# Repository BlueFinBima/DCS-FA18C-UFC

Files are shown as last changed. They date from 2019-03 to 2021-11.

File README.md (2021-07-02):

# DCS-FA18C-UFC
### This is a hardware and software project to build an Up Front Controller for the DCS F/A-18C Hornet
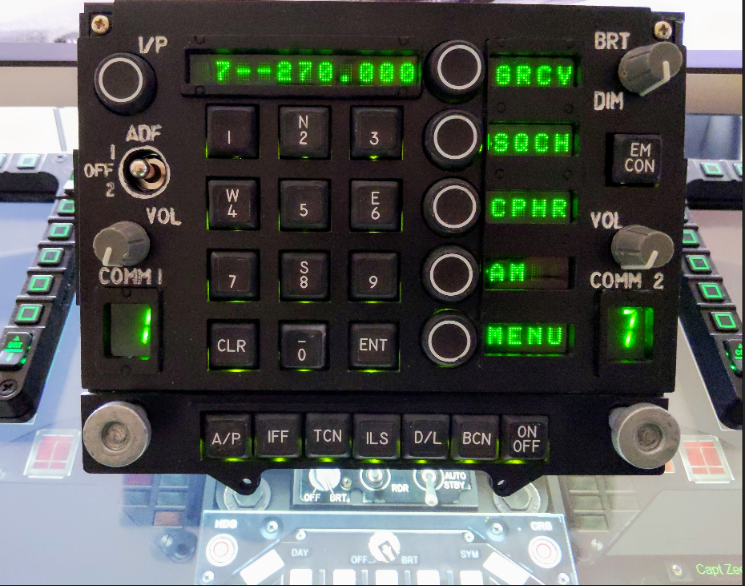
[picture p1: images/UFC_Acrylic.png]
Hornet UFC with the Early 2020 Acrylic Case

### Notes

The HT16K33 isn't too difficult to find, and can be picked up quite cheaply on AliExpress if you are prepared to wait.  The DLG2416 displays are quite expensive from 
typical vendors, however hunting around on ebay etc might result in more affordable sources.  They have a fixed character set which is unfortunate, however they remain useable and pleasing alternative to the 16 segment displays which the actual UFC requires.  If didn't manage to find suitable 16 segment displays of a physical size to work with this 
project.  The comms channel indicators are 16 segment displays (be careful not to buy 14 segment) but unfortunately I was unable to find displays which were not slanted - for me a minor issue.
* The ESP32 boards come in all sorts of shapes and sizes, and my controller board needs
a particular type of 38-pin board and I found to my cost that there were several boards with different widths.  I would expect [these boards](https://www.amazon.co.uk/AZDelivery-NodeMcu-CP2102-Development-including/dp/B074RGW2VQ/) to be the correct size.
* The green 16 segment LED displays now (2020) seem to be very hard to acquire.
* R2 and R5 on the controller board should only be installed as a last resort of the I2C is not stable without them
* The PCF8575 is a PCF8575PWR (TSSOP)
* D1 and D2 are BAT54CDW and not BAT54TW

### The Story
I would love to have a full Simpit for every aircraft – who
wouldn’t – but space / time / money all conspire against this.  I personally
feel that there is more immersion from the sensation of real switches, knobs
etc, but compromises are part of life.

I wanted a mix of virtual cockpit and some real devices so I
wrote a native F/A-18C interface for Helios, and I started a project to create
a hardware Up Front Controller.  This is what I am presenting here.   While the
3D printed UFC enclosure is very rough, hopefully you’ll get the idea of what I
am doing.  The UFC just has power going to it, and it has the potential to
drive future parts of the cockpit via i2c (I am aware of the limitations and
potential problems with the approach of using i2c, but it seems reliable in my
set up).   The UFC is controlled by an ESP32 board to get me the direct pins
and interrupts that I needed for the encoders.  Because there is only a single
power connecter to the UFC, it means that it can be removed from the set up
extremely quickly.  Likewise, the Thrustmaster Cougar MFDs are also very easy
to remove as they simply hang from the top of the screen, primarily to allow
hiding of the USB cables.  I rotated the rocker switches and 3D printed the
hangers so the MFDs sit over the top corners of the 23 inch Dell touch screen.

The UFC itself is pretty simple using DLG2416 displays (I
like the dots).  Unfortunately these do not have any programmable characters,
but the result is OK IMHO.  I would have preferred  16 and 7 segment displays,
but I could not find suitable devices.  The Comm Channel displays are 16
segment LED displays driven by the same HT16K33 that reads the keys and
switches.  Other things I would change if I ever revised the UFC design would
be to replace the 2 x volumes and the brightness knob with potentiometers and
put an i2c ADC onto the board – but I am happy enough with the encoders in the
current design that I’m not planning to do this.

I’m going to put a third Cougar MFD in for the AMPCD, but
I’m still considering how I can do this while keeping the mounting discrete.

#### 2020 Project Update
With two inidividuals (that I know of) successfully recreating this project, I chose to revisit
the facial.  I purchased a small SLA 3D printer which allowed me to print smaller key caps, and 
I was able to paint and use my 2.5W LED Laser to label these.  I also created new comm channel
selectors, as well as more harmonious knobs (ie not Mil Spec accurate) for the UFC.
My LED laser will not touch acrylic other than black, so the facia was cut from that material and 
white polystyrene sheet was then glued to the surface, and painted black.  The LED laser was then 
used to create the lettering.  While all of this is an improvement, I have to confess to not being 
very happy with this.   This is in part why the GitHub project has not been updated with these changes.
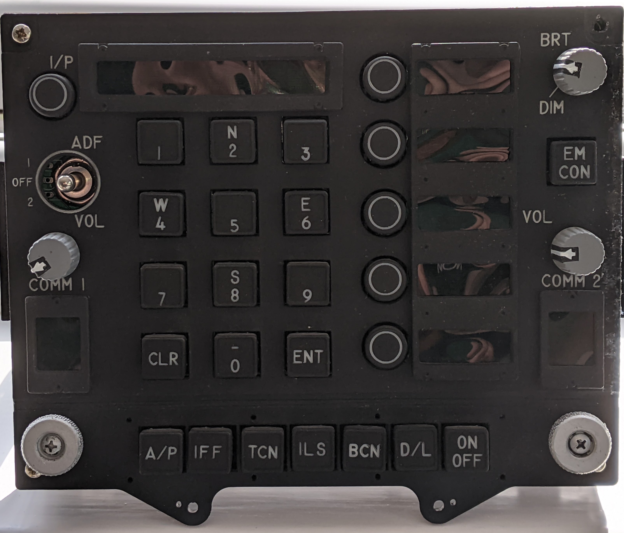
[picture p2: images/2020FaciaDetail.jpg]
Hornet UFC with Late 2020 Acrylic Facia


#### Thoughts about the future (July 2021)
Are there going to be further revisions to this project?  Well maybe.  I am considering a V3, primarily 
to see if I can improve the visuals of the displays, and to see if I can gain some level of crossover with
the AV-8B which has a similar UFC.  DLG2416's are expensive and difficult to get hold of.  16 segment LED displays
are also out of fashion, and green ones seem extremely rare.  I have created Eagle drawings for discrete 0603 / 0402
LED displays which can be charlieplexed and might be coaxed into looking like the 16-segment displays used in the 
real UFC.  I just need to finalise these plans, and pluck up the courage to use a PCBA service to build a prototype 
(I have neither the patience nor the skill to solder the volume to LEDs needed).  If I get around to getting a 
display prototyped *AND* I can work out how to make it look fit for purpose, then I will almost certainly begin
some work on a V3 of this UFC.

Controlling the very large number of LEDs will also be interesting, but I have been doing some prototyping and it does look possible.
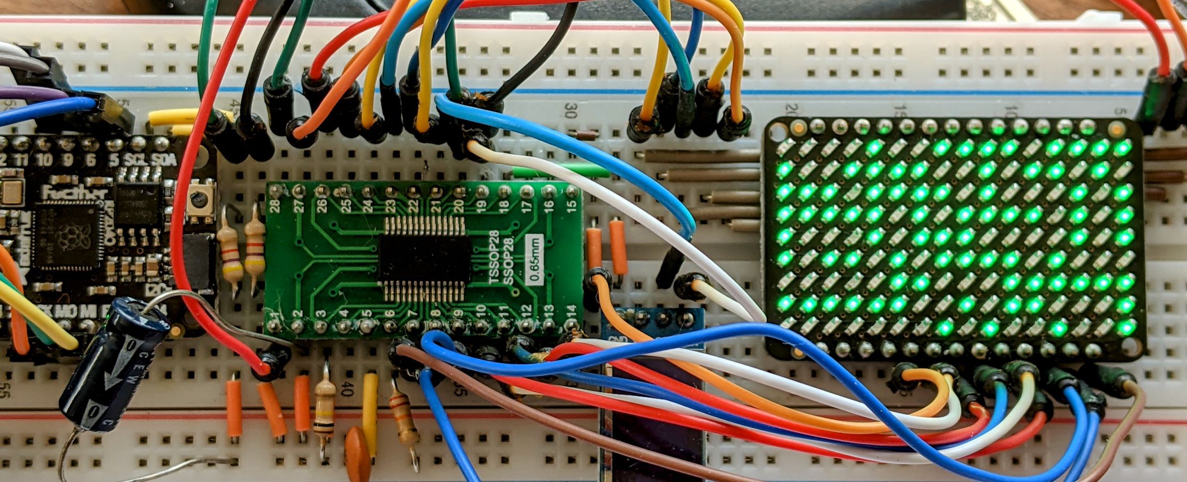
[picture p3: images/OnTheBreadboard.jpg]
Currently on the Breadboard
          

### The History of this Project

I started out many years ago with the A-10C and Loz’s
profile for Helios which was a a great place to start.  After a while, I built
a real caution panel based on the Holtek HT16K33 which was driven by an Arduino
Pro Micro which communicated via a serial connection to a c# program which
talked to DCS.  Over time, the A-10C parts grew a bit and I had CMSC, CMSP,
UFC, NMSP and a few other panels.

The EOS project was a little too complex for my needs, and
while DCS-BIOS is a fantastic option, for a number of reasons, I have chosen to
stick with my own technology.

Fast forward a few years, and the Pro Micro and c# program
were replaced by an ESP8266 with more memory so that it had the capacity to do
all of the parsing needed and the wifi communication allowed direct connection
to the DCS exports.lua.  This was later replaced by an ESP32 board.

When the Hornet came out, I decided that I again wanted to
have a hybrid Helios cockpit, but I have always taken the view that offloading
as much work from my DCS PC so that it can concentrate  resources on DCS, was a
good thing.  Since I always have access to under-utilised PCs, I wanted the
virtual cockpit to be on a remote machine like I had with the A-10C. 
Unfortunately this ruled out Capt Zeen’s Hornet profile because it uses
keyboard commands which appear on the wrong PC, and the use of the A-10C Helios
interface requires a lot of processing in the exports.lua on the DCS machine.

I’m happy to make 3D parts visible on Fusion 360 on request.  Schematics etc are
Eagle format.

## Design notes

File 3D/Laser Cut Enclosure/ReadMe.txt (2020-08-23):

These parts were fabricated from 3mm Black Acrylic and cut with a 2500 mWatt LED laser (which needed multiple passes).
The files were generally created with LightBurn, from patterns taken from the original Fusion 360 drawings.
Also the boxes were constructed from https://en.makercase.com/#/basicbox with a few tweaks.

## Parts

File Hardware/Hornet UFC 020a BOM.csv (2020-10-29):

Part;"Value";"Device";"Package";"Description";"MF";"MPN";"OC_FARNELL";"OC_NEWARK";"PACKAGE";"SPICEPREFIX";"SUPPLIER";"TP_SIGNAL_NAME";
#0;"GATERON-LED";"GATERON-LED";"GATERON-LED";"Gateron keyswitch with LED";"";"";"";"";"";"";"";"";
#1;"GATERON-LED";"GATERON-LED";"GATERON-LED";"Gateron keyswitch with LED";"";"";"";"";"";"";"";"";
#2;"GATERON-LED";"GATERON-LED";"GATERON-LED";"Gateron keyswitch with LED";"";"";"";"";"";"";"";"";
#3;"GATERON-LED";"GATERON-LED";"GATERON-LED";"Gateron keyswitch with LED";"";"";"";"";"";"";"";"";
#4;"GATERON-LED";"GATERON-LED";"GATERON-LED";"Gateron keyswitch with LED";"";"";"";"";"";"";"";"";
#5;"GATERON-LED";"GATERON-LED";"GATERON-LED";"Gateron keyswitch with LED";"";"";"";"";"";"";"";"";
#6;"GATERON-LED";"GATERON-LED";"GATERON-LED";"Gateron keyswitch with LED";"";"";"";"";"";"";"";"";
#7;"GATERON-LED";"GATERON-LED";"GATERON-LED";"Gateron keyswitch with LED";"";"";"";"";"";"";"";"";
#8;"GATERON-LED";"GATERON-LED";"GATERON-LED";"Gateron keyswitch with LED";"";"";"";"";"";"";"";"";
#9;"GATERON-LED";"GATERON-LED";"GATERON-LED";"Gateron keyswitch with LED";"";"";"";"";"";"";"";"";
74HC138;"CD74HC138M";"CD74HC138M";"SOIC127P600X175-16N";"High-Speed CMOS Logic 3- to 8-Line Decoder/Demultiplexer Inverting and Noninverting";"";"CD74HC138M";"1640756";"66F5206";"SOIC-16";"";"Texas Instruments";"";
A/P;"GATERON-LED";"GATERON-LED";"GATERON-LED";"Gateron keyswitch with LED";"";"";"";"";"";"";"";"";
ADF;"ADF";"JST-PH-B2B-SM3SOLDER";"B3B-PH-SOLDER";"JST PH Connector 2mm Pitch (3 Pin)";"";"";"";"";"";"";"";"";
BCN;"GATERON-LED";"GATERON-LED";"GATERON-LED";"Gateron keyswitch with LED";"";"";"";"";"";"";"";"";
BLANK;"";"SOLDERJUMPERCLOSED";"SOLDERJUMPER_CLOSEDWIRE";"SMD Solder JUMPER";"";"";"";"";"";"";"";"";
BRT;"ALPS_ENCODER+PUSHSWITCHLARGE_TABS";"ALPS_ENCODER+PUSHSWITCHLARGE_TABS";"ENCODER+SWITCH_LARGER_TABS";"";"";"";"";"";"";"";"";"";
C2;"100nF";"C-EUC0805";"C0805";"CAPACITOR | European symbol";"";"";"";"";"";"";"";"";
C3;"100nF";"C-EUC0805";"C0805";"CAPACITOR | European symbol";"";"";"";"";"";"";"";"";
C4;"0.1uF";"C-EUC0805";"C0805";"CAPACITOR | European symbol";"";"";"";"";"";"";"";"";
C5;"100nF";"C-EUC0805";"C0805";"CAPACITOR | European symbol";"";"";"";"";"";"";"";"";
C6;"0.1uF";"C-EUC0805";"C0805";"CAPACITOR | European symbol";"";"";"";"";"";"";"";"";
C7;"100nF";"C-EUC0805";"C0805";"CAPACITOR | European symbol";"";"";"";"";"";"";"";"";
C8;"100nF";"C-EUC0805";"C0805";"CAPACITOR | European symbol";"";"";"";"";"";"";"";"";
C9;"100nF";"C-EUC0805";"C0805";"CAPACITOR | European symbol";"";"";"";"";"";"";"";"";
C10;"100nF";"C-EUC0805";"C0805";"CAPACITOR | European symbol";"";"";"";"";"";"";"";"";
C11;"100nF";"C-EUC0805";"C0805";"CAPACITOR | European symbol";"";"";"";"";"";"";"";"";
C12;"100nF";"C-EUC0805";"C0805";"CAPACITOR | European symbol";"";"";"";"";"";"";"";"";
C13;"100nF";"C-EUC0805";"C0805";"CAPACITOR | European symbol";"";"";"";"";"";"";"";"";
CHANNEL1;"16-SEG_THROUGH_HOLEPSC05-11";"16-SEG_THROUGH_HOLEPSC05-11";"PSC05-11";"16 SEGMENT SINGLE DIGIT ALPHANUMERIC NUMERIC DISPLAY";"";"";"";"";"";"";"";"";
CHANNEL2;"16-SEG_THROUGH_HOLEPSC05-11";"16-SEG_THROUGH_HOLEPSC05-11";"PSC05-11";"16 SEGMENT SINGLE DIGIT ALPHANUMERIC NUMERIC DISPLAY";"";"";"";"";"";"";"";"";
CLR;"GATERON-LED";"GATERON-LED";"GATERON-LED";"Gateron keyswitch with LED";"";"";"";"";"";"";"";"";
CN2;"JST-PH-B4B-PH-SM4THRU-HOLE";"JST-PH-B4B-PH-SM4THRU-HOLE";"B4B-PH-SOLDER";"JST PH 4 Pin (2.00")";"";"";"";"";"";"";"";"";
D/L;"GATERON-LED";"GATERON-LED";"GATERON-LED";"Gateron keyswitch with LED";"";"";"";"";"";"";"";"";
D1;"BAT54CDW";"BAT54CDW";"SSOT6";"";"";"";"";"";"";"";"";"";
D2;"BAT54CDW";"BAT54CDW";"SSOT6";"";"";"";"";"";"";"";"";"";
D3;"";"LED3MM_V_OFFSET";"LED5X2MM_RECT_3MM_VOFFSET";"LED";"";"";"";"";"";"";"";"";
D5;"";"LED3MM_V_OFFSET";"LED5X2MM_RECT_3MM_VOFFSET";"LED";"";"";"";"";"";"";"";"";
D7;"";"LED3MM_V_OFFSET";"LED5X2MM_RECT_3MM_VOFFSET";"LED";"";"";"";"";"";"";"";"";
D9;"";"LED3MM_V_OFFSET";"LED5X2MM_RECT_3MM_VOFFSET";"LED";"";"";"";"";"";"";"";"";
D11;"";"LED3MM_V_OFFSET";"LED5X2MM_RECT_3MM_VOFFSET";"LED";"";"";"";"";"";"";"";"";
DIS1;"HDLX2416SOCKETED";"HDLX2416SOCKETED";"HDLX2416(SOCKETED)";"LED DISPLAY";"";"";"";"";"";"";"";"";
DIS2;"HDLX2416SOCKETED";"HDLX2416SOCKETED";"HDLX2416(SOCKETED)";"LED DISPLAY";"";"";"";"";"";"";"";"";
DIS3;"HDLX2416SOCKETED";"HDLX2416SOCKETED";"HDLX2416(SOCKETED)";"LED DISPLAY";"";"";"";"";"";"";"";"";
EMCON;"GATERON-LED";"GATERON-LED";"GATERON-LED";"Gateron keyswitch with LED";"";"";"";"";"";"";"";"";
ENC_1;"JST-PH-B4B-PH-SM4THRU-HOLE";"JST-PH-B4B-PH-SM4THRU-HOLE";"B4B-PH-SOLDER";"JST PH 4 Pin (2.00")";"";"";"";"";"";"";"";"";
ENT;"GATERON-LED";"GATERON-LED";"GATERON-LED";"Gateron keyswitch with LED";"";"";"";"";"";"";"";"";
I/P;"GATERON-LED";"GATERON-LED";"GATERON-LED";"Gateron keyswitch with LED";"";"";"";"";"";"";"";"";
IFF;"GATERON-LED";"GATERON-LED";"GATERON-LED";"Gateron keyswitch with LED";"";"";"";"";"";"";"";"";
ILS;"GATERON-LED";"GATERON-LED";"GATERON-LED";"Gateron keyswitch with LED";"";"";"";"";"";"";"";"";
ODU1;"GATERON-LED";"GATERON-LED";"GATERON-LED";"Gateron keyswitch with LED";"";"";"";"";"";"";"";"";
ODU2;"GATERON-LED";"GATERON-LED";"GATERON-LED";"Gateron keyswitch with LED";"";"";"";"";"";"";"";"";
ODU3;"GATERON-LED";"GATERON-LED";"GATERON-LED";"Gateron keyswitch with LED";"";"";"";"";"";"";"";"";
ODU4;"GATERON-LED";"GATERON-LED";"GATERON-LED";"Gateron keyswitch with LED";"";"";"";"";"";"";"";"";
ODU5;"GATERON-LED";"GATERON-LED";"GATERON-LED";"Gateron keyswitch with LED";"";"";"";"";"";"";"";"";
ODU_DSP_1;"HDLX2416SOCKETED";"HDLX2416SOCKETED";"HDLX2416(SOCKETED)";"LED DISPLAY";"";"";"";"";"";"";"";"";
ODU_DSP_2;"HDLX2416SOCKETED";"HDLX2416SOCKETED";"HDLX2416(SOCKETED)";"LED DISPLAY";"";"";"";"";"";"";"";"";
ODU_DSP_3;"HDLX2416SOCKETED";"HDLX2416SOCKETED";"HDLX2416(SOCKETED)";"LED DISPLAY";"";"";"";"";"";"";"";"";
ODU_DSP_4;"HDLX2416SOCKETED";"HDLX2416SOCKETED";"HDLX2416(SOCKETED)";"LED DISPLAY";"";"";"";"";"";"";"";"";
ODU_DSP_5;"HDLX2416SOCKETED";"HDLX2416SOCKETED";"HDLX2416(SOCKETED)";"LED DISPLAY";"";"";"";"";"";"";"";"";
ON/OFF;"GATERON-LED";"GATERON-LED";"GATERON-LED";"Gateron keyswitch with LED";"";"";"";"";"";"";"";"";
R1;"39K";"R-EU_R1206";"R1206";"RESISTOR | European symbol";"";"";"";"";"";"R";"";"";
R2;"10K";"R-EU_R0805";"R0805";"RESISTOR | European symbol";"";"";"";"";"";"R";"";"";
R5;"";"R-EU_R0805";"R0805";"RESISTOR | European symbol";"";"";"";"";"";"R";"";"";
R7;"";"R-EU_R0805";"R0805";"RESISTOR | European symbol";"";"";"";"";"";"R";"";"";
R9;"";"R-EU_R0805";"R0805";"RESISTOR | European symbol";"";"";"";"";"";"R";"";"";
R10;"";"R-EU_R0805";"R0805";"RESISTOR | European symbol";"";"";"";"";"";"R";"";"";
R11;"";"R-EU_R0805";"R0805";"RESISTOR | European symbol";"";"";"";"";"";"R";"";"";
R12;"";"R-EU_R0805";"R0805";"RESISTOR | European symbol";"";"";"";"";"";"R";"";"";
R14;"10K";"R-EU_R0805";"R0805";"RESISTOR | European symbol";"";"";"";"";"";"R";"";"";
R49;"39K";"R-EU_R1206";"R1206";"RESISTOR | European symbol";"";"";"";"";"";"R";"";"";
R50;"39K";"R-EU_R1206";"R1206";"RESISTOR | European symbol";"";"";"";"";"";"R";"";"";
R51;"39K";"R-EU_R1206";"R1206";"RESISTOR | European symbol";"";"";"";"";"";"R";"";"";
R52;"39K";"R-EU_R1206";"R1206";"RESISTOR | European symbol";"";"";"";"";"";"R";"";"";
R53;"39K";"R-EU_R1206";"R1206";"RESISTOR | European symbol";"";"";"";"";"";"R";"";"";
R54;"39K";"R-EU_R1206";"R1206";"RESISTOR | European symbol";"";"";"";"";"";"R";"";"";
R55;"39K";"R-EU_R1206";"R1206";"RESISTOR | European symbol";"";"";"";"";"";"R";"";"";
R56;"39K";"R-EU_R1206";"R1206";"RESISTOR | European symbol";"";"";"";"";"";"R";"";"";
R57;"39K";"R-EU_R1206";"R1206";"RESISTOR | European symbol";"";"";"";"";"";"R";"";"";
R58;"39K";"R-EU_R1206";"R1206";"RESISTOR | European symbol";"";"";"";"";"";"R";"";"";
R59;"39K";"R-EU_R1206";"R1206";"RESISTOR | European symbol";"";"";"";"";"";"R";"";"";
R60;"39K";"R-EU_R1206";"R1206";"RESISTOR | European symbol";"";"";"";"";"";"R";"";"";
SV2;"";"MA20-2";"MA20-2";"PIN HEADER";"";"";"unknown";"unknown";"";"";"";"";
SW1;"ADF_SMALL";"MICRO_TOGGLE_SPDT_TOP";"MICRO_TOGGLE_SPDT";"";"";"";"";"";"";"";"";"";
TCN;"GATERON-LED";"GATERON-LED";"GATERON-LED";"Gateron keyswitch with LED";"";"";"";"";"";"";"";"";
TP1;"PTR1TP13SQ";"PTR1TP13SQ";"TP13SQ";"TEST PIN";"";"";"";"";"";"";"";"";
TP2;"PTR1TP13SQ";"PTR1TP13SQ";"TP13SQ";"TEST PIN";"";"";"";"";"";"";"";"";
TP3;"PTR1TP13SQ";"PTR1TP13SQ";"TP13SQ";"TEST PIN";"";"";"";"";"";"";"";"";
TP4;"PTR1TP13SQ";"PTR1TP13SQ";"TP13SQ";"TEST PIN";"";"";"";"";"";"";"";"";
U$4;"ENC_RGB_L";"ENCODER_RGB_SWITCHTHROUGHHOLE";"ENCODER_RGB";"RGB Switched Rotary Encoder With Switch EC12PRGBSDVBF-D-25K-24-24C-6108-6H";"";"";"";"";"";"";"";"";
U$5;"ALPS_ENCODER+PUSHSWITCHLARGE_TABS";"ALPS_ENCODER+PUSHSWITCHLARGE_TABS";"ENCODER+SWITCH_LARGER_TABS";"";"";"";"";"";"";"";"";"";
U$7;"PCF8575PTSSOP24";"PCF8575PTSSOP24";"TSSOP24";"";"";"";"";"";"";"";"";"";
U$11;"ENC_RGB_R";"ENCODER_RGB_SWITCHTHROUGHHOLE";"ENCODER_RGB";"RGB Switched Rotary Encoder With Switch EC12PRGBSDVBF-D-25K-24-24C-6108-6H";"";"";"";"";"";"";"";"";
U$21;"ALPS_ENCODER+PUSHSWITCHLARGE_TABS";"ALPS_ENCODER+PUSHSWITCHLARGE_TABS";"ENCODER+SWITCH_LARGER_TABS";"";"";"";"";"";"";"";"";"";
U$31;"Addr 0x71";"HOLTEK_HT16K33";"SOIC28";"Holtek HT16K33RAM Mapping 16*8 LED Controller Driver with keyscanOrigianlly tested with the AdaFruit breakout board | the chip is described here.";"";"";"";"";"";"";"";"";
U$37;"OLED_128X32_I2C_DISPLAYMODULE";"OLED_128X32_I2C_DISPLAYMODULE";"OLED128X32_GRAPHICS_MODULE";"";"";"";"";"";"";"";"";"";
VOL1;"ALPS_ENCODER+PUSHSWITCHLARGE_TABS";"ALPS_ENCODER+PUSHSWITCHLARGE_TABS";"ENCODER+SWITCH_LARGER_TABS";"";"";"";"";"";"";"";"";"";
VOL2;"ALPS_ENCODER+PUSHSWITCHLARGE_TABS";"ALPS_ENCODER+PUSHSWITCHLARGE_TABS";"ENCODER+SWITCH_LARGER_TABS";"";"";"";"";"";"";"";"";"";

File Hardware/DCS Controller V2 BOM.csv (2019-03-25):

Part | Value | Device | Package | Description | MF | MPN | OC_FARNELL | OC_NEWARK | SPICEPREFIX
5VADJUST1 |  | SJ | SJ | SMD solder JUMPER
BUCK_BYPAS |  | SJ | SJ | SMD solder JUMPER
C15 | 10uF | CAP_CERAMIC0805-NOOUTLINE | 0805-NO | Ceramic Capacitors
I2C_0 | JST-PH-B4B-PH-SM4THRU-HOLE | JST-PH-B4B-PH-SM4THRU-HOLE | B4B-PH-SOLDER | JST PH 4 Pin (2.00)"
I2C_1 | JST-PH-B4B-PH-SM4THRU-HOLE | JST-PH-B4B-PH-SM4THRU-HOLE | B4B-PH-SOLDER | JST PH 4 Pin (2.00)"
I2C_2 | JST-PH-B4B-PH-SM4THRU-HOLE | JST-PH-B4B-PH-SM4THRU-HOLE | B4B-PH-SOLDER | JST PH 4 Pin (2.00)"
I2C_3 | JST-PH-B4B-PH-SM4THRU-HOLE | JST-PH-B4B-PH-SM4THRU-HOLE | B4B-PH-SOLDER | JST PH 4 Pin (2.00)"
I2C_4 | JST-PH-B4B-PH-SM4THRU-HOLE | JST-PH-B4B-PH-SM4THRU-HOLE | B4B-PH-SOLDER | JST PH 4 Pin (2.00)"
I2C_5 | JST-PH-B4B-PH-SM4THRU-HOLE | JST-PH-B4B-PH-SM4THRU-HOLE | B4B-PH-SOLDER | JST PH 4 Pin (2.00)"
I2C_6 | JST-PH-B4B-PH-SM4THRU-HOLE | JST-PH-B4B-PH-SM4THRU-HOLE | B4B-PH-SOLDER | JST PH 4 Pin (2.00)"
I2C_7 | JST-PH-B4B-PH-SM4THRU-HOLE | JST-PH-B4B-PH-SM4THRU-HOLE | B4B-PH-SOLDER | JST PH 4 Pin (2.00)"
I2C_MSTR |  | I2C_JST_CONNECTORTHROUGH_HOLE | B4B-PH-SOLDER
J1 |  | JACK-PLUG0 | SPC4077 | DC POWER JACK |  |  | unknown | unknown
MISO |  | 1,6/0,9 | 1,6/0,9 | THROUGH-HOLE PAD
MLF1 | ATTINY1634MLF20 | ATTINY1634MLF20 | MLF20
MOSI |  | 1,6/0,9 | 1,6/0,9 | THROUGH-HOLE PAD
PB3 |  | 1,6/0,9 | 1,6/0,9 | THROUGH-HOLE PAD
Q4 | BSS138 | MOSFET-NCHANNELSMD | SOT23-3
Q5 | BSS138 | MOSFET-NCHANNELSMD | SOT23-3
Q6 | BSS138 | MOSFET-NCHANNELSMD | SOT23-3
R2 | 4K7 | R-EU_R0805 | R0805 | RESISTOR, European symbol |  |  |  |  | R
R5 | 4K7 | R-EU_R0805 | R0805 | RESISTOR, European symbol |  |  |  |  | R
R7 | 10K | RESISTOR0603-RES | 0603-RES | Resistor
R9 | 10K | RESISTOR0603-RES | 0603-RES | Resistor
R10 | 10K | RESISTOR0603-RES | 0603-RES | Resistor
R11 | 10K | RESISTOR0603-RES | 0603-RES | Resistor
R14 | 10K | RESISTOR0603-RES | 0603-RES | Resistor
R16 | 10K | RESISTOR0603-RES | 0603-RES | Resistor
RST |  | 1,6/0,9 | 1,6/0,9 | THROUGH-HOLE PAD
RX |  | 1,6/0,9 | 1,6/0,9 | THROUGH-HOLE PAD
SCK |  | 1,6/0,9 | 1,6/0,9 | THROUGH-HOLE PAD
SV1 |  | FE20-2 | FE20-2 | FEMALE HEADER |  |  | unknown | unknown
TX |  | 1,6/0,9 | 1,6/0,9 | THROUGH-HOLE PAD
U$26 | EBAY_BUCK_CONVERTERMODULE | EBAY_BUCK_CONVERTERMODULE | BUCK_CONVERTER
U$34 | ESP32DEVKITC | ESP32DEVKITC | ESP32-DEVKITC
U2 | Addr 0x70 | TCA9548A | TSSOP24 | TCA9548A I2C Multiplexer |  |  |  |  | X

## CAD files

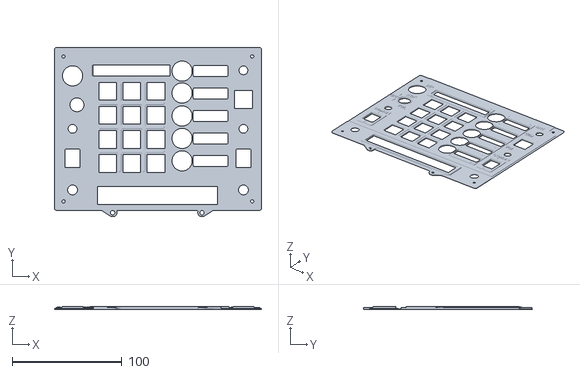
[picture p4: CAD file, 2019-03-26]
3D/3D Printed Enclosure/Hornet UFC Facia.stl
189.0 x 154.7 x 2.60

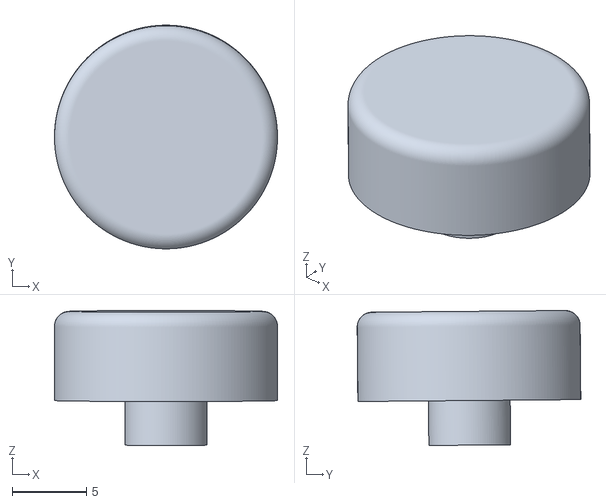
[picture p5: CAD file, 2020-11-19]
3D/Hornet UFC Round Key large.stl
15.0 x 15.0 x 9.08

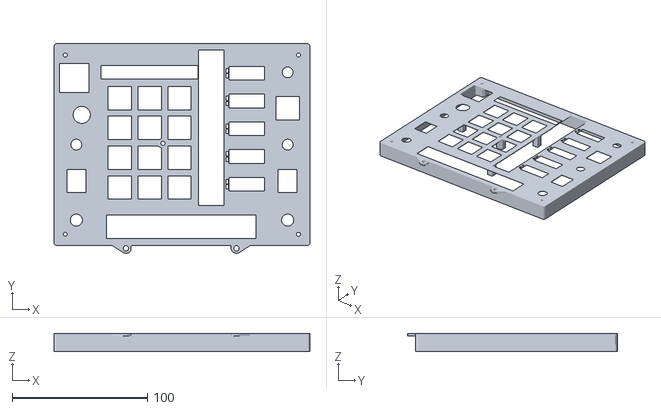
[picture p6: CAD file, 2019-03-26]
3D/3D Printed Enclosure/Hornet UFC Frame.stl
189.0 x 154.7 x 13.5

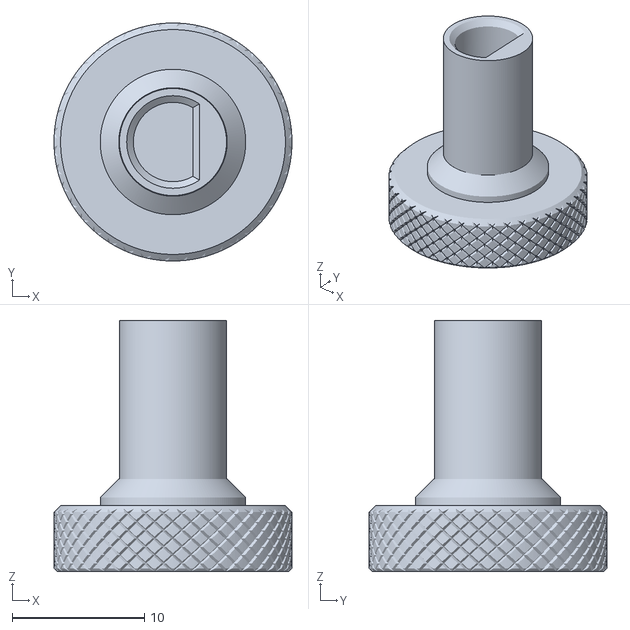
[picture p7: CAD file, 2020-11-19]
3D/Comm Channel Selector Knurled.stl
18.0 x 18.0 x 19.0

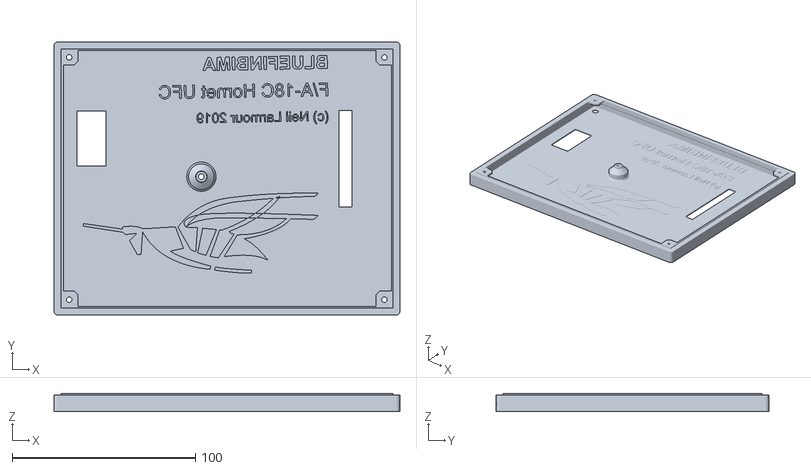
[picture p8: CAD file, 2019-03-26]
3D/3D Printed Enclosure/Hornet UFC Back.stl
189.0 x 149.0 x 10.0

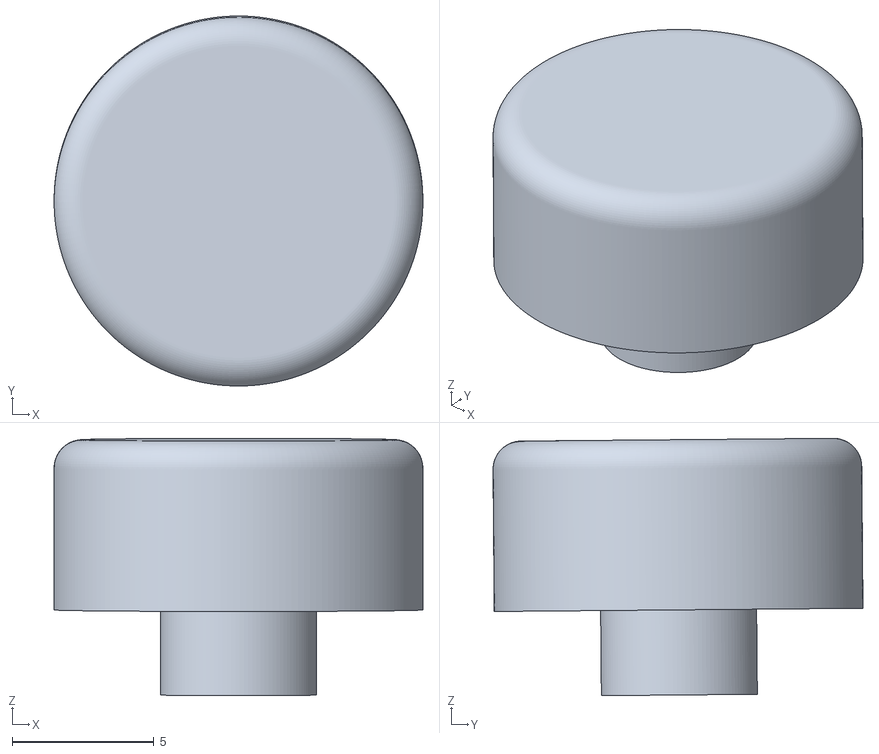
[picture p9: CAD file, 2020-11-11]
3D/Hornet UFC Round Key.stl
13.0 x 13.0 x 9.07

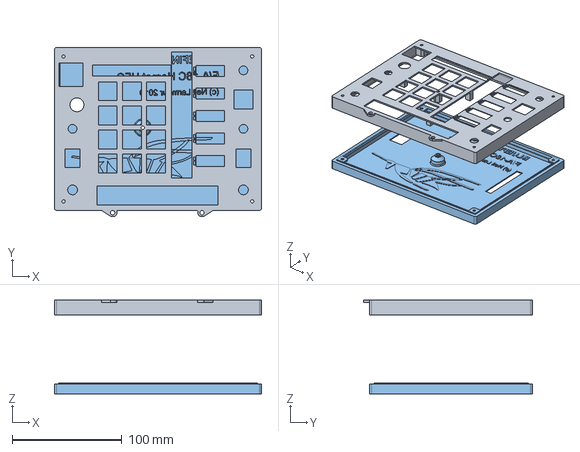
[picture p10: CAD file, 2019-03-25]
3D/3D Printed Enclosure/Hornet UFC PCB Frame v11.step
189.0 x 154.7 x 85.5 mm

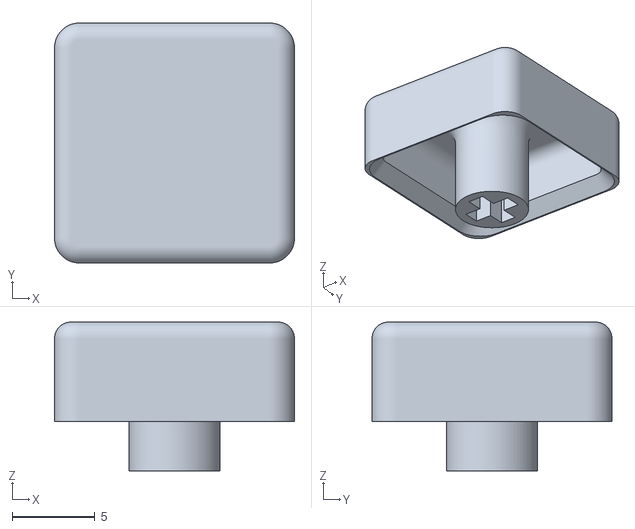
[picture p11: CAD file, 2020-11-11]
3D/Hornet UFC Square Key.stl
14.5 x 14.5 x 9.00

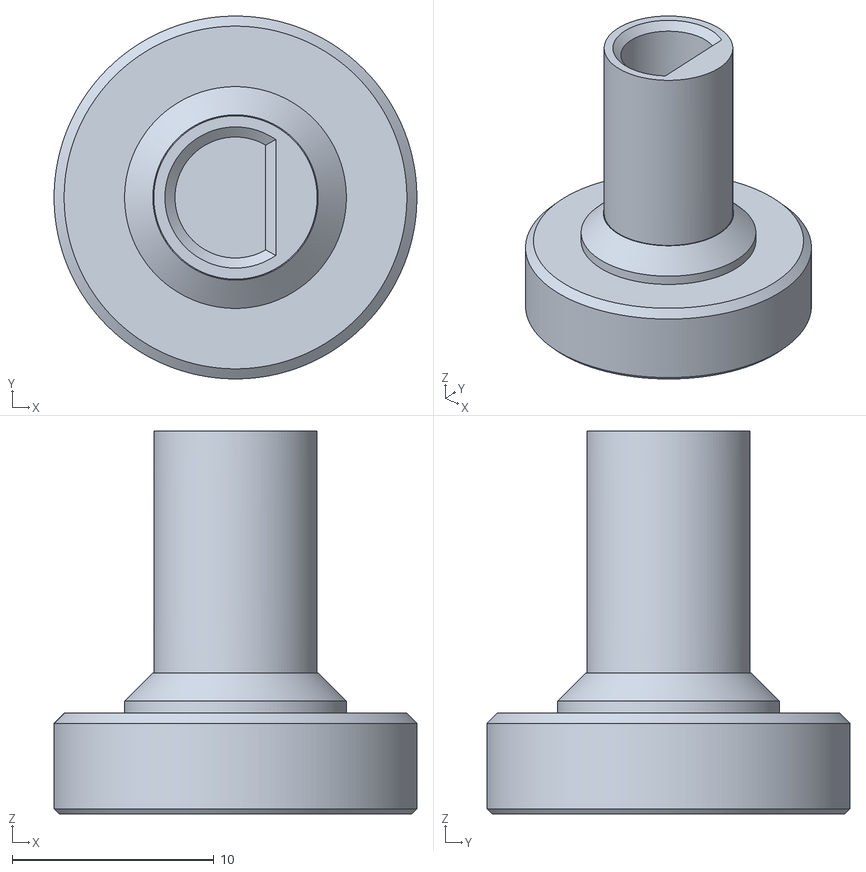
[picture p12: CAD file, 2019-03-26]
3D/Comm Channel Selector.stl
18.0 x 18.0 x 19.0

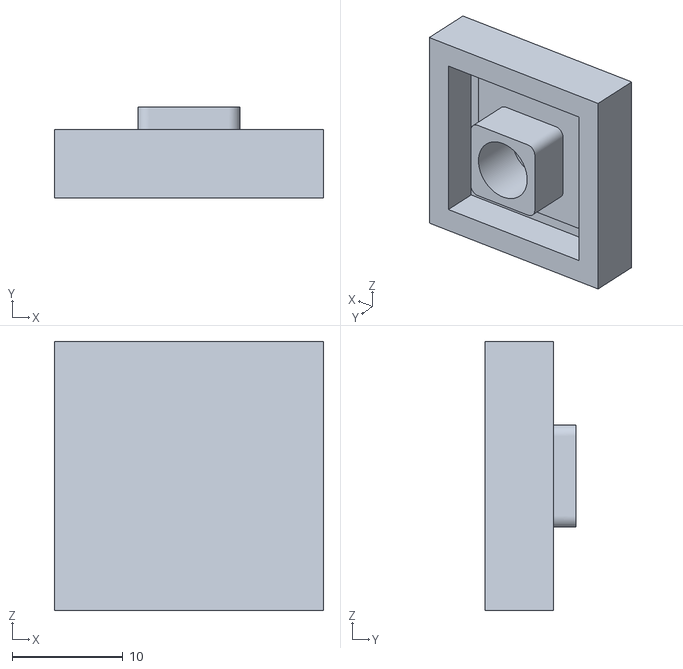
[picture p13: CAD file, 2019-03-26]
3D/Keycap Mitre v3.stl
24.3 x 8.20 x 24.3

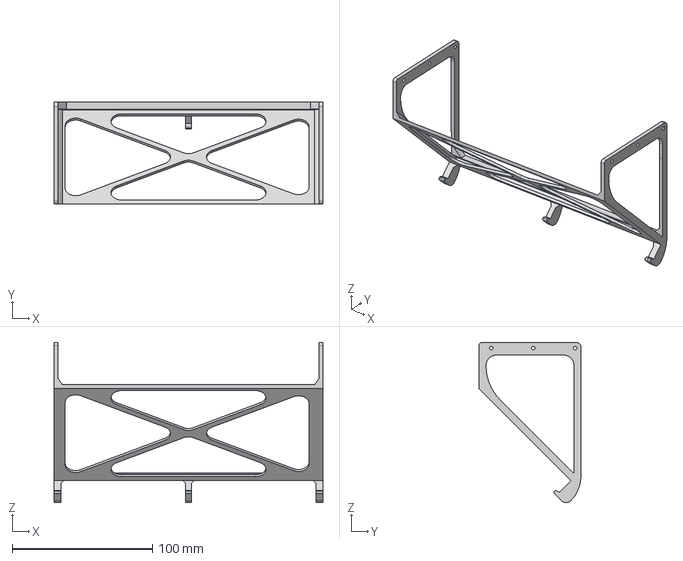
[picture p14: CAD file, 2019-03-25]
3D/UFC Screen Mounting Frame v2.step
192.0 x 72.7 x 114.2 mm

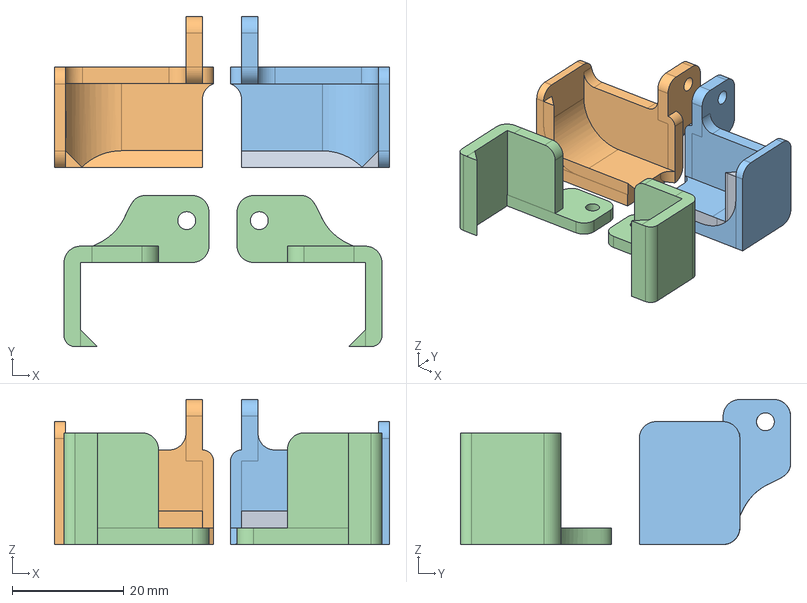
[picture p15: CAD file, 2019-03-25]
3D/MFD Brackets v2.step
60.0 x 59.2 x 26.0 mm

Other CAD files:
3D/3D Printed Enclosure/Hornet UFC 020 Test 3 v14.step
3D/3D Printed Enclosure/Hornet UFC 020 Test 3 v14.stl
3D/3D Printed Enclosure/Hornet UFC PCB Frame v11.stl
3D/MFD Brackets v2.stl
3D/UFC Screen Mounting Frame v2.stl

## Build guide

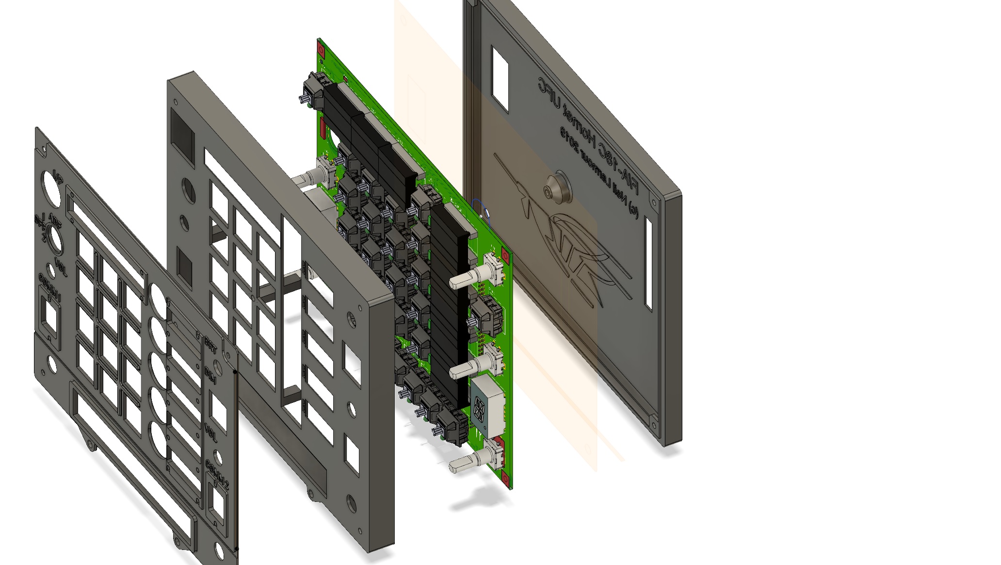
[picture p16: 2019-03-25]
3D/3D Printed Enclosure/UFC Model Picture.jpg

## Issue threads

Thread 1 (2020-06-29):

opening with Fusion

flyn28261, 2020-06-29:
Can you please make the parts available on fusion. I keep getting errors when I open the circuit boards and the 3D parts seem to be the wrong size.

BlueFinBima, 2020-08-23:
@flyn28261 apologies, I've just seen this.  What ID are you using on Fusion, and I'll make the parts available to you.

Closed 2021-11-02.

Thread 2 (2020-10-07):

Interested in trying this project

psjshep, 2020-10-07:
Hi,
  I couldn't find any way in contacting you other than here...

I want to attempt this project as it looks extremely interesting...

I have very limited 3D experience but have used a Creality 3 Pro for about 8 months. I do have a Fusion360 login.

I have limited electronics knowledge but I can solder well & can follow instructions.

I have a programming background, working in industry for about 30 yrs....

If it is easier to take this onto email, that would suit me better....

Thanks,
Phil

Kerube, 2020-10-07:
Hi
Same here, I have completed the electronics assembly of the board but have a few questions regarding the values of R9,7,5,10,11,12 I could not find the values anywhere so I placed 0 ohms resistors for the time being.
I have not powered the board yet, and I think I will have a few questions on the software loading.
Hope to hear from you.

Regards

BlueFinBima, 2020-10-09:
Hi Phil, Thanks for reaching out.  From your reply times, would I be correct that you are in the UK?

psjshep, 2020-10-09:
Hi

Yep... just north of Peterborough

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

--
Regards,
Phil

psjshep, 2020-10-09:
fyi... my email is

psjshep@googlemail.com

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

--
Regards,
Phil

BlueFinBima, 2020-10-09:
I am happy to share the 3D models, but will confess that over the summer I replaced all of the 3D printed enclosure with acrylic. You have a much better 3D printer than I do, so maybe your results will be better than mine.
With the changes to Fusion 360 Licensing which came in this month, I'm not sure if I will be able to share, but if you let me know your Fusion360 ID, I'll attempt to share the models.

psjshep, 2020-10-09:
my fusion a/c is

psjshep

Thanks,
Phil

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

--
Regards,
Phil

Closed 2021-11-02.

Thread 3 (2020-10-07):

UFC build

Kerube, 2020-10-07:
Hi
Same here, did no find a way to contact you.
I have completed the electronics assembly of the board but have a few questions regarding the values of R9,7,5,10,11,12 I could not find the values anywhere so I placed 0 ohms resistors for the time being.
I have not powered the board yet, and I think I will have a few questions on the software loading.
Hope to hear from you.

Regards

psjshep, 2020-10-07:
I'd be very interested to know how you completed the electronics assembly in great detail....

Phil

Kerube, 2020-10-08:
Hi Phil
I sent the boards to be built in China using the fabrication files provided.
I ordered the parts online from different vendors. Had a hard time finding the HOLTEK HT16K33 chip by itself, ended up buying the Adafuit board and removing the chip to use it on the UFC.
Purchased the Gateron switches and added the green LEDs, I recommend you try to find them with the LEDs, it will save you some time.
In overall assembling the board is easy. I am just waiting to find out the values of he resistors listed above, after that I will power it up and try to load the software. Hopefully it will work as planned.

psjshep, 2020-10-08:
Thanks for that - appreciated

Phil

psjshep, 2020-10-08:
To clarify in my mind, you are referring to Resistors R5,7,9,10,11 & 12 on the UFC board, not the DCS controller...

(I couldn't find their values in the CSV Bill of Materials file Hornet UFC 020a BOM.csv)

Phil

Kerube, 2020-10-08:
Correct. I found some online schematics show that those resistors range from 100 to 150 ohms. and 10k for the encoder pull up. I will try those values this weekend and see how it goes.

psjshep, 2020-10-08:
Good luck... keep us posted

Phil

psjshep, 2020-10-08:
I'm not sure if this is the answer to your resistor query... but when I opened the files in the Eagle program for the UFC board...
- There's a "Manufacture" area on the RHS...
- "Cam..." button to launch CAM
- Assembly on LHS -> Pick & Place -> export file -> dump into some temporary directory on your desktop...

Inside the <dir>\CAMOutputs\assembly is a CSV file PnP_DCS Controller V2_front.csv

5VADJUST1 | 72.39 | 15.24 | 90 |   | SJ
-- | -- | -- | -- | -- | --
BUCK_BYPAS | 80.01 | 33.02 | 270 |   | SJ
C15 | 12.07 | 29.72 | 0 | 10uF | 0805-NO
Q4 | 12.75 | 19.05 | 270 | BSS138 | SOT23-3
Q5 | 12.75 | 15.24 | 270 | BSS138 | SOT23-3
Q6 | 5.08 | 19.1 | 0 | BSS138 | SOT23-3
R10 | 10.16 | 15.24 | 270 | 10K | 0603-RES
R11 | 15.24 | 16.51 | 270 | 10K | 0603-RES
R14 | 5.08 | 16.51 | 0 | 10K | 0603-RES
R16 | 6.35 | 21.59 | 180 | 10K | 0603-RES
R2 | 10.16 | 43.18 | 180 | 4K7 | R0805
R5 | 10.16 | 40.64 | 180 | 4K7 | R0805
R7 | 10.16 | 19.05 | 270 | 10K | 0603-RES
R9 | 15.24 | 20.32 | 270 | 10K | 0603-RES
U2 | 12.07 | 34.4 | 90 | Addr 0x70 | TSSOP24

Could those be the values, bearing in mind I have no idea what I'm doing in that prog LOL ?

Phil

Kerube, 2020-10-08:
cool, the values are there, I don't get to see them when I open the excel file.
Nice

Thanks Phil
God job.

psjshep, 2020-10-08:
note the edit :(

BlueFinBima, 2020-10-09:
Sorry for ignoring you (not deliberately).  Once I find my eagle VM, I'll take a look for values.  Failing that, I'll open up a UFC and take a look ;-)

BlueFinBima, 2020-10-09:
OK, Resistors R5,7,9,10,11 & 12 are for the RGB LEDs if you're using them.  https://www.allaboutcircuits.com/tools/led-resistor-calculator/ .  I didn't use the RGB encoder in the end , so I'm pretty sure that I went 0R and let the driving pin and LED limit the LED current.  I'll add a PDF of the schematic to the repo.

psjshep, 2020-10-09:
nice 1 - thank you....

Phil

Kerube, 2020-10-09:
Ah, good.
Thank you BlueFin.
I will finish assembling he controller board soon and then I should be able to load the software and start getting to work.

Regards

BlueFinBima, 2020-10-09:
@Kerube Yes 10K on the encoder pull-ups.  Aliexpress provided my HT16K33's (slow and cheap) but my prototyping IC came from Adafruit, just like yours.  If you want to, let me know your email address, and I can invite you to a Slack channel if more communication is useful.

Kerube, 2020-10-09:
thank you so much.
Here is my email
kerube23@gmail.com

BlueFinBima, 2020-10-09:
Closing.. moved discussion to slack

Closed 2020-10-09.

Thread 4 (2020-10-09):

GND Problems with the V2 board

BlueFinBima, 2020-10-09:
1. Pin Header - Pin 2is not linked to GND and needs to be.
2. Net N$1 should be GND

BlueFinBima, 2020-10-09:
@psjshep Phill, please be aware of this issue

psjshep, 2020-10-09:
yeah - I saw the note on the schematic notes.... thx for highlighting...

Phil

psjshep, 2020-10-09:
Before I embark on the journey of sorting out manufacturing..... I don't
suppose you have any spare boards? Obviously I am happy to cover the cost
of them + postage.....

Phil

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

--
Regards,
Phil

BlueFinBima, 2020-10-09:
@kerube please be aware of this issue.

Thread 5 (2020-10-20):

Schematic claims PCF8575C with a TSSOP24 footprint which is incorrect

BlueFinBima, 2020-10-20:
Pretty sure the part should be PCF8575PWR which is really a TSSOP24 footprint.

BlueFinBima, 2020-10-29:
Addressed in https://github.com/BlueFinBima/DCS-FA18C-UFC/commit/52770f85ee627529ae390bc7ea0964aa683c71f6

Closed 2020-10-29.

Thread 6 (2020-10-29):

Diodes Specified on Schematic are incorrect

BlueFinBima, 2020-10-29:
Diodes D1 and D2 should be BAT54CDW and *not* BAT54TW

BlueFinBima, 2020-10-29:
So the quick fix for this is rotate the BAT54TW for D1 by 180 degrees, and use two BAT54TW's for D2.  The first BAT54TW has pins 3&4 soldered to pads 1&6 and the second BAT54TW has pin3 soldered to pad 4 and pin 4 soldered to pad 3.  Does that make sense?

BlueFinBima, 2020-10-29:
Addressed in https://github.com/BlueFinBima/DCS-FA18C-UFC/commit/52770f85ee627529ae390bc7ea0964aa683c71f6

Closed 2020-10-29.

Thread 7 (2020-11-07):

UFC displays pww0w instead of error in the UFC scratchpad

BlueFinBima, 2020-11-07:
DCS actually sends "pww0w" instead of "EAA0A" (the seven segment equivalent of "error").  Either way, the word "ERROR" should appear on the UFC,

BlueFinBima, 2020-11-07:
Fixing in exports for now, but if there is more text which needs special case handling, then this will need to be revisited.

BlueFinBima, 2020-11-07:
Fixed

Closed 2020-11-07.

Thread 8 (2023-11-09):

Building for VR only

dwizle81, 2023-11-09:
Great job planning on using your plans to build my own UFC.
My issue I only fly in VR so the displays and the backlight are a high priority for me
So can I build it without including those features will the buttons and switches still work?
or should I redo the PCB for an Arduino?

BlueFinBima, 2023-11-09:
Hi,  I can't think of any reason why operation would be changed if the
displays and LEDs were omitted.  Probably a bunch of other components can
be removed as well.

Good luck with the build.

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

dwizle81, 2023-11-10:
> Hi, I can't think of any reason why operation would be changed if the displays and LEDs were omitted. Probably a bunch of other components can be removed as well. Good luck with the build.
> […](#)

a couple  more questions
do you still have the part numbers for the 2 lower 8pin encoders you use seems the BOM is corrupted  or compatible with digikey or https://easyeda.com/

BlueFinBima, 2023-11-10:
As best I can tell, they are ALPS  EC11E18244A5

dwizle81, 2023-12-19:
Keep getting a compilation error using IDE 2.2.1

Compilation error: 'IotWebConfParameter' does not name a type; did you mean 'IotWebConfParameter_h'?

IotWebConf iotWebConf(apName, &dnsServer, &server, wifiInitialApPassword, CONFIG_VERSION);
IotWebConfParameter ipAddressParam("IP address", "ipAddress", ipAddressValue, STRING_LEN, "text", NULL, "10.1.1.48");
IotWebConfParameter gatewayParam("Gateway", "gateway", gatewayValue, STRING_LEN, "text", NULL, "10.1.1.1");
IotWebConfParameter netmaskParam("Subnet mask", "netmask", netmaskValue, STRING_LEN, "text", NULL, "255.255.255.0");

any ideas on how to fix??

BlueFinBima, 2023-12-20:
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

I have not touched this code in a very long time.  I do remember that IotWebConf package was a challenge because it kept changing, so it is possible, that it kept on moving after my last compilation.  All I can suggest is to look at the documentation & examples for the level of the package you're using, and modify the source accordingly.  I think trying to pick a historical level of the package which allows this to compile is probably going to take you longer.

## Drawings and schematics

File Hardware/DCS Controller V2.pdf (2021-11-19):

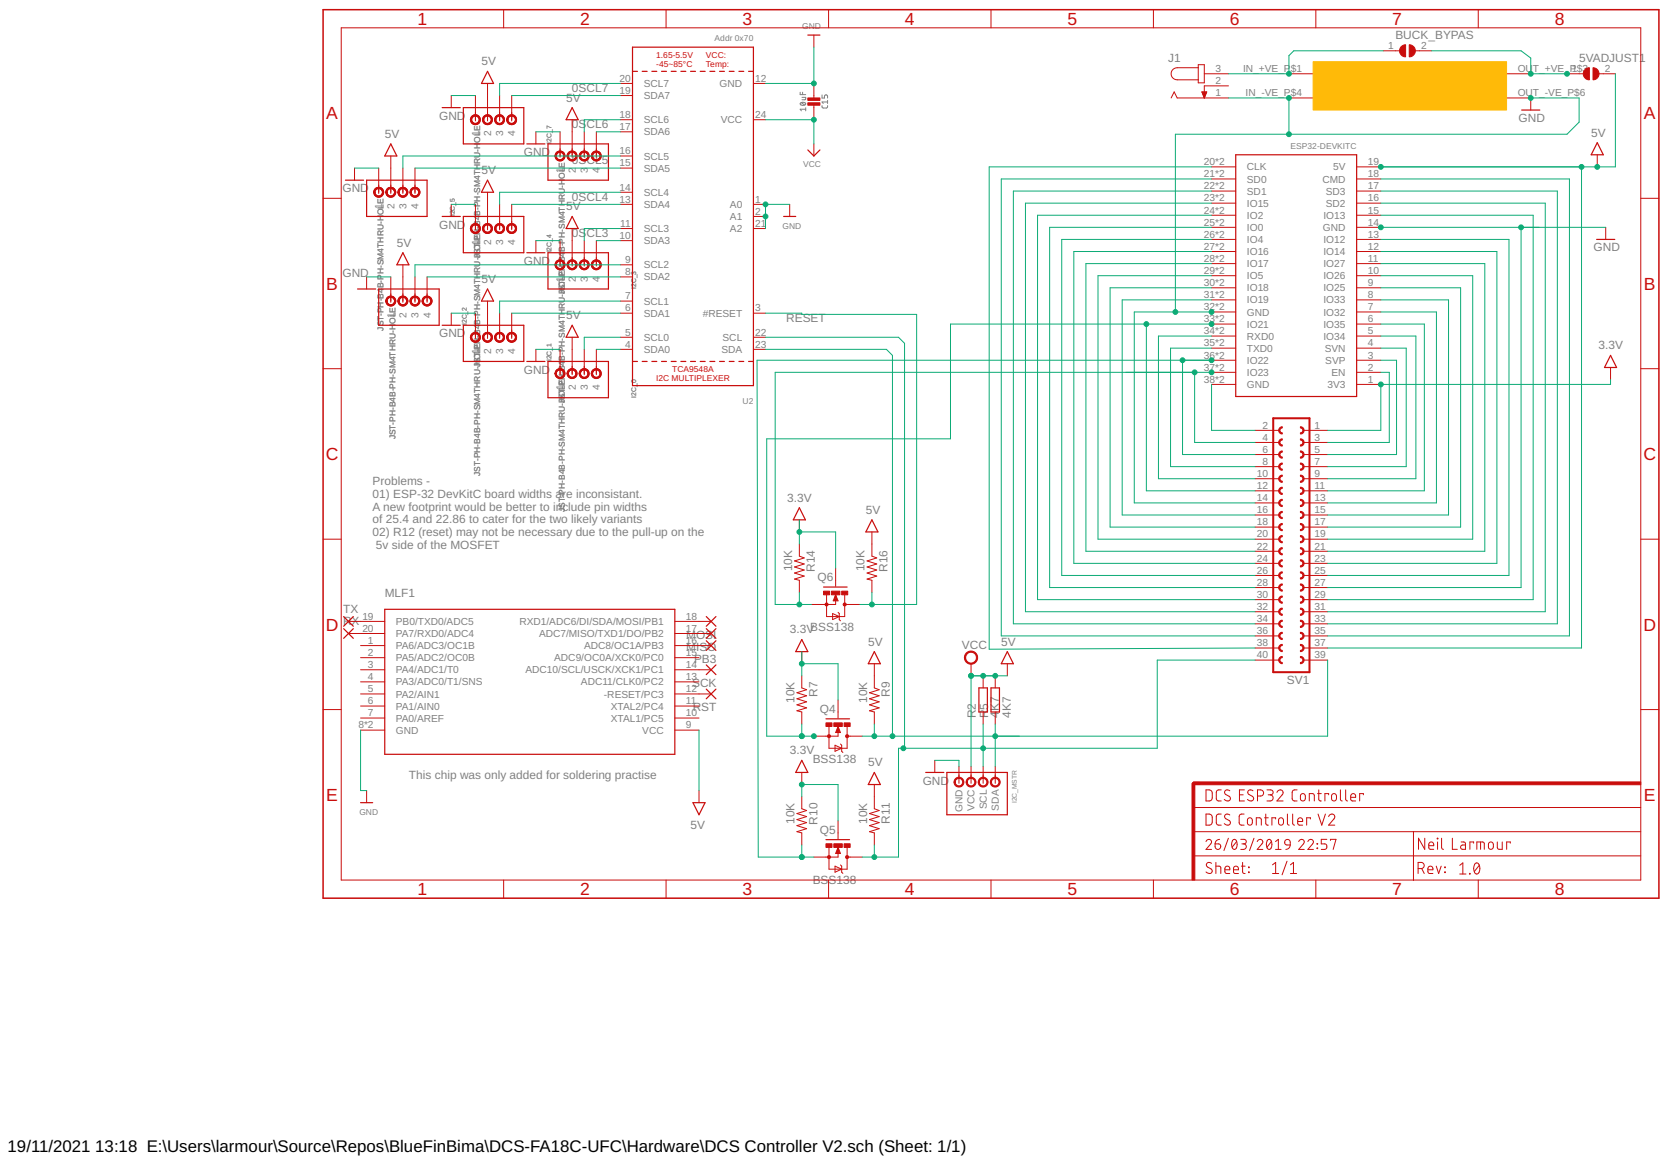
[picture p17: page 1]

JST-PH-B4B-PH-SM4THRU-HOLE JST-PH-B4B-PH-SM4THRU-HOLE GND

JST-PH-B4B-PH-SM4THRU-HOLE

JST-PH-B4B-PH-SM4THRU-HOLE JST-PH-B4B-PH-SM4THRU-HOL

Problems - 01) ESP-32 DevKitC board widths are inconsistant. A new footprint would be better to include pin widths of 25.4 and 22.86 to cater for the two likely variants 02) R12 (reset) may not be necessary due to the pull-up on the

5v side of the MOSFET

This chip was only added for soldering practise

19/11/2021 13:18 E:\Users\larmour\Source\Repos\BlueFinBima\DCS-FA18C-UFC\Hardware\DCS Controller V2.sch (Sheet: 1/1)

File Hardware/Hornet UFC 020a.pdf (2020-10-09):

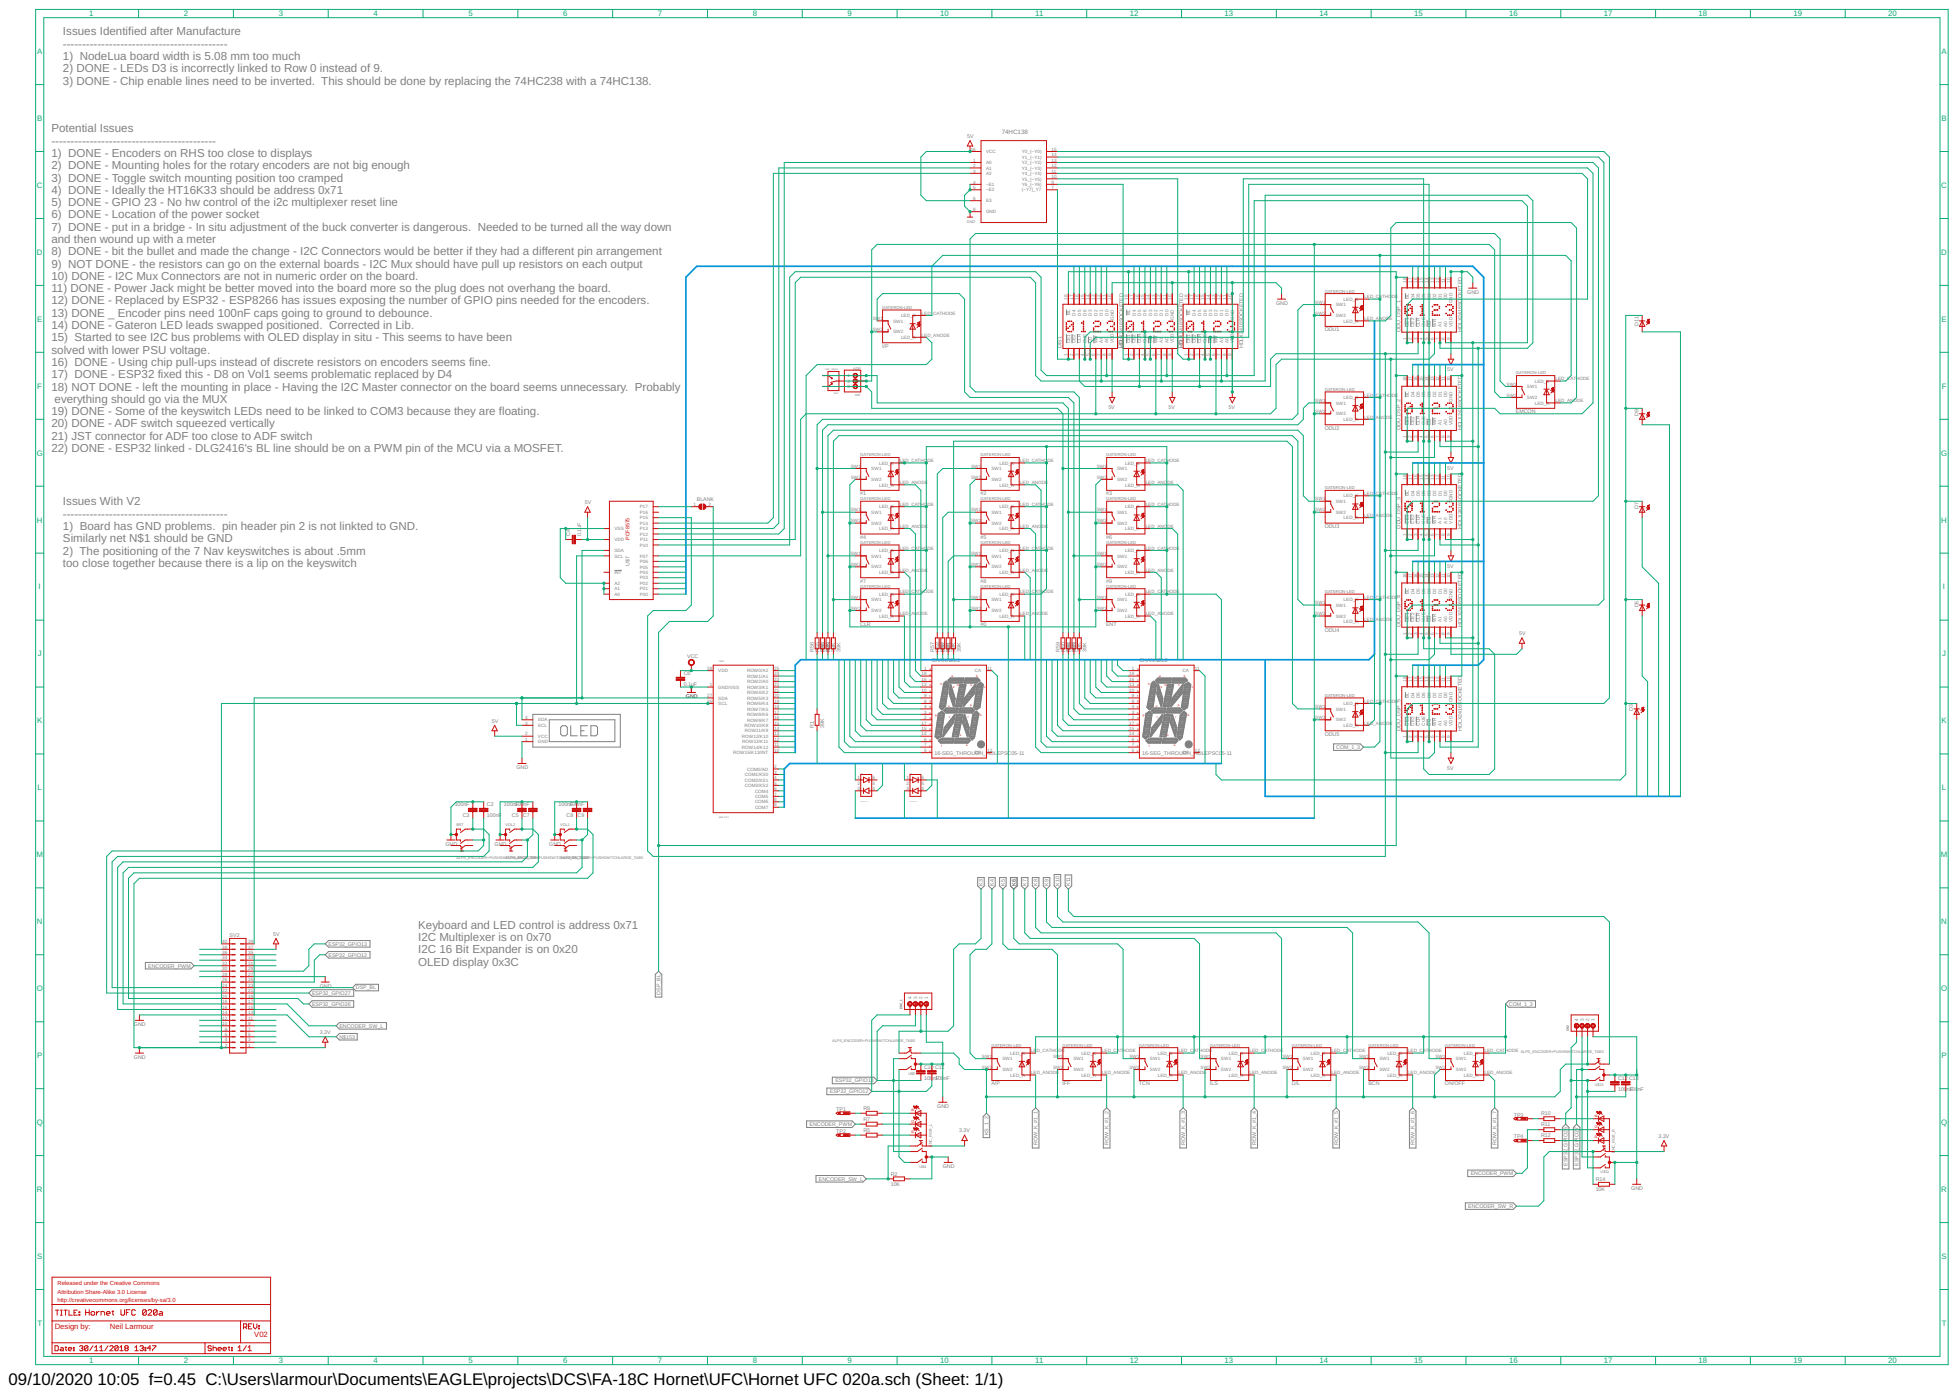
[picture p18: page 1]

Issues Identified after Manufacture
------------------------------------------- 1) NodeLua board width is 5.08 mm too much

2) DONE - LEDs D3 is incorrectly linked to Row 0 instead of 9. 3) DONE - Chip enable lines need to be inverted. This should be done by replacing the 74HC238 with a 74HC138. Potential Issues

------------------------------------------- 1) DONE - Encoders on RHS too close to displays 2) DONE - Mounting holes for the rotary encoders are not big enough

3) DONE - Toggle switch mounting position too cramped
4) DONE - Ideally the HT16K33 should be address 0x71
5) DONE - GPIO 23 - No hw control of the i2c multiplexer reset line
6) DONE - Location of the power socket
7) DONE - put in a bridge - In situ adjustment of the buck converter is dangerous. Needed to be turned all the way down
and then wound up with a meter 8) DONE - bit the bullet and made the change - I2C Connectors would be better if they had a different pin arrangement

9) NOT DONE - the resistors can go on the external boards - I2C Mux should have pull up resistors on each output
10) DONE - I2C Mux Connectors are not in numeric order on the board. 11) DONE - Power Jack might be better moved into the board more so the plug does not overhang the board. 12) DONE - Replaced by ESP32 - ESP8266 has issues exposing the number of GPIO pins needed for the encoders. 13) DONE _ Encoder pins need 100nF caps going to ground to debounce. 14) DONE - Gateron LED leads swapped positioned. Corrected in Lib. 15) Started to see I2C bus problems with OLED display in situ - This seems to have been

solved with lower PSU voltage. 16) DONE - Using chip pull-ups instead of discrete resistors on encoders seems fine. 17) DONE - ESP32 fixed this - D8 on Vol1 seems problematic replaced by D4

18) NOT DONE - left the mounting in place - Having the I2C Master connector on the board seems unnecessary. Probably everything should go via the MUX

19) DONE - Some of the keyswitch LEDs need to be linked to COM3 because they are floating. 20) DONE - ADF switch squeezed vertically

21) JST connector for ADF too close to ADF switch
22) DONE - ESP32 linked - DLG2416's BL line should be on a PWM pin of the MCU via a MOSFET.

Issues With V2
------------------------------------------- 1) Board has GND problems. pin header pin 2 is not linkted to GND. Similarly net N$1 should be GND

2) The positioning of the 7 Nav keyswitches is about .5mm
too close together because there is a lip on the keyswitch

Keyboard and LED control is address 0x71
I2C Multiplexer is on 0x70
I2C 16 Bit Expander is on 0x20
OLED display 0x3C

Released under the Creative Commons Attribution Share-Alike 3.0 License

http://creativecommons.org/licenses/by-sa/3.0 Design by:

09/10/2020 10:05 f=0.45 C:\Users\larmour\Documents\EAGLE\projects\DCS\FA-18C Hornet\UFC\Hornet UFC 020a.sch (Sheet: 1/1)

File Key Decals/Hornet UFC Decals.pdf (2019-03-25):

# CONN2

# CONN2

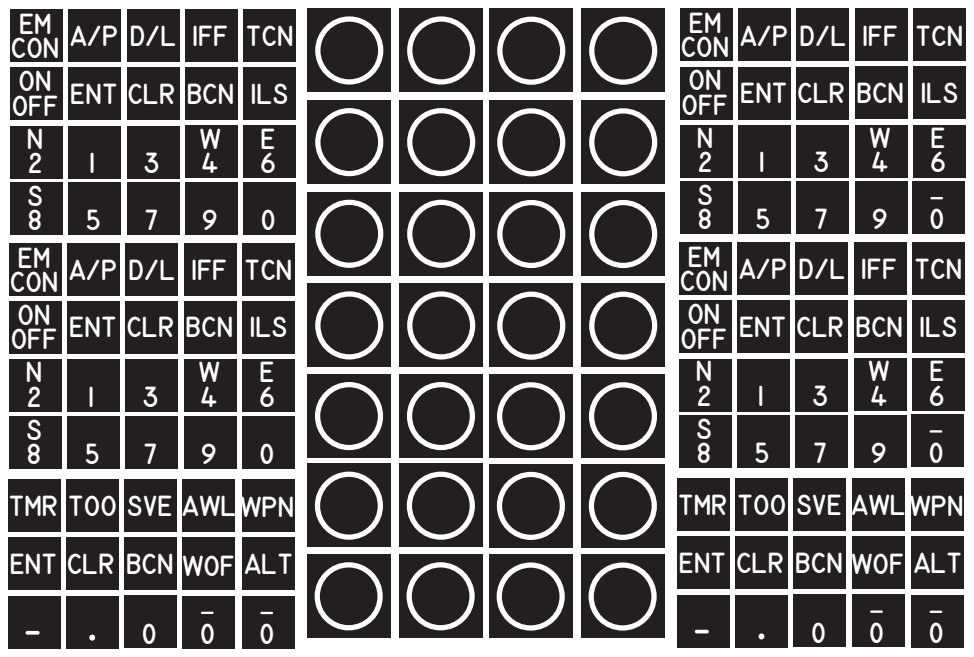
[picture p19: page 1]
ENT; CLR; BCN; ILS; IFF; TCN EM; ON OFF; CONN2; WOF; TMR; TOO; SVE; AWL; ALT; WPN

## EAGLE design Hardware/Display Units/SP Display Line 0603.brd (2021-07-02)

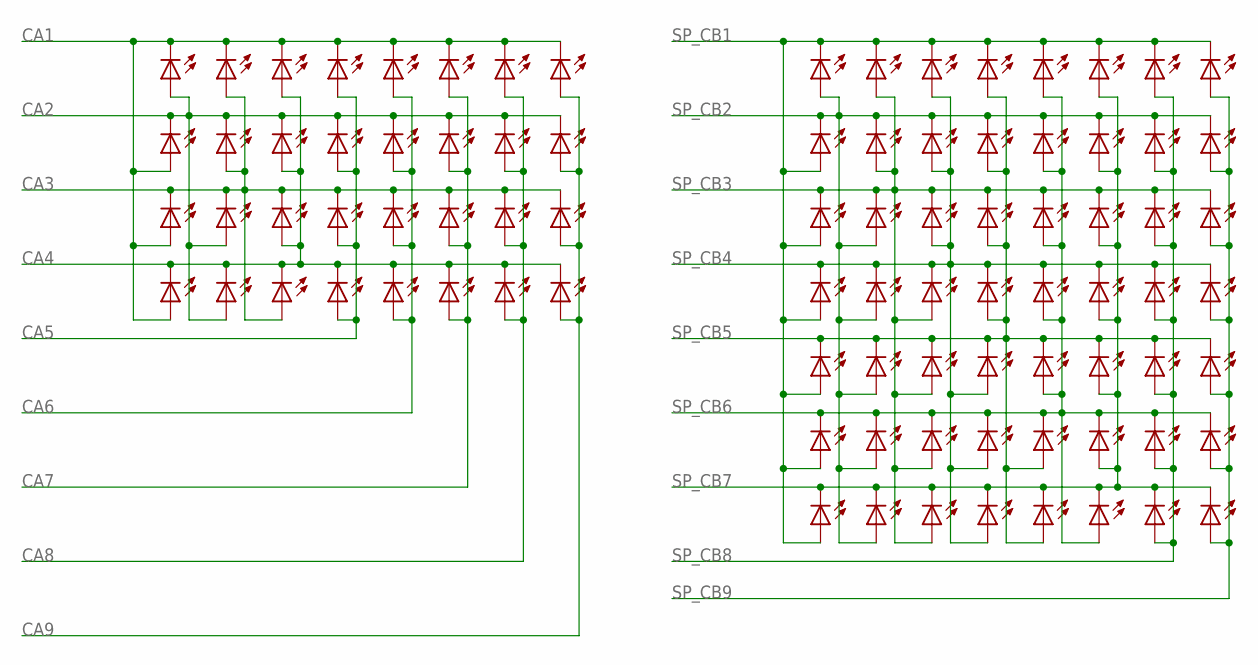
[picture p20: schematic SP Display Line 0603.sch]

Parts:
LED_A1, LED_A2: LEDSMT0603_1; CHIPLED_0603
LED_B1, LED_B2: LEDSMT0603_1; CHIPLED_0603
LED_C1, LED_C2: LEDSMT0603_1; CHIPLED_0603
LED_D1, LED_D2: LEDSMT0603_1; CHIPLED_0603
LED_DA1, LED_DA2, LED_DA3, LED_DA4, LED_DA5, LED_DA6, LED_DA7: LEDSMT0603_1; CHIPLED_0603
LED_DB1, LED_DB2, LED_DB3, LED_DB4, LED_DB5, LED_DB6, LED_DB7: LEDSMT0603_1; CHIPLED_0603
LED_DC1, LED_DC2, LED_DC3, LED_DC4, LED_DC5, LED_DC6, LED_DC7: LEDSMT0603_1; CHIPLED_0603
LED_DD1, LED_DD2, LED_DD3, LED_DD4, LED_DD5, LED_DD6, LED_DD7: LEDSMT0603_1; CHIPLED_0603
LED_DE1, LED_DE2, LED_DE3, LED_DE4, LED_DE5, LED_DE6, LED_DE7: LEDSMT0603_1; CHIPLED_0603
LED_DF1, LED_DF2, LED_DF3, LED_DF4, LED_DF5, LED_DF6, LED_DF7: LEDSMT0603_1; CHIPLED_0603
LED_DG1, LED_DG2, LED_DG3, LED_DG4, LED_DG5, LED_DG6, LED_DG7: LEDSMT0603_1; CHIPLED_0603
LED_DP1, LED_DP2, LED_DP3, LED_DP4, LED_DP5, LED_DP6, LED_DP7: LEDSMT0603_1; CHIPLED_0603
LED_E1, LED_E2: LEDSMT0603_1; CHIPLED_0603
LED_F1, LED_F2: LEDSMT0603_1; CHIPLED_0603
LED_G1, LED_G2: LEDSMT0603_1; CHIPLED_0603
LED_H1, LED_H2: LEDSMT0603_1; CHIPLED_0603
LED_K1, LED_K2: LEDSMT0603_1; CHIPLED_0603
LED_M1, LED_M2: LEDSMT0603_1; CHIPLED_0603
LED_N1, LED_N2: LEDSMT0603_1; CHIPLED_0603
LED_P1, LED_P2: LEDSMT0603_1; CHIPLED_0603
LED_R1, LED_R2: LEDSMT0603_1; CHIPLED_0603
LED_S1, LED_S2: LEDSMT0603_1; CHIPLED_0603
LED_T1, LED_T2: LEDSMT0603_1; CHIPLED_0603
LED_U1, LED_U2: LEDSMT0603_1; CHIPLED_0603

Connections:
CA1: LED_A1.C, LED_A2.A, LED_B1.C, LED_C1.C, LED_D1.C, LED_E1.C, LED_F1.C, LED_G1.C, LED_H1.C, LED_K1.A, LED_K2.A
CA2: LED_A1.A, LED_B2.A, LED_K1.C, LED_M1.C, LED_M2.A, LED_N1.C, LED_P1.C, LED_R1.C, LED_S1.C, LED_T1.C, LED_U1.C
CA3: LED_A2.C, LED_B1.A, LED_B2.C, LED_C2.C, LED_D2.C, LED_E2.C, LED_F2.C, LED_G2.C, LED_H2.C, LED_M1.A, LED_N2.A
CA4: LED_C1.A, LED_C2.A, LED_K2.C, LED_M2.C, LED_N1.A, LED_N2.C, LED_P2.C, LED_R2.C, LED_S2.C, LED_T2.C, LED_U2.C
CA5: LED_D1.A, LED_D2.A, LED_P1.A, LED_P2.A
CA6: LED_E1.A, LED_E2.A, LED_R1.A, LED_R2.A
CA7: LED_F1.A, LED_F2.A, LED_S1.A, LED_S2.A
CA8: LED_G1.A, LED_G2.A, LED_T1.A, LED_T2.A
CA9: LED_H1.A, LED_H2.A, LED_U1.A, LED_U2.A
SP_CB1: LED_DA1.C, LED_DA2.A, LED_DA3.A, LED_DA4.A, LED_DA5.A, LED_DA6.A, LED_DA7.A, LED_DB1.C, LED_DC1.C, LED_DD1.C, LED_DE1.C, LED_DF1.C, LED_DG1.C, LED_DP1.C
SP_CB2: LED_DA1.A, LED_DA2.C, LED_DB2.C, LED_DB3.A, LED_DB4.A, LED_DB5.A, LED_DB6.A, LED_DB7.A, LED_DC2.C, LED_DD2.C, LED_DE2.C, LED_DF2.C, LED_DG2.C, LED_DP2.C
SP_CB3: LED_DA3.C, LED_DB1.A, LED_DB2.A, LED_DB3.C, LED_DC3.C, LED_DC4.A, LED_DC5.A, LED_DC6.A, LED_DC7.A, LED_DD3.C, LED_DE3.C, LED_DF3.C, LED_DG3.C, LED_DP3.C
SP_CB4: LED_DA4.C, LED_DB4.C, LED_DC1.A, LED_DC2.A, LED_DC3.A, LED_DC4.C, LED_DD4.C, LED_DD5.A, LED_DD6.A, LED_DD7.A, LED_DE4.C, LED_DF4.C, LED_DG4.C, LED_DP4.C
SP_CB5: LED_DA5.C, LED_DB5.C, LED_DC5.C, LED_DD1.A, LED_DD2.A, LED_DD3.A, LED_DD4.A, LED_DD5.C, LED_DE5.C, LED_DE6.A, LED_DE7.A, LED_DF5.C, LED_DG5.C, LED_DP5.C
SP_CB6: LED_DA6.C, LED_DB6.C, LED_DC6.C, LED_DD6.C, LED_DE1.A, LED_DE2.A, LED_DE3.A, LED_DE4.A, LED_DE5.A, LED_DE6.C, LED_DF6.C, LED_DF7.A, LED_DG6.C, LED_DP6.C
SP_CB7: LED_DA7.C, LED_DB7.C, LED_DC7.C, LED_DD7.C, LED_DE7.C, LED_DF1.A, LED_DF2.A, LED_DF3.A, LED_DF4.A, LED_DF5.A, LED_DF6.A, LED_DF7.C, LED_DG7.C, LED_DP7.C
SP_CB8: LED_DG1.A, LED_DG2.A, LED_DG3.A, LED_DG4.A, LED_DG5.A, LED_DG6.A, LED_DG7.A
SP_CB9: LED_DP1.A, LED_DP2.A, LED_DP3.A, LED_DP4.A, LED_DP5.A, LED_DP6.A, LED_DP7.A

Board: 4 copper layers, 88 parts (0 on the bottom side), 18 nets, no tracks yet.

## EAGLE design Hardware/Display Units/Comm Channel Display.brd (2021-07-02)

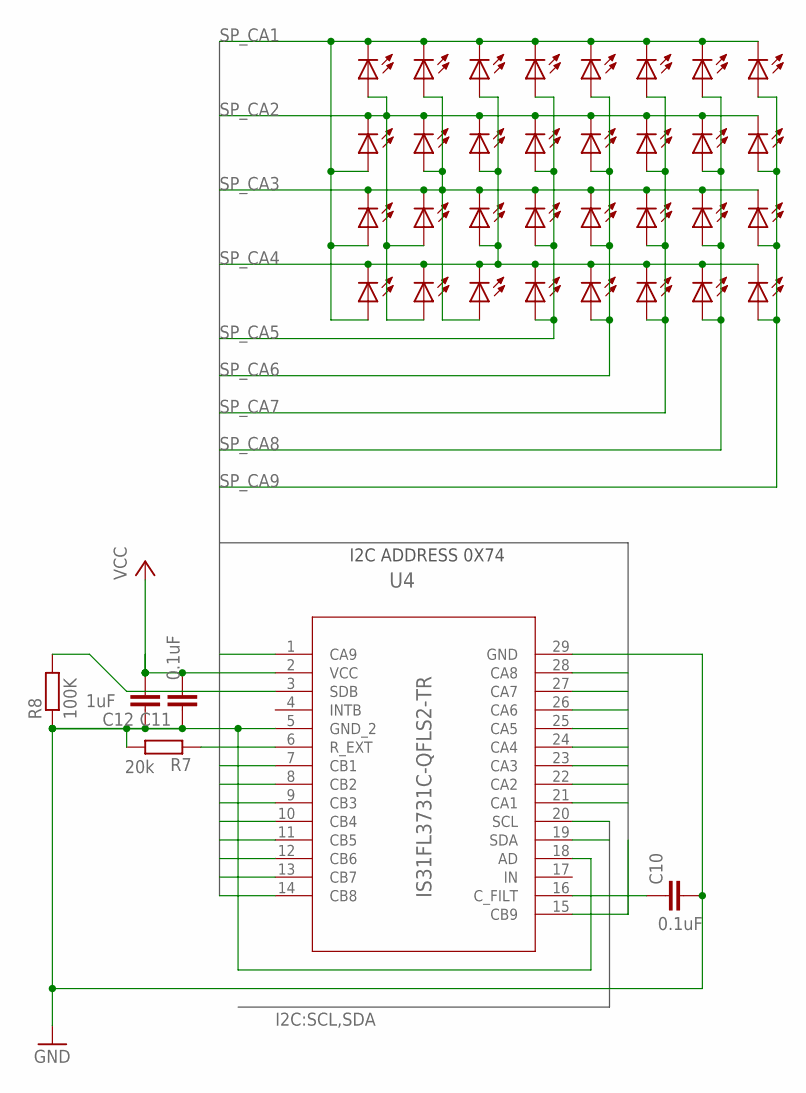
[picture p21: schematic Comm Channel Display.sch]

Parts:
C10: 0.1uF; C0201
C11: 0.1uF; C0402
C12: 1uF; C0402
LED_A3, LED_A4: LEDSMT0603_1; CHIPLED_0603
LED_B3, LED_B4: LEDSMT0603_1; CHIPLED_0603
LED_C3, LED_C4: LEDSMT0603_1; CHIPLED_0603
LED_D3, LED_D4: LEDSMT0603_1; CHIPLED_0603
LED_E3, LED_E4: LEDSMT0603_1; CHIPLED_0603
LED_F3, LED_F4: LEDSMT0603_1; CHIPLED_0603
LED_G3, LED_G4: LEDSMT0603_1; CHIPLED_0603
LED_H3, LED_H4: LEDSMT0603_1; CHIPLED_0603
LED_K3, LED_K4: LEDSMT0603_1; CHIPLED_0603
LED_M3, LED_M4: LEDSMT0603_1; CHIPLED_0603
LED_N3, LED_N4: LEDSMT0603_1; CHIPLED_0603
LED_P3, LED_P4: LEDSMT0603_1; CHIPLED_0603
LED_R3, LED_R4: LEDSMT0603_1; CHIPLED_0603
LED_S3, LED_S4: LEDSMT0603_1; CHIPLED_0603
LED_T3, LED_T4: LEDSMT0603_1; CHIPLED_0603
LED_U3, LED_U4: LEDSMT0603_1; CHIPLED_0603
R7: 20k; R0805
R8: 100K; R0201
U4: IS31FL3731C-QFLS2-TR; QFN-28_ISI

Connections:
GND: C10.2, C11.1, C12.1, R7.2, R8.1, U4.5 (GND_2), U4.18 (AD), U4.29 (GND)
unnamed: C10.1, U4.16 (C_FILT)
unnamed: R8.2, U4.3 (SDB)
unnamed: R7.1, U4.6 (R_EXT)
SCL: U4.20 (SCL)
SDA: U4.19 (SDA)
SP_CA1: LED_A3.C, LED_A4.A, LED_B3.C, LED_C3.C, LED_D3.C, LED_E3.C, LED_F3.C, LED_G3.C, LED_H3.C, LED_K3.A, LED_K4.A, U4.21 (CA1)
SP_CA2: LED_A3.A, LED_B4.A, LED_K3.C, LED_M3.C, LED_M4.A, LED_N3.C, LED_P3.C, LED_R3.C, LED_S3.C, LED_T3.C, LED_U3.C, U4.22 (CA2)
SP_CA3: LED_A4.C, LED_B3.A, LED_B4.C, LED_C4.C, LED_D4.C, LED_E4.C, LED_F4.C, LED_G4.C, LED_H4.C, LED_M3.A, LED_N4.A, U4.23 (CA3)
SP_CA4: LED_C3.A, LED_C4.A, LED_K4.C, LED_M4.C, LED_N3.A, LED_N4.C, LED_P4.C, LED_R4.C, LED_S4.C, LED_T4.C, LED_U4.C, U4.24 (CA4)
SP_CA5: LED_D3.A, LED_D4.A, LED_P3.A, LED_P4.A, U4.25 (CA5)
SP_CA6: LED_E3.A, LED_E4.A, LED_R3.A, LED_R4.A, U4.26 (CA6)
SP_CA7: LED_F3.A, LED_F4.A, LED_S3.A, LED_S4.A
SP_CA8: LED_G3.A, LED_G4.A, LED_T3.A, LED_T4.A, U4.28 (CA8)
SP_CA9: LED_H3.A, LED_H4.A, LED_U3.A, LED_U4.A, U4.1 (CA9)
SP_CB1: U4.7 (CB1)
SP_CB2: U4.8 (CB2)
SP_CB3: U4.9 (CB3)
SP_CB4: U4.10 (CB4)
SP_CB5: U4.11 (CB5)
SP_CB6: U4.12 (CB6)
SP_CB7: U4.13 (CB7), U4.27 (CA7)
SP_CB8: U4.14 (CB8)
SP_CB9: U4.15 (CB9)
VCC: C11.2, C12.2, U4.2 (VCC)

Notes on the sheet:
I2C ADDRESS 0X74

Board: 4 copper layers, 38 parts (0 on the bottom side), 15 nets, no tracks yet.

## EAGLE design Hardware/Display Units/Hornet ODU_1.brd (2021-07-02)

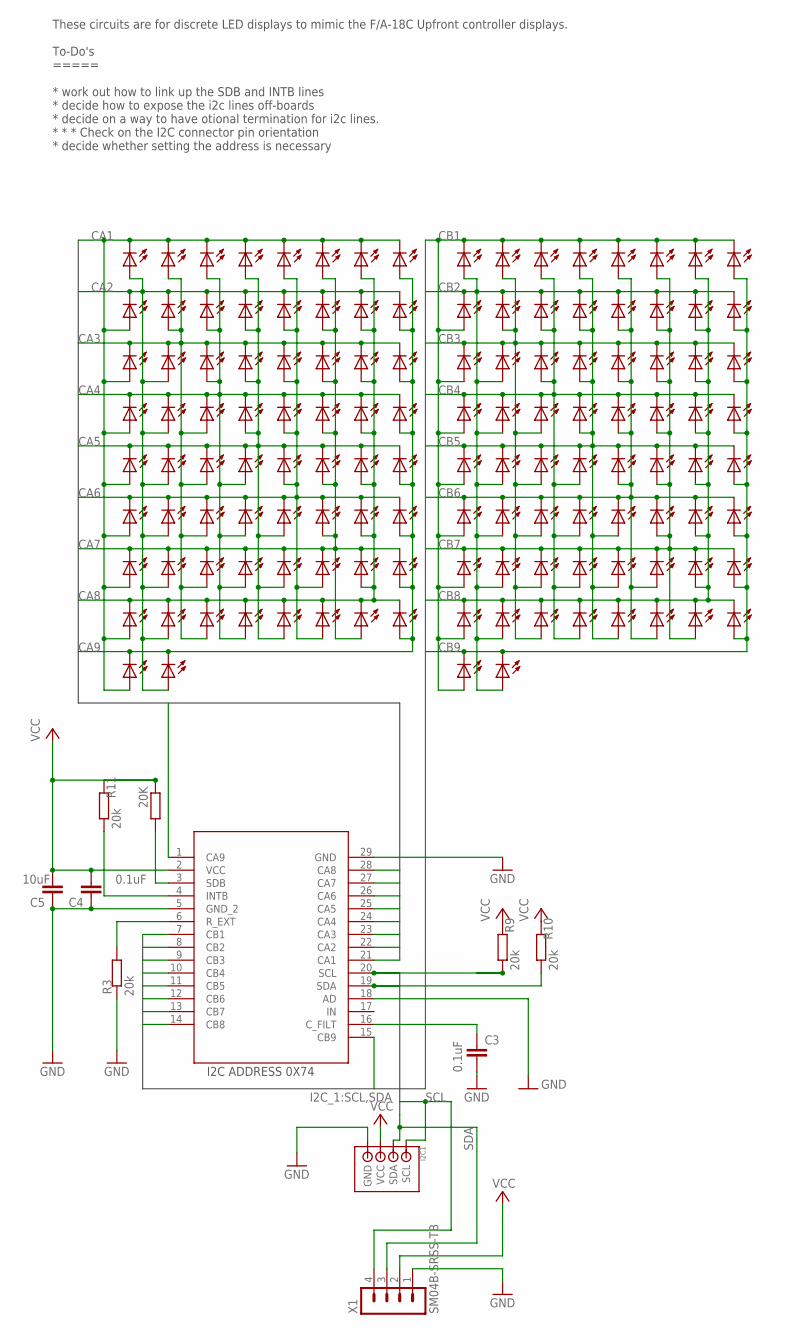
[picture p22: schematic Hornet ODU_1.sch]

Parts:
C3, C4: 0.1uF; C0805
C5: 10uF; C0805
I2C1: I2C_STEMMA_JST_PH_CONNECTORB4B-PH_STEMMA_I2C; B4B-PH-SOLDER
LED_A5, LED_A6, LED_A7, LED_A8, LED_A9, LED_A10, LED_A11, LED_A12: LEDSMT0603_1; CHIPLED_0603
LED_B5, LED_B6, LED_B7, LED_B8, LED_B9, LED_B10, LED_B11, LED_B12: LEDSMT0603_1; CHIPLED_0603
LED_C5, LED_C6, LED_C7, LED_C8, LED_C9, LED_C10, LED_C11, LED_C12: LEDSMT0603_1; CHIPLED_0603
LED_D5, LED_D6, LED_D7, LED_D8, LED_D9, LED_D10, LED_D11, LED_D12: LEDSMT0603_1; CHIPLED_0603
LED_E5, LED_E6, LED_E7, LED_E8, LED_E9, LED_E10, LED_E11, LED_E12: LEDSMT0603_1; CHIPLED_0603
LED_F5, LED_F6, LED_F7, LED_F8, LED_F9, LED_F10, LED_F11, LED_F12: LEDSMT0603_1; CHIPLED_0603
LED_G5, LED_G6, LED_G7, LED_G8, LED_G9, LED_G10, LED_G11, LED_G12: LEDSMT0603_1; CHIPLED_0603
LED_H5, LED_H6, LED_H7, LED_H8, LED_H9, LED_H10, LED_H11, LED_H12: LEDSMT0603_1; CHIPLED_0603
LED_K5, LED_K6, LED_K7, LED_K8, LED_K9, LED_K10, LED_K11, LED_K12: LEDSMT0603_1; CHIPLED_0603
LED_M5, LED_M6, LED_M7, LED_M8, LED_M9, LED_M10, LED_M11, LED_M12: LEDSMT0603_1; CHIPLED_0603
LED_N5, LED_N6, LED_N7, LED_N8, LED_N9, LED_N10, LED_N11, LED_N12: LEDSMT0603_1; CHIPLED_0603
LED_P5, LED_P6, LED_P7, LED_P8, LED_P9, LED_P10, LED_P11, LED_P12: LEDSMT0603_1; CHIPLED_0603
LED_R5, LED_R6, LED_R7, LED_R8, LED_R9, LED_R10, LED_R11, LED_R12: LEDSMT0603_1; CHIPLED_0603
LED_S5, LED_S6, LED_S7, LED_S8, LED_S9, LED_S10, LED_S11, LED_S12: LEDSMT0603_1; CHIPLED_0603
LED_SEL3, LED_SEL4, LED_SEL5, LED_SEL6: LEDSMT0603_1; CHIPLED_0603
LED_T5, LED_T6, LED_T7, LED_T8, LED_T9, LED_T10, LED_T11, LED_T12: LEDSMT0603_1; CHIPLED_0603
LED_U5, LED_U6, LED_U7, LED_U8, LED_U9, LED_U10, LED_U11, LED_U12: LEDSMT0603_1; CHIPLED_0603
R3, R9, R10, R11: 20k; R0805
R6: 20K; R0805
U1: IS31FL3731C-QFLS2-TR; QFN-28_ISI
X1: SM04B-SRSS-TB

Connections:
CA1: LED_A5.C, LED_A6.A, LED_A7.A, LED_A8.A, LED_B5.C, LED_C5.C, LED_D5.C, LED_E5.C, LED_F5.C, LED_G5.C, LED_H5.C, LED_K5.A, LED_K6.A, LED_K7.A, LED_K8.A, LED_SEL3.A, U1.21 (CA1)
CA2: LED_A5.A, LED_B6.A, LED_B7.A, LED_B8.A, LED_K5.C, LED_M5.C, LED_M6.A, LED_M7.A, LED_M8.A, LED_N5.C, LED_P5.C, LED_R5.C, LED_S5.C, LED_SEL4.A, LED_T5.C, LED_U5.C, U1.22 (CA2)
CA3: LED_A6.C, LED_B5.A, LED_B6.C, LED_C6.C, LED_C7.A, LED_C8.A, LED_D6.C, LED_E6.C, LED_F6.C, LED_G6.C, LED_H6.C, LED_M5.A, LED_N6.A, LED_N7.A, LED_N8.A, U1.23 (CA3)
CA4: LED_C5.A, LED_C6.A, LED_D7.A, LED_D8.A, LED_K6.C, LED_M6.C, LED_N5.A, LED_N6.C, LED_P6.C, LED_P7.A, LED_P8.A, LED_R6.C, LED_S6.C, LED_T6.C, LED_U6.C, U1.24 (CA4)
CA5: LED_A7.C, LED_B7.C, LED_C7.C, LED_D5.A, LED_D6.A, LED_D7.C, LED_E7.C, LED_E8.A, LED_F7.C, LED_G7.C, LED_H7.C, LED_P5.A, LED_P6.A, LED_R7.A, LED_R8.A, U1.25 (CA5)
CA6: LED_E5.A, LED_E6.A, LED_E7.A, LED_F8.A, LED_K7.C, LED_M7.C, LED_N7.C, LED_P7.C, LED_R5.A, LED_R6.A, LED_R7.C, LED_S7.C, LED_S8.A, LED_T7.C, LED_U7.C, U1.26 (CA6)
CA7: LED_A8.C, LED_B8.C, LED_C8.C, LED_D8.C, LED_E8.C, LED_F5.A, LED_F6.A, LED_F7.A, LED_F8.C, LED_G8.C, LED_H8.C, LED_S5.A, LED_S6.A, LED_S7.A, LED_T8.A, U1.27 (CA7)
CA8: LED_G5.A, LED_G6.A, LED_G7.A, LED_G8.A, LED_K8.C, LED_M8.C, LED_N8.C, LED_P8.C, LED_R8.C, LED_S8.C, LED_T5.A, LED_T6.A, LED_T7.A, LED_T8.C, LED_U8.C, U1.28 (CA8)
CA9: LED_H5.A, LED_H6.A, LED_H7.A, LED_H8.A, LED_SEL3.C, LED_SEL4.C, LED_U5.A, LED_U6.A, LED_U7.A, LED_U8.A, U1.1 (CA9)
CB1: LED_A9.C, LED_A10.A, LED_A11.A, LED_A12.A, LED_B9.C, LED_C9.C, LED_D9.C, LED_E9.C, LED_F9.C, LED_G9.C, LED_H9.C, LED_K9.A, LED_K10.A, LED_K11.A, LED_K12.A, LED_SEL5.A, U1.7 (CB1)
CB2: LED_A9.A, LED_B10.A, LED_B11.A, LED_B12.A, LED_K9.C, LED_M9.C, LED_M10.A, LED_M11.A, LED_M12.A, LED_N9.C, LED_P9.C, LED_R9.C, LED_S9.C, LED_SEL6.A, LED_T9.C, LED_U9.C, U1.8 (CB2)
CB3: LED_A10.C, LED_B9.A, LED_B10.C, LED_C10.C, LED_C11.A, LED_C12.A, LED_D10.C, LED_E10.C, LED_F10.C, LED_G10.C, LED_H10.C, LED_M9.A, LED_N10.A, LED_N11.A, LED_N12.A, U1.9 (CB3)
CB4: LED_C9.A, LED_C10.A, LED_D11.A, LED_D12.A, LED_K10.C, LED_M10.C, LED_N9.A, LED_N10.C, LED_P10.C, LED_P11.A, LED_P12.A, LED_R10.C, LED_S10.C, LED_T10.C, LED_U10.C, U1.10 (CB4)
CB5: LED_A11.C, LED_B11.C, LED_C11.C, LED_D9.A, LED_D10.A, LED_D11.C, LED_E11.C, LED_E12.A, LED_F11.C, LED_G11.C, LED_H11.C, LED_P9.A, LED_P10.A, LED_R11.A, LED_R12.A, U1.11 (CB5)
CB6: LED_E9.A, LED_E10.A, LED_E11.A, LED_F12.A, LED_K11.C, LED_M11.C, LED_N11.C, LED_P11.C, LED_R9.A, LED_R10.A, LED_R11.C, LED_S11.C, LED_S12.A, LED_T11.C, LED_U11.C, U1.12 (CB6)
CB7: LED_A12.C, LED_B12.C, LED_C12.C, LED_D12.C, LED_E12.C, LED_F9.A, LED_F10.A, LED_F11.A, LED_F12.C, LED_G12.C, LED_H12.C, LED_S9.A, LED_S10.A, LED_S11.A, LED_T12.A, U1.13 (CB7)
CB8: LED_G9.A, LED_G10.A, LED_G11.A, LED_G12.A, LED_K12.C, LED_M12.C, LED_N12.C, LED_P12.C, LED_R12.C, LED_S12.C, LED_T9.A, LED_T10.A, LED_T11.A, LED_T12.C, LED_U12.C, U1.14 (CB8)
CB9: LED_H9.A, LED_H10.A, LED_H11.A, LED_H12.A, LED_SEL5.C, LED_SEL6.C, LED_U9.A, LED_U10.A, LED_U11.A, LED_U12.A, U1.15 (CB9)
GND: C3.2, C4.1, C5.1, I2C1.P1 (GND), R3.2, U1.5 (GND_2), U1.18 (AD), U1.29 (GND), X1.1
unnamed: R3.1, U1.6 (R_EXT)
unnamed: C3.1, U1.16 (C_FILT)
unnamed: R6.2, U1.3 (SDB)
unnamed: R11.2, U1.4 (INTB)
SCL: I2C1.P4 (SCL), R9.2, U1.20 (SCL), X1.4
SDA: I2C1.P3 (SDA), R10.2, U1.19 (SDA), X1.3
VCC: C4.2, C5.2, I2C1.P2 (VCC), R6.1, R9.1, R10.1, R11.1, U1.2 (VCC), X1.2

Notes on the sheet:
I2C ADDRESS 0X74
These circuits are for discrete LED displays to mimic the F/A-18C Upfront controller displays. To-Do's ===== * work out how to link up the SDB and INTB lines * decide how to expose the i2c lines off-boards * decide on a way to have otional termination for i2c lines. * * * Check on the I2C connector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

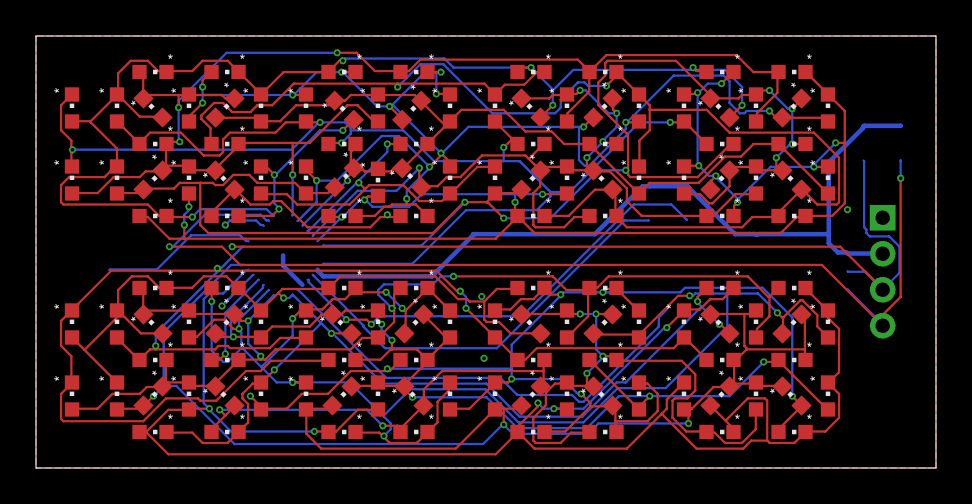
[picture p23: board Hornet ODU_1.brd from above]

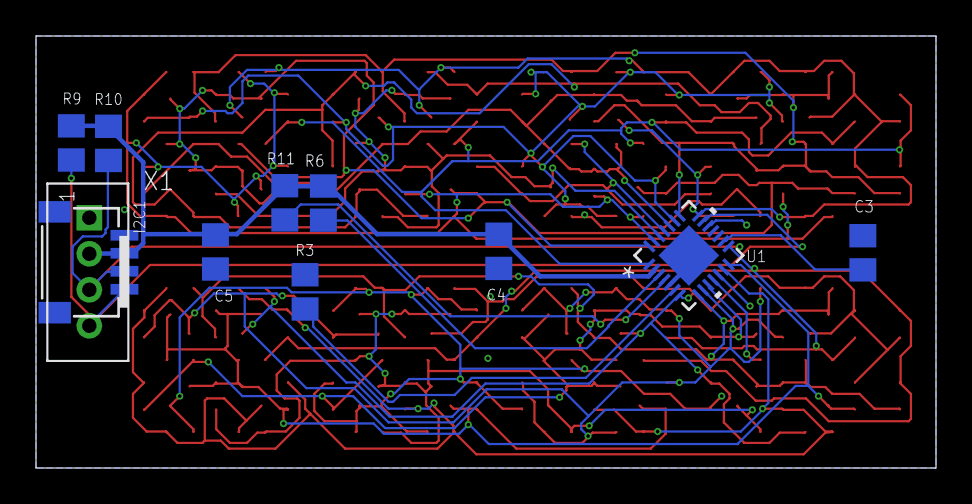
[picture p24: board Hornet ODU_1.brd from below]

Board: 4 copper layers, 50.0 x 24.0 mm, 143 parts (11 on the bottom side), 26 nets.

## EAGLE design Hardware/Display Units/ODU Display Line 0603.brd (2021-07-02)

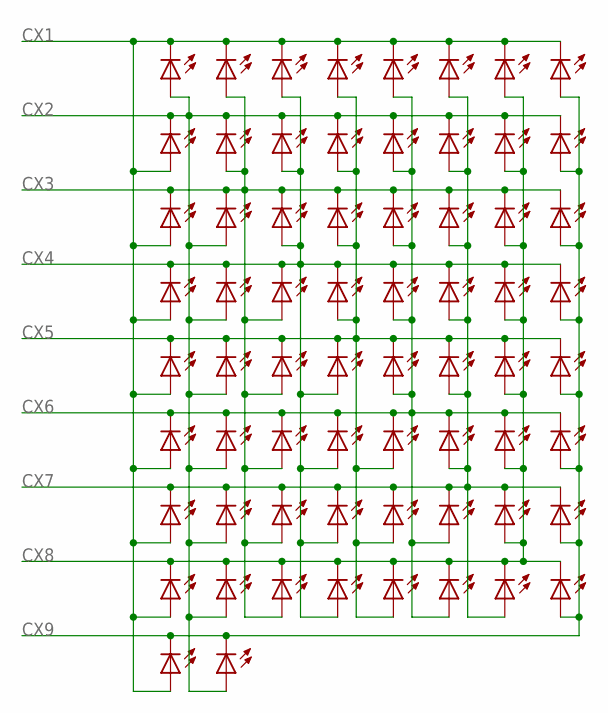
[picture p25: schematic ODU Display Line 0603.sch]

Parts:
LED_A1, LED_A2, LED_A3, LED_A4: LEDSMT0603_1; CHIPLED_0603
LED_B1, LED_B2, LED_B3, LED_B4: LEDSMT0603_1; CHIPLED_0603
LED_C1, LED_C2, LED_C3, LED_C4: LEDSMT0603_1; CHIPLED_0603
LED_D1, LED_D2, LED_D3, LED_D4: LEDSMT0603_1; CHIPLED_0603
LED_E1, LED_E2, LED_E3, LED_E4: LEDSMT0603_1; CHIPLED_0603
LED_F1, LED_F2, LED_F3, LED_F4: LEDSMT0603_1; CHIPLED_0603
LED_G1, LED_G2, LED_G3, LED_G4: LEDSMT0603_1; CHIPLED_0603
LED_H1, LED_H2, LED_H3, LED_H4: LEDSMT0603_1; CHIPLED_0603
LED_K1, LED_K2, LED_K3, LED_K4: LEDSMT0603_1; CHIPLED_0603
LED_M1, LED_M2, LED_M3, LED_M4: LEDSMT0603_1; CHIPLED_0603
LED_N1, LED_N2, LED_N3, LED_N4: LEDSMT0603_1; CHIPLED_0603
LED_P1, LED_P2, LED_P3, LED_P4: LEDSMT0603_1; CHIPLED_0603
LED_R1, LED_R2, LED_R3, LED_R4: LEDSMT0603_1; CHIPLED_0603
LED_S1, LED_S2, LED_S3, LED_S4: LEDSMT0603_1; CHIPLED_0603
LED_SEL1, LED_SEL2: LEDSMT0603_1; CHIPLED_0603
LED_T1, LED_T2, LED_T3, LED_T4: LEDSMT0603_1; CHIPLED_0603
LED_U1, LED_U2, LED_U3, LED_U4: LEDSMT0603_1; CHIPLED_0603

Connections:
CX1: LED_A1.C, LED_A2.A, LED_A3.A, LED_A4.A, LED_B1.C, LED_C1.C, LED_D1.C, LED_E1.C, LED_F1.C, LED_G1.C, LED_H1.C, LED_K1.A, LED_K2.A, LED_K3.A, LED_K4.A, LED_SEL1.A
CX2: LED_A1.A, LED_B2.A, LED_B3.A, LED_B4.A, LED_K1.C, LED_M1.C, LED_M2.A, LED_M3.A, LED_M4.A, LED_N1.C, LED_P1.C, LED_R1.C, LED_S1.C, LED_SEL2.A, LED_T1.C, LED_U1.C
CX3: LED_A2.C, LED_B1.A, LED_B2.C, LED_C2.C, LED_C3.A, LED_C4.A, LED_D2.C, LED_E2.C, LED_F2.C, LED_G2.C, LED_H2.C, LED_M1.A, LED_N2.A, LED_N3.A, LED_N4.A
CX4: LED_C1.A, LED_C2.A, LED_D3.A, LED_D4.A, LED_K2.C, LED_M2.C, LED_N1.A, LED_N2.C, LED_P2.C, LED_P3.A, LED_P4.A, LED_R2.C, LED_S2.C, LED_T2.C, LED_U2.C
CX5: LED_A3.C, LED_B3.C, LED_C3.C, LED_D1.A, LED_D2.A, LED_D3.C, LED_E3.C, LED_E4.A, LED_F3.C, LED_G3.C, LED_H3.C, LED_P1.A, LED_P2.A, LED_R3.A, LED_R4.A
CX6: LED_E1.A, LED_E2.A, LED_E3.A, LED_F4.A, LED_K3.C, LED_M3.C, LED_N3.C, LED_P3.C, LED_R1.A, LED_R2.A, LED_R3.C, LED_S3.C, LED_S4.A, LED_T3.C, LED_U3.C
CX7: LED_A4.C, LED_B4.C, LED_C4.C, LED_D4.C, LED_E4.C, LED_F1.A, LED_F2.A, LED_F3.A, LED_F4.C, LED_G4.C, LED_H4.C, LED_S1.A, LED_S2.A, LED_S3.A, LED_T4.A
CX8: LED_G1.A, LED_G2.A, LED_G3.A, LED_G4.A, LED_K4.C, LED_M4.C, LED_N4.C, LED_P4.C, LED_R4.C, LED_S4.C, LED_T1.A, LED_T2.A, LED_T3.A, LED_T4.C, LED_U4.C
CX9: LED_H1.A, LED_H2.A, LED_H3.A, LED_H4.A, LED_SEL1.C, LED_SEL2.C, LED_U1.A, LED_U2.A, LED_U3.A, LED_U4.A

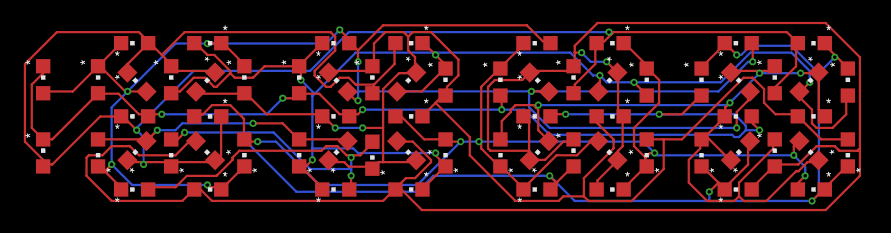
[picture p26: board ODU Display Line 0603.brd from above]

Board: 4 copper layers, 66 parts (0 on the bottom side), 9 nets.

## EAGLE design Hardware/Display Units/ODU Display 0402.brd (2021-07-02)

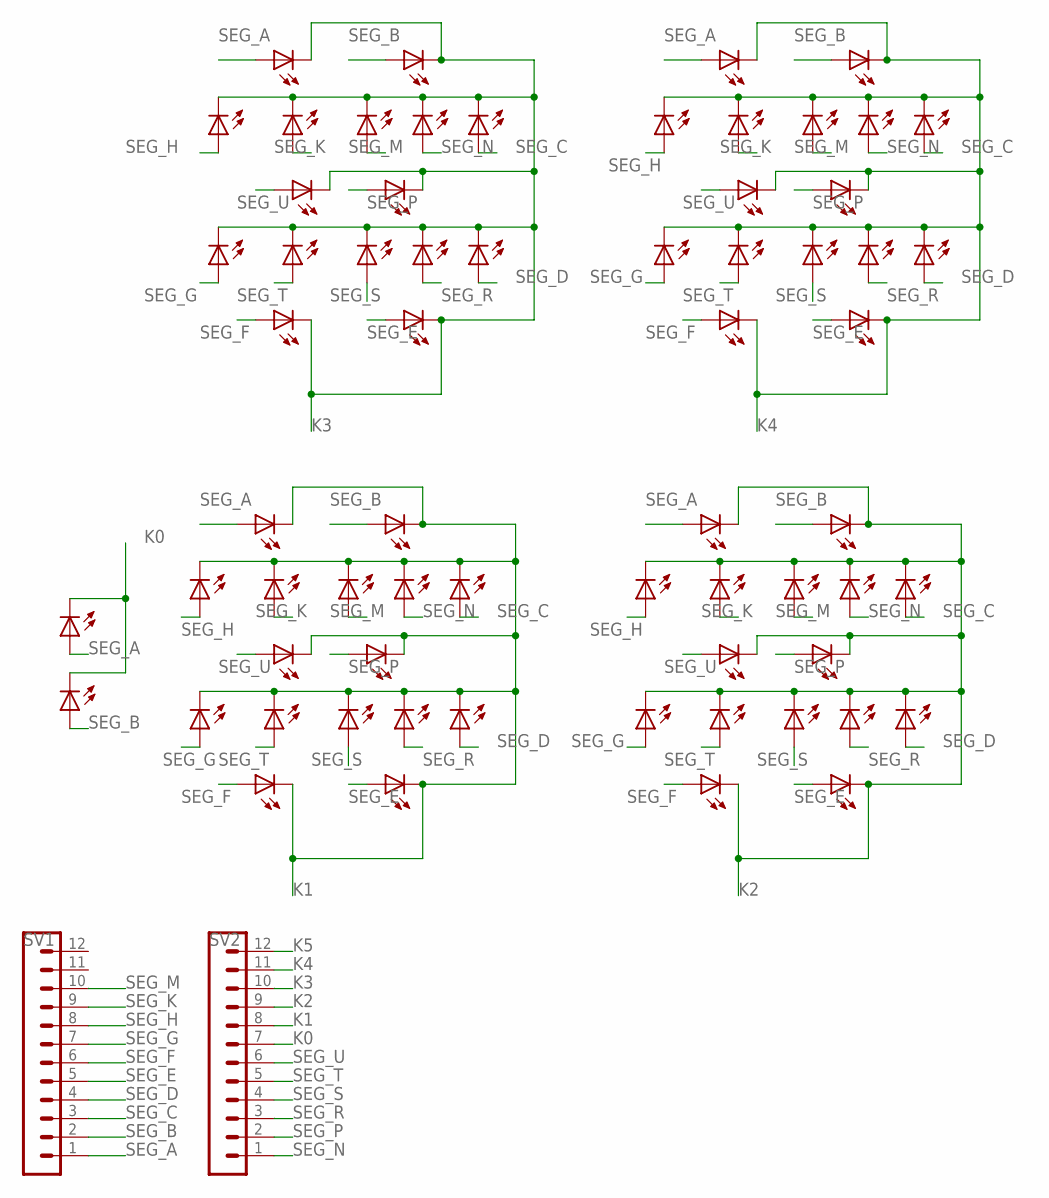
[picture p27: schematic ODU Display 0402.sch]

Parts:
LED_A1, LED_A2, LED_A3, LED_A4: LEDCHIPLED_0402; CHIPLED_0402
LED_B1, LED_B2, LED_B3, LED_B4: LEDCHIPLED_0402; CHIPLED_0402
LED_C1, LED_C2, LED_C3, LED_C4: LEDCHIPLED_0402; CHIPLED_0402
LED_D1, LED_D2, LED_D3, LED_D4: LEDCHIPLED_0402; CHIPLED_0402
LED_E1, LED_E2, LED_E3, LED_E4: LEDCHIPLED_0402; CHIPLED_0402
LED_F1, LED_F2, LED_F3, LED_F4: LEDCHIPLED_0402; CHIPLED_0402
LED_G1, LED_G2, LED_G3, LED_G4: LEDCHIPLED_0402; CHIPLED_0402
LED_H1, LED_H2, LED_H3, LED_H4: LEDCHIPLED_0402; CHIPLED_0402
LED_K1, LED_K2, LED_K3, LED_K4: LEDCHIPLED_0402; CHIPLED_0402
LED_M1, LED_M2, LED_M3, LED_M4: LEDCHIPLED_0402; CHIPLED_0402
LED_N1, LED_N2, LED_N3, LED_N4: LEDCHIPLED_0402; CHIPLED_0402
LED_P1, LED_P2, LED_P3, LED_P4: LEDCHIPLED_0402; CHIPLED_0402
LED_R1, LED_R2, LED_R3, LED_R4: LEDCHIPLED_0402; CHIPLED_0402
LED_S1, LED_S2, LED_S3, LED_S4: LEDCHIPLED_0402; CHIPLED_0402
LED_SEL1, LED_SEL2: LEDCHIPLED_0402; CHIPLED_0402
LED_T1, LED_T2, LED_T3, LED_T4: LEDCHIPLED_0402; CHIPLED_0402
LED_U1, LED_U2, LED_U3, LED_U4: LEDCHIPLED_0402; CHIPLED_0402
SV1, SV2: MA12-1

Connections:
K0: LED_SEL1.C, LED_SEL2.C, SV2.7
K1: LED_A1.C, LED_B1.C, LED_C1.C, LED_D1.C, LED_E1.C, LED_F1.C, LED_G1.C, LED_H1.C, LED_K1.C, LED_M1.C, LED_N1.C, LED_P1.C, LED_R1.C, LED_S1.C, LED_T1.C, LED_U1.C, SV2.8
K2: LED_A2.C, LED_B2.C, LED_C2.C, LED_D2.C, LED_E2.C, LED_F2.C, LED_G2.C, LED_H2.C, LED_K2.C, LED_M2.C, LED_N2.C, LED_P2.C, LED_R2.C, LED_S2.C, LED_T2.C, LED_U2.C, SV2.9
K3: LED_A3.C, LED_B3.C, LED_C3.C, LED_D3.C, LED_E3.C, LED_F3.C, LED_G3.C, LED_H3.C, LED_K3.C, LED_M3.C, LED_N3.C, LED_P3.C, LED_R3.C, LED_S3.C, LED_T3.C, LED_U3.C, SV2.10
K4: LED_A4.C, LED_B4.C, LED_C4.C, LED_D4.C, LED_E4.C, LED_F4.C, LED_G4.C, LED_H4.C, LED_K4.C, LED_M4.C, LED_N4.C, LED_P4.C, LED_R4.C, LED_S4.C, LED_T4.C, LED_U4.C, SV2.11
K5: SV2.12
SEG_A: LED_A1.A, LED_A2.A, LED_A3.A, LED_A4.A, LED_SEL1.A, SV1.1
SEG_B: LED_B1.A, LED_B2.A, LED_B3.A, LED_B4.A, LED_SEL2.A, SV1.2
SEG_C: LED_C1.A, LED_C2.A, LED_C3.A, LED_C4.A, SV1.3
SEG_D: LED_D1.A, LED_D2.A, LED_D3.A, LED_D4.A, SV1.4
SEG_E: LED_E1.A, LED_E2.A, LED_E3.A, LED_E4.A, SV1.5
SEG_F: LED_F1.A, LED_F2.A, LED_F3.A, LED_F4.A, SV1.6
SEG_G: LED_G1.A, LED_G2.A, LED_G3.A, LED_G4.A, SV1.7
SEG_H: LED_H1.A, LED_H2.A, LED_H3.A, LED_H4.A, SV1.8
SEG_K: LED_K1.A, LED_K2.A, LED_K3.A, LED_K4.A, SV1.9
SEG_M: LED_M1.A, LED_M2.A, LED_M3.A, LED_M4.A, SV1.10
SEG_N: LED_N1.A, LED_N2.A, LED_N3.A, LED_N4.A, SV2.1
SEG_P: LED_P1.A, LED_P2.A, LED_P3.A, LED_P4.A, SV2.2
SEG_R: LED_R1.A, LED_R2.A, LED_R3.A, LED_R4.A, SV2.3
SEG_S: LED_S1.A, LED_S2.A, LED_S3.A, LED_S4.A, SV2.4
SEG_T: LED_T1.A, LED_T2.A, LED_T3.A, LED_T4.A, SV2.5
SEG_U: LED_U1.A, LED_U2.A, LED_U3.A, LED_U4.A, SV2.6

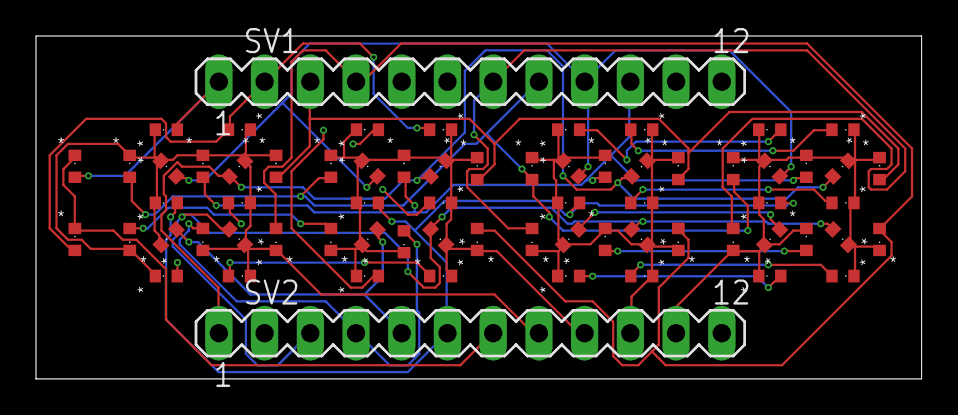
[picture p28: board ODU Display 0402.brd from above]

Board: 4 copper layers, 49.2 x 19.1 mm, 68 parts (0 on the bottom side), 21 nets.

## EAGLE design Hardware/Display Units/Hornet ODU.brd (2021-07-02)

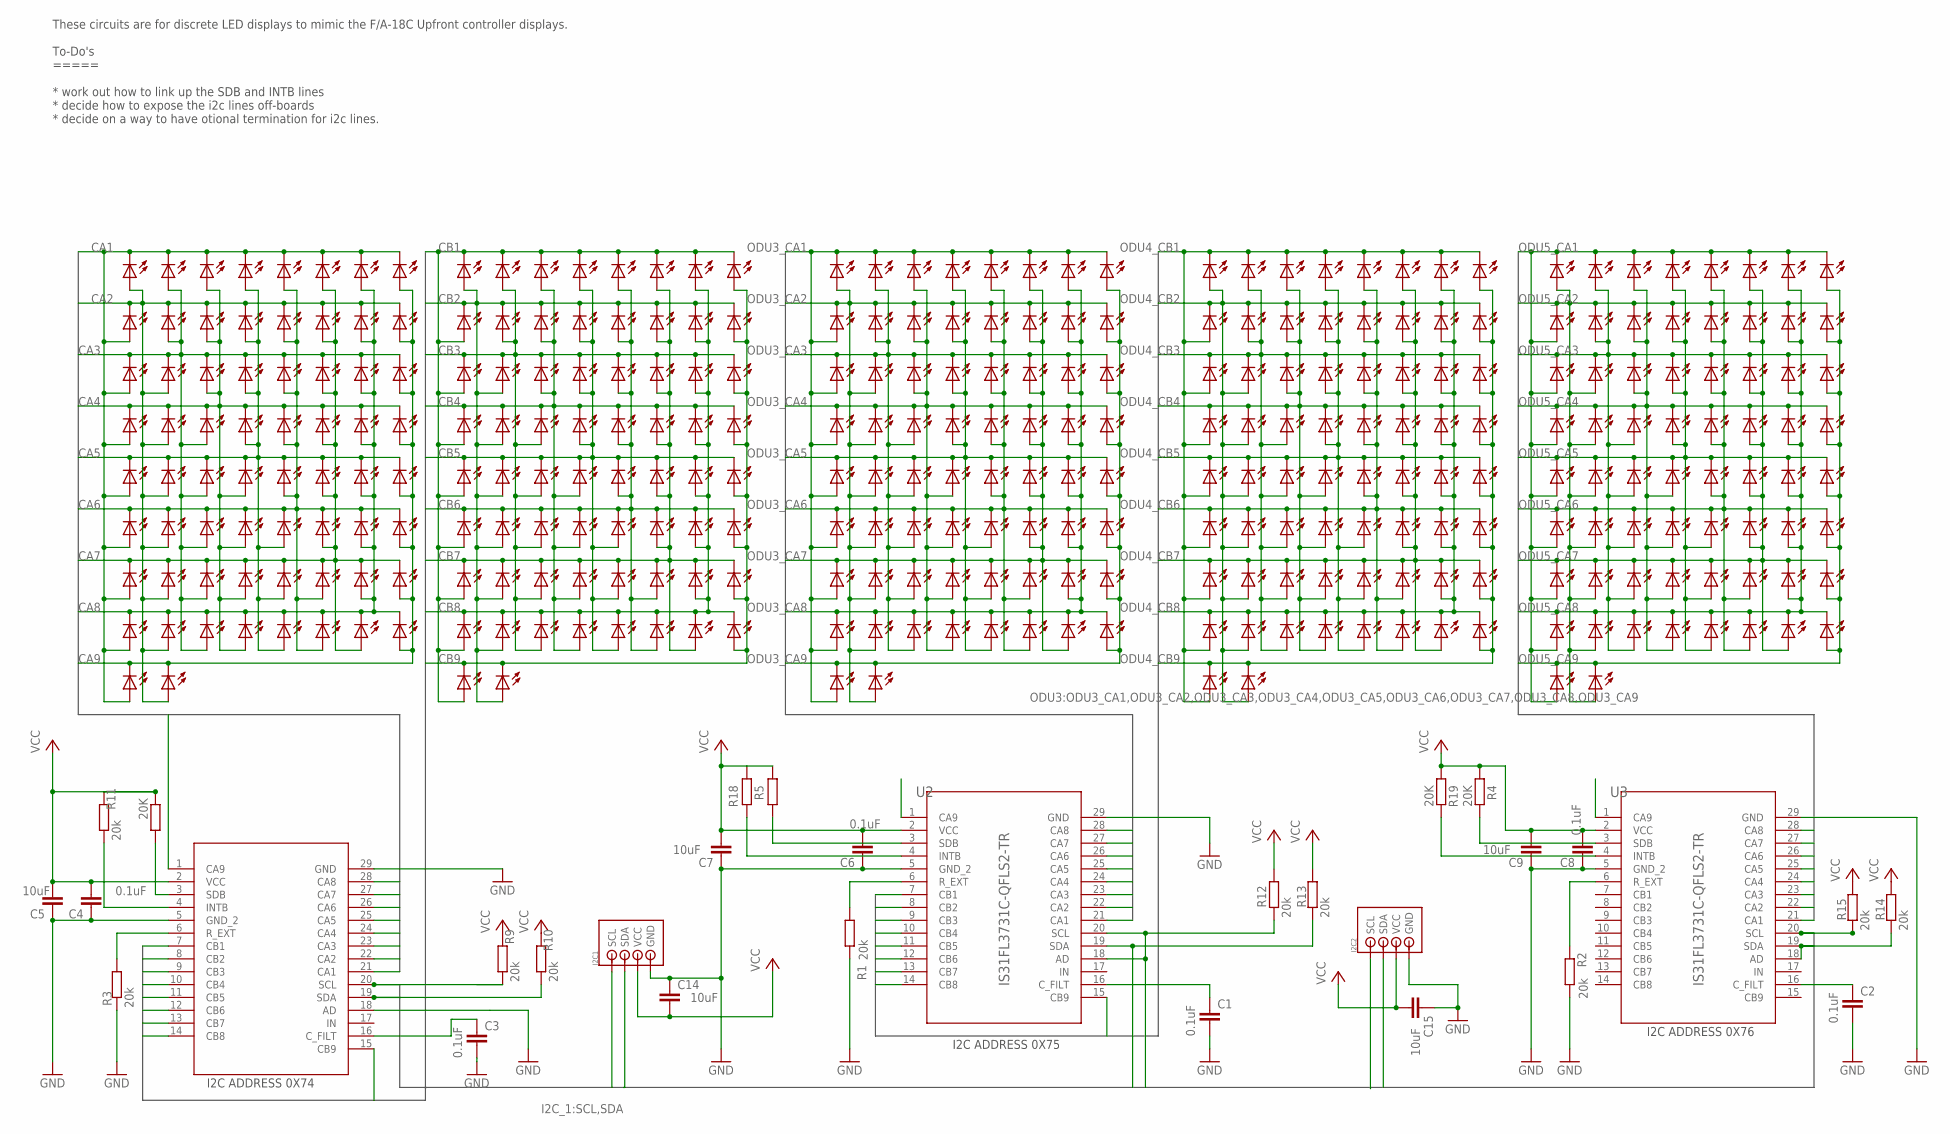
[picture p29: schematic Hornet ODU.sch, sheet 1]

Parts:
C1, C2, C3, C4, C6, C8: 0.1uF; C0805
C5, C7, C9, C14, C15: 10uF; C0805
I2C1, I2C2: I2C_STEMMA_JST_PH_CONNECTORTHROUGH_HOLE; B4B-PH-SOLDER
LED_A5, LED_A6, LED_A7, LED_A8, LED_A9, LED_A10, LED_A11, LED_A12, LED_A13, LED_A14, LED_A15, LED_A16, LED_A17, LED_A18, LED_A19, LED_A20, LED_A21, LED_A22, LED_A23, LED_A24: LEDSMT0603_1; CHIPLED_0603
LED_B5, LED_B6, LED_B7, LED_B8, LED_B9, LED_B10, LED_B11, LED_B12, LED_B13, LED_B14, LED_B15, LED_B16, LED_B17, LED_B18, LED_B19, LED_B20, LED_B21, LED_B22, LED_B23, LED_B24: LEDSMT0603_1; CHIPLED_0603
LED_C5, LED_C6, LED_C7, LED_C8, LED_C9, LED_C10, LED_C11, LED_C12, LED_C13, LED_C14, LED_C15, LED_C16, LED_C17, LED_C18, LED_C19, LED_C20, LED_C21, LED_C22, LED_C23, LED_C24: LEDSMT0603_1; CHIPLED_0603
LED_D5, LED_D6, LED_D7, LED_D8, LED_D9, LED_D10, LED_D11, LED_D12, LED_D13, LED_D14, LED_D15, LED_D16, LED_D17, LED_D18, LED_D19, LED_D20, LED_D21, LED_D22, LED_D23, LED_D24: LEDSMT0603_1; CHIPLED_0603
LED_E5, LED_E6, LED_E7, LED_E8, LED_E9, LED_E10, LED_E11, LED_E12, LED_E13, LED_E14, LED_E15, LED_E16, LED_E17, LED_E18, LED_E19, LED_E20, LED_E21, LED_E22, LED_E23, LED_E24: LEDSMT0603_1; CHIPLED_0603
LED_F5, LED_F6, LED_F7, LED_F8, LED_F9, LED_F10, LED_F11, LED_F12, LED_F13, LED_F14, LED_F15, LED_F16, LED_F17, LED_F18, LED_F19, LED_F20, LED_F21, LED_F22, LED_F23, LED_F24: LEDSMT0603_1; CHIPLED_0603
LED_G5, LED_G6, LED_G7, LED_G8, LED_G9, LED_G10, LED_G11, LED_G12, LED_G13, LED_G14, LED_G15, LED_G16, LED_G17, LED_G18, LED_G19, LED_G20, LED_G21, LED_G22, LED_G23, LED_G24: LEDSMT0603_1; CHIPLED_0603
LED_H5, LED_H6, LED_H7, LED_H8, LED_H9, LED_H10, LED_H11, LED_H12, LED_H13, LED_H14, LED_H15, LED_H16, LED_H17, LED_H18, LED_H19, LED_H20, LED_H21, LED_H22, LED_H23, LED_H24: LEDSMT0603_1; CHIPLED_0603
LED_K5, LED_K6, LED_K7, LED_K8, LED_K9, LED_K10, LED_K11, LED_K12, LED_K13, LED_K14, LED_K15, LED_K16, LED_K17, LED_K18, LED_K19, LED_K20, LED_K21, LED_K22, LED_K23, LED_K24: LEDSMT0603_1; CHIPLED_0603
LED_M5, LED_M6, LED_M7, LED_M8, LED_M9, LED_M10, LED_M11, LED_M12, LED_M13, LED_M14, LED_M15, LED_M16, LED_M17, LED_M18, LED_M19, LED_M20, LED_M21, LED_M22, LED_M23, LED_M24: LEDSMT0603_1; CHIPLED_0603
LED_N5, LED_N6, LED_N7, LED_N8, LED_N9, LED_N10, LED_N11, LED_N12, LED_N13, LED_N14, LED_N15, LED_N16, LED_N17, LED_N18, LED_N19, LED_N20, LED_N21, LED_N22, LED_N23, LED_N24: LEDSMT0603_1; CHIPLED_0603
LED_P5, LED_P6, LED_P7, LED_P8, LED_P9, LED_P10, LED_P11, LED_P12, LED_P13, LED_P14, LED_P15, LED_P16, LED_P17, LED_P18, LED_P19, LED_P20, LED_P21, LED_P22, LED_P23, LED_P24: LEDSMT0603_1; CHIPLED_0603
LED_R5, LED_R6, LED_R7, LED_R8, LED_R9, LED_R10, LED_R11, LED_R12, LED_R13, LED_R14, LED_R15, LED_R16, LED_R17, LED_R18, LED_R19, LED_R20, LED_R21, LED_R22, LED_R23, LED_R24: LEDSMT0603_1; CHIPLED_0603
LED_S5, LED_S6, LED_S7, LED_S8, LED_S9, LED_S10, LED_S11, LED_S12, LED_S13, LED_S14, LED_S15, LED_S16, LED_S17, LED_S18, LED_S19, LED_S20, LED_S21, LED_S22, LED_S23, LED_S24: LEDSMT0603_1; CHIPLED_0603
LED_SEL3, LED_SEL4, LED_SEL5, LED_SEL6, LED_SEL7, LED_SEL8, LED_SEL9, LED_SEL10, LED_SEL11, LED_SEL12: LEDSMT0603_1; CHIPLED_0603
LED_T5, LED_T6, LED_T7, LED_T8, LED_T9, LED_T10, LED_T11, LED_T12, LED_T13, LED_T14, LED_T15, LED_T16, LED_T17, LED_T18, LED_T19, LED_T20, LED_T21, LED_T22, LED_T23, LED_T24: LEDSMT0603_1; CHIPLED_0603
LED_U5, LED_U6, LED_U7, LED_U8, LED_U9, LED_U10, LED_U11, LED_U12, LED_U13, LED_U14, LED_U15, LED_U16, LED_U17, LED_U18, LED_U19, LED_U20, LED_U21, LED_U22, LED_U23, LED_U24: LEDSMT0603_1; CHIPLED_0603
R1, R2, R3, R9, R10, R11, R12, R13, R14, R15: 20k; R0805
R4, R5, R6, R18, R19: 20K; R0805
U1, U2, U3: IS31FL3731C-QFLS2-TR; QFN-28_ISI

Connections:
CA1: LED_A5.C, LED_A6.A, LED_A7.A, LED_A8.A, LED_B5.C, LED_C5.C, LED_D5.C, LED_E5.C, LED_F5.C, LED_G5.C, LED_H5.C, LED_K5.A, LED_K6.A, LED_K7.A, LED_K8.A, LED_SEL3.A, U1.21 (CA1)
CA2: LED_A5.A, LED_B6.A, LED_B7.A, LED_B8.A, LED_K5.C, LED_M5.C, LED_M6.A, LED_M7.A, LED_M8.A, LED_N5.C, LED_P5.C, LED_R5.C, LED_S5.C, LED_SEL4.A, LED_T5.C, LED_U5.C, U1.22 (CA2)
CA3: LED_A6.C, LED_B5.A, LED_B6.C, LED_C6.C, LED_C7.A, LED_C8.A, LED_D6.C, LED_E6.C, LED_F6.C, LED_G6.C, LED_H6.C, LED_M5.A, LED_N6.A, LED_N7.A, LED_N8.A, U1.23 (CA3)
CA4: LED_C5.A, LED_C6.A, LED_D7.A, LED_D8.A, LED_K6.C, LED_M6.C, LED_N5.A, LED_N6.C, LED_P6.C, LED_P7.A, LED_P8.A, LED_R6.C, LED_S6.C, LED_T6.C, LED_U6.C, U1.24 (CA4)
CA5: LED_A7.C, LED_B7.C, LED_C7.C, LED_D5.A, LED_D6.A, LED_D7.C, LED_E7.C, LED_E8.A, LED_F7.C, LED_G7.C, LED_H7.C, LED_P5.A, LED_P6.A, LED_R7.A, LED_R8.A, U1.25 (CA5)
CA6: LED_E5.A, LED_E6.A, LED_E7.A, LED_F8.A, LED_K7.C, LED_M7.C, LED_N7.C, LED_P7.C, LED_R5.A, LED_R6.A, LED_R7.C, LED_S7.C, LED_S8.A, LED_T7.C, LED_U7.C, U1.26 (CA6)
CA7: LED_A8.C, LED_B8.C, LED_C8.C, LED_D8.C, LED_E8.C, LED_F5.A, LED_F6.A, LED_F7.A, LED_F8.C, LED_G8.C, LED_H8.C, LED_S5.A, LED_S6.A, LED_S7.A, LED_T8.A, U1.27 (CA7)
CA8: LED_G5.A, LED_G6.A, LED_G7.A, LED_G8.A, LED_K8.C, LED_M8.C, LED_N8.C, LED_P8.C, LED_R8.C, LED_S8.C, LED_T5.A, LED_T6.A, LED_T7.A, LED_T8.C, LED_U8.C, U1.28 (CA8)
CA9: LED_H5.A, LED_H6.A, LED_H7.A, LED_H8.A, LED_SEL3.C, LED_SEL4.C, LED_U5.A, LED_U6.A, LED_U7.A, LED_U8.A, U1.1 (CA9)
CB1: LED_A9.C, LED_A10.A, LED_A11.A, LED_A12.A, LED_B9.C, LED_C9.C, LED_D9.C, LED_E9.C, LED_F9.C, LED_G9.C, LED_H9.C, LED_K9.A, LED_K10.A, LED_K11.A, LED_K12.A, LED_SEL5.A, U1.7 (CB1)
CB2: LED_A9.A, LED_B10.A, LED_B11.A, LED_B12.A, LED_K9.C, LED_M9.C, LED_M10.A, LED_M11.A, LED_M12.A, LED_N9.C, LED_P9.C, LED_R9.C, LED_S9.C, LED_SEL6.A, LED_T9.C, LED_U9.C, U1.8 (CB2)
CB3: LED_A10.C, LED_B9.A, LED_B10.C, LED_C10.C, LED_C11.A, LED_C12.A, LED_D10.C, LED_E10.C, LED_F10.C, LED_G10.C, LED_H10.C, LED_M9.A, LED_N10.A, LED_N11.A, LED_N12.A, U1.9 (CB3)
CB4: LED_C9.A, LED_C10.A, LED_D11.A, LED_D12.A, LED_K10.C, LED_M10.C, LED_N9.A, LED_N10.C, LED_P10.C, LED_P11.A, LED_P12.A, LED_R10.C, LED_S10.C, LED_T10.C, LED_U10.C, U1.10 (CB4)
CB5: LED_A11.C, LED_B11.C, LED_C11.C, LED_D9.A, LED_D10.A, LED_D11.C, LED_E11.C, LED_E12.A, LED_F11.C, LED_G11.C, LED_H11.C, LED_P9.A, LED_P10.A, LED_R11.A, LED_R12.A, U1.11 (CB5)
CB6: LED_E9.A, LED_E10.A, LED_E11.A, LED_F12.A, LED_K11.C, LED_M11.C, LED_N11.C, LED_P11.C, LED_R9.A, LED_R10.A, LED_R11.C, LED_S11.C, LED_S12.A, LED_T11.C, LED_U11.C, U1.12 (CB6)
CB7: LED_A12.C, LED_B12.C, LED_C12.C, LED_D12.C, LED_E12.C, LED_F9.A, LED_F10.A, LED_F11.A, LED_F12.C, LED_G12.C, LED_H12.C, LED_S9.A, LED_S10.A, LED_S11.A, LED_T12.A, U1.13 (CB7)
CB8: LED_G9.A, LED_G10.A, LED_G11.A, LED_G12.A, LED_K12.C, LED_M12.C, LED_N12.C, LED_P12.C, LED_R12.C, LED_S12.C, LED_T9.A, LED_T10.A, LED_T11.A, LED_T12.C, LED_U12.C, U1.14 (CB8)
CB9: LED_H9.A, LED_H10.A, LED_H11.A, LED_H12.A, LED_SEL5.C, LED_SEL6.C, LED_U9.A, LED_U10.A, LED_U11.A, LED_U12.A, U1.15 (CB9)
GND: C1.2, C2.2, C3.2, C4.1, C5.1, C6.1, C7.1, C8.1, C9.1, C14.1, C15.1, I2C1.P1 (GND), I2C2.P1 (GND), R1.2, R2.2, R3.2, U1.5 (GND_2), U1.18 (AD), U1.29 (GND), U2.5 (GND_2), U2.29 (GND), U3.5 (GND_2), U3.29 (GND); also elsewhere on the board
unnamed: R1.1, U2.6 (R_EXT)
unnamed: R2.1, U3.6 (R_EXT)
unnamed: R3.1, U1.6 (R_EXT)
unnamed: C3.1, U1.16 (C_FILT)
unnamed: C1.1, U2.16 (C_FILT)
unnamed: C2.1, U3.16 (C_FILT)
unnamed: R6.2, U1.3 (SDB)
unnamed: R5.2, U2.3 (SDB)
unnamed: R4.2, U3.3 (SDB)
unnamed: R11.2, U1.4 (INTB)
unnamed: R19.2, U3.4 (INTB)
unnamed: R18.2, U2.4 (INTB)
ODU3_CA1: LED_A13.C, LED_A14.A, LED_A15.A, LED_A16.A, LED_B13.C, LED_C13.C, LED_D13.C, LED_E13.C, LED_F13.C, LED_G13.C, LED_H13.C, LED_K13.A, LED_K14.A, LED_K15.A, LED_K16.A, LED_SEL7.A, U2.21 (CA1)
ODU3_CA2: LED_A13.A, LED_B14.A, LED_B15.A, LED_B16.A, LED_K13.C, LED_M13.C, LED_M14.A, LED_M15.A, LED_M16.A, LED_N13.C, LED_P13.C, LED_R13.C, LED_S13.C, LED_SEL8.A, LED_T13.C, LED_U13.C, U2.22 (CA2)
ODU3_CA3: LED_A14.C, LED_B13.A, LED_B14.C, LED_C14.C, LED_C15.A, LED_C16.A, LED_D14.C, LED_E14.C, LED_F14.C, LED_G14.C, LED_H14.C, LED_M13.A, LED_N14.A, LED_N15.A, LED_N16.A, U2.23 (CA3)
ODU3_CA4: LED_C13.A, LED_C14.A, LED_D15.A, LED_D16.A, LED_K14.C, LED_M14.C, LED_N13.A, LED_N14.C, LED_P14.C, LED_P15.A, LED_P16.A, LED_R14.C, LED_S14.C, LED_T14.C, LED_U14.C, U2.24 (CA4)
ODU3_CA5: LED_A15.C, LED_B15.C, LED_C15.C, LED_D13.A, LED_D14.A, LED_D15.C, LED_E15.C, LED_E16.A, LED_F15.C, LED_G15.C, LED_H15.C, LED_P13.A, LED_P14.A, LED_R15.A, LED_R16.A, U2.25 (CA5)
ODU3_CA6: LED_E13.A, LED_E14.A, LED_E15.A, LED_F16.A, LED_K15.C, LED_M15.C, LED_N15.C, LED_P15.C, LED_R13.A, LED_R14.A, LED_R15.C, LED_S15.C, LED_S16.A, LED_T15.C, LED_U15.C, U2.26 (CA6)
ODU3_CA7: LED_A16.C, LED_B16.C, LED_C16.C, LED_D16.C, LED_E16.C, LED_F13.A, LED_F14.A, LED_F15.A, LED_F16.C, LED_G16.C, LED_H16.C, LED_S13.A, LED_S14.A, LED_S15.A, LED_T16.A, U2.27 (CA7)
ODU3_CA8: LED_G13.A, LED_G14.A, LED_G15.A, LED_G16.A, LED_K16.C, LED_M16.C, LED_N16.C, LED_P16.C, LED_R16.C, LED_S16.C, LED_T13.A, LED_T14.A, LED_T15.A, LED_T16.C, LED_U16.C, U2.28 (CA8)
ODU3_CA9: LED_H13.A, LED_H14.A, LED_H15.A, LED_H16.A, LED_SEL7.C, LED_SEL8.C, LED_U13.A, LED_U14.A, LED_U15.A, LED_U16.A, U2.1 (CA9)
ODU4_CB1: LED_A17.C, LED_A18.A, LED_A19.A, LED_A20.A, LED_B17.C, LED_C17.C, LED_D17.C, LED_E17.C, LED_F17.C, LED_G17.C, LED_H17.C, LED_K17.A, LED_K18.A, LED_K19.A, LED_K20.A, LED_SEL9.A, U2.7 (CB1)
ODU4_CB2: LED_A17.A, LED_B18.A, LED_B19.A, LED_B20.A, LED_K17.C, LED_M17.C, LED_M18.A, LED_M19.A, LED_M20.A, LED_N17.C, LED_P17.C, LED_R17.C, LED_S17.C, LED_SEL10.A, LED_T17.C, LED_U17.C, U2.8 (CB2)
ODU4_CB3: LED_A18.C, LED_B17.A, LED_B18.C, LED_C18.C, LED_C19.A, LED_C20.A, LED_D18.C, LED_E18.C, LED_F18.C, LED_G18.C, LED_H18.C, LED_M17.A, LED_N18.A, LED_N19.A, LED_N20.A, U2.9 (CB3)
ODU4_CB4: LED_C17.A, LED_C18.A, LED_D19.A, LED_D20.A, LED_K18.C, LED_M18.C, LED_N17.A, LED_N18.C, LED_P18.C, LED_P19.A, LED_P20.A, LED_R18.C, LED_S18.C, LED_T18.C, LED_U18.C, U2.10 (CB4)
ODU4_CB5: LED_A19.C, LED_B19.C, LED_C19.C, LED_D17.A, LED_D18.A, LED_D19.C, LED_E19.C, LED_E20.A, LED_F19.C, LED_G19.C, LED_H19.C, LED_P17.A, LED_P18.A, LED_R19.A, LED_R20.A, U2.11 (CB5)
ODU4_CB6: LED_E17.A, LED_E18.A, LED_E19.A, LED_F20.A, LED_K19.C, LED_M19.C, LED_N19.C, LED_P19.C, LED_R17.A, LED_R18.A, LED_R19.C, LED_S19.C, LED_S20.A, LED_T19.C, LED_U19.C, U2.12 (CB6)
ODU4_CB7: LED_A20.C, LED_B20.C, LED_C20.C, LED_D20.C, LED_E20.C, LED_F17.A, LED_F18.A, LED_F19.A, LED_F20.C, LED_G20.C, LED_H20.C, LED_S17.A, LED_S18.A, LED_S19.A, LED_T20.A, U2.13 (CB7)
ODU4_CB8: LED_G17.A, LED_G18.A, LED_G19.A, LED_G20.A, LED_K20.C, LED_M20.C, LED_N20.C, LED_P20.C, LED_R20.C, LED_S20.C, LED_T17.A, LED_T18.A, LED_T19.A, LED_T20.C, LED_U20.C, U2.14 (CB8)
ODU4_CB9: LED_H17.A, LED_H18.A, LED_H19.A, LED_H20.A, LED_SEL9.C, LED_SEL10.C, LED_U17.A, LED_U18.A, LED_U19.A, LED_U20.A, U2.15 (CB9)
ODU5_CA1: LED_A21.C, LED_A22.A, LED_A23.A, LED_A24.A, LED_B21.C, LED_C21.C, LED_D21.C, LED_E21.C, LED_F21.C, LED_G21.C, LED_H21.C, LED_K21.A, LED_K22.A, LED_K23.A, LED_K24.A, LED_SEL11.A, U3.21 (CA1)
ODU5_CA2: LED_A21.A, LED_B22.A, LED_B23.A, LED_B24.A, LED_K21.C, LED_M21.C, LED_M22.A, LED_M23.A, LED_M24.A, LED_N21.C, LED_P21.C, LED_R21.C, LED_S21.C, LED_SEL12.A, LED_T21.C, LED_U21.C, U3.22 (CA2)
ODU5_CA3: LED_A22.C, LED_B21.A, LED_B22.C, LED_C22.C, LED_C23.A, LED_C24.A, LED_D22.C, LED_E22.C, LED_F22.C, LED_G22.C, LED_H22.C, LED_M21.A, LED_N22.A, LED_N23.A, LED_N24.A, U3.23 (CA3)
ODU5_CA4: LED_C21.A, LED_C22.A, LED_D23.A, LED_D24.A, LED_K22.C, LED_M22.C, LED_N21.A, LED_N22.C, LED_P22.C, LED_P23.A, LED_P24.A, LED_R22.C, LED_S22.C, LED_T22.C, LED_U22.C, U3.24 (CA4)
ODU5_CA5: LED_A23.C, LED_B23.C, LED_C23.C, LED_D21.A, LED_D22.A, LED_D23.C, LED_E23.C, LED_E24.A, LED_F23.C, LED_G23.C, LED_H23.C, LED_P21.A, LED_P22.A, LED_R23.A, LED_R24.A, U3.25 (CA5)
ODU5_CA6: LED_E21.A, LED_E22.A, LED_E23.A, LED_F24.A, LED_K23.C, LED_M23.C, LED_N23.C, LED_P23.C, LED_R21.A, LED_R22.A, LED_R23.C, LED_S23.C, LED_S24.A, LED_T23.C, LED_U23.C, U3.26 (CA6)
ODU5_CA7: LED_A24.C, LED_B24.C, LED_C24.C, LED_D24.C, LED_E24.C, LED_F21.A, LED_F22.A, LED_F23.A, LED_F24.C, LED_G24.C, LED_H24.C, LED_S21.A, LED_S22.A, LED_S23.A, LED_T24.A, U3.27 (CA7)
ODU5_CA8: LED_G21.A, LED_G22.A, LED_G23.A, LED_G24.A, LED_K24.C, LED_M24.C, LED_N24.C, LED_P24.C, LED_R24.C, LED_S24.C, LED_T21.A, LED_T22.A, LED_T23.A, LED_T24.C, LED_U24.C, U3.28 (CA8)
ODU5_CA9: LED_H21.A, LED_H22.A, LED_H23.A, LED_H24.A, LED_SEL11.C, LED_SEL12.C, LED_U21.A, LED_U22.A, LED_U23.A, LED_U24.A, U3.1 (CA9)
SCL: I2C1.P4 (SCL), I2C2.P4 (SCL), R9.2, R12.2, R15.2, U1.20 (SCL), U2.18 (AD), U2.20 (SCL), U3.20 (SCL); also elsewhere on the board
SDA: I2C1.P3 (SDA), I2C2.P3 (SDA), R10.2, R13.2, R14.2, U1.19 (SDA), U2.19 (SDA), U3.18 (AD), U3.19 (SDA); also elsewhere on the board
VCC: C4.2, C5.2, C6.2, C7.2, C8.2, C9.2, C14.2, C15.2, I2C1.P2 (VCC), I2C2.P2 (VCC), R4.1, R5.1, R6.1, R9.1, R10.1, R11.1, R12.1, R13.1, R14.1, R15.1, R18.1, R19.1, U1.2 (VCC), U2.2 (VCC), U3.2 (VCC); also elsewhere on the board

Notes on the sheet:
I2C ADDRESS 0X74
I2C ADDRESS 0X75
I2C ADDRESS 0X76
These circuits are for discrete LED displays to mimic the F/A-18C Upfront controller displays. To-Do's ===== * work out how to link up the SDB and INTB lines * decide how to expose the i2c lines off-boards * decide on a way to have otional termination for i2c lines.

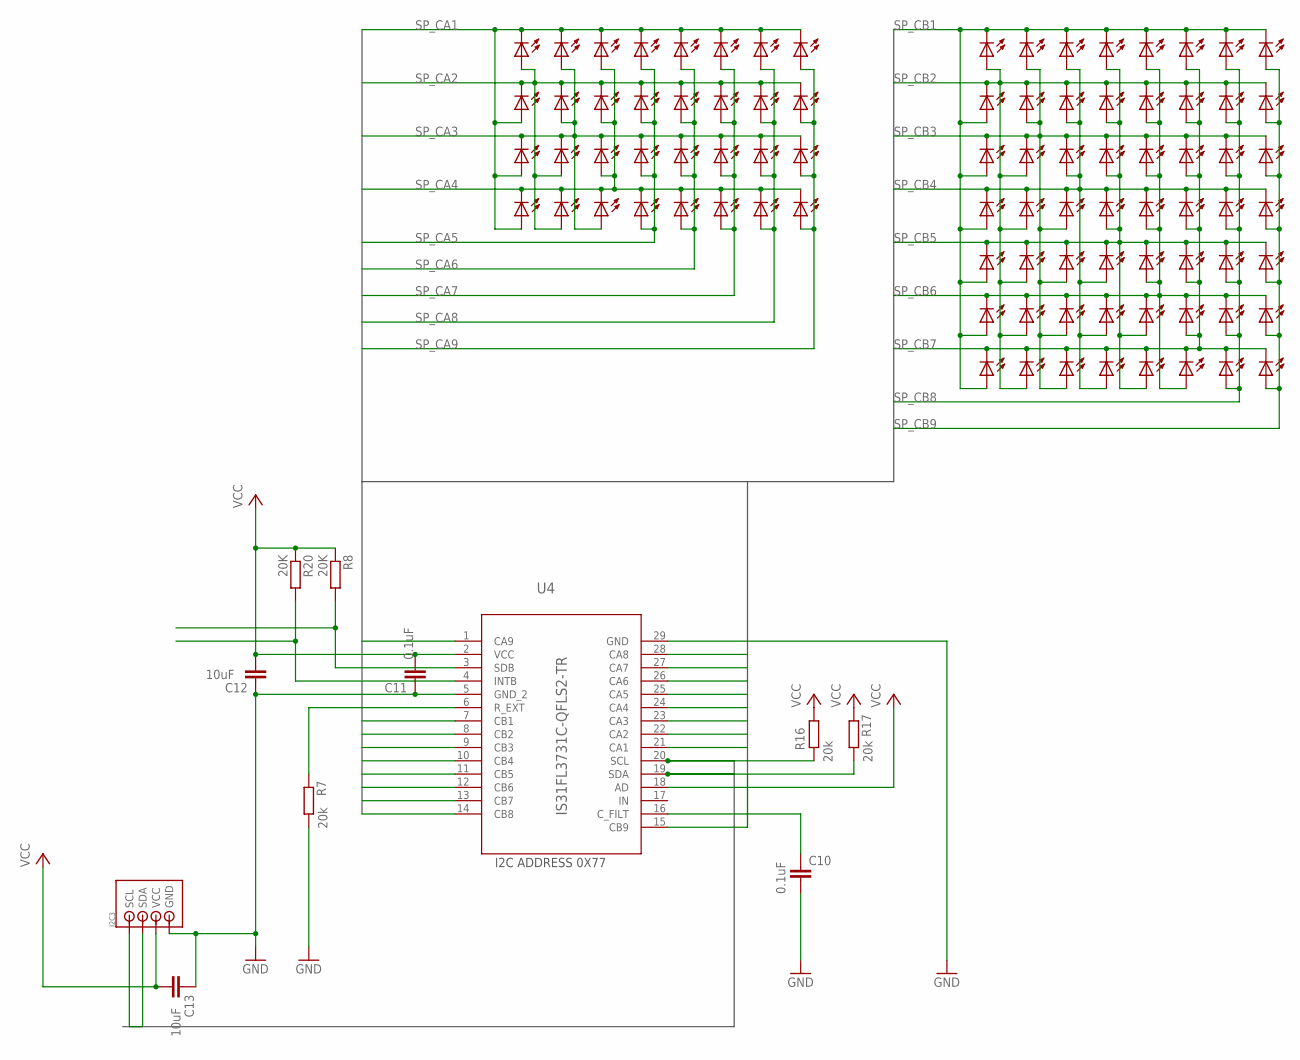
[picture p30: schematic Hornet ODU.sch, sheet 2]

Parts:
C10, C11: 0.1uF; C0805
C12, C13: 10uF; C0805
I2C3: I2C_STEMMA_JST_PH_CONNECTORTHROUGH_HOLE; B4B-PH-SOLDER
LED_A3, LED_A4: LEDSMT0603_1; CHIPLED_0603
LED_B3, LED_B4: LEDSMT0603_1; CHIPLED_0603
LED_C3, LED_C4: LEDSMT0603_1; CHIPLED_0603
LED_D3, LED_D4: LEDSMT0603_1; CHIPLED_0603
LED_DA8, LED_DA9, LED_DA10, LED_DA11, LED_DA12, LED_DA13, LED_DA14: LEDSMT0603_1; CHIPLED_0603
LED_DB8, LED_DB9, LED_DB10, LED_DB11, LED_DB12, LED_DB13, LED_DB14: LEDSMT0603_1; CHIPLED_0603
LED_DC8, LED_DC9, LED_DC10, LED_DC11, LED_DC12, LED_DC13, LED_DC14: LEDSMT0603_1; CHIPLED_0603
LED_DD8, LED_DD9, LED_DD10, LED_DD11, LED_DD12, LED_DD13, LED_DD14: LEDSMT0603_1; CHIPLED_0603
LED_DE8, LED_DE9, LED_DE10, LED_DE11, LED_DE12, LED_DE13, LED_DE14: LEDSMT0603_1; CHIPLED_0603
LED_DF8, LED_DF9, LED_DF10, LED_DF11, LED_DF12, LED_DF13, LED_DF14: LEDSMT0603_1; CHIPLED_0603
LED_DG8, LED_DG9, LED_DG10, LED_DG11, LED_DG12, LED_DG13, LED_DG14: LEDSMT0603_1; CHIPLED_0603
LED_DP8, LED_DP9, LED_DP10, LED_DP11, LED_DP12, LED_DP13, LED_DP14: LEDSMT0603_1; CHIPLED_0603
LED_E3, LED_E4: LEDSMT0603_1; CHIPLED_0603
LED_F3, LED_F4: LEDSMT0603_1; CHIPLED_0603
LED_G3, LED_G4: LEDSMT0603_1; CHIPLED_0603
LED_H3, LED_H4: LEDSMT0603_1; CHIPLED_0603
LED_K3, LED_K4: LEDSMT0603_1; CHIPLED_0603
LED_M3, LED_M4: LEDSMT0603_1; CHIPLED_0603
LED_N3, LED_N4: LEDSMT0603_1; CHIPLED_0603
LED_P3, LED_P4: LEDSMT0603_1; CHIPLED_0603
LED_R3, LED_R4: LEDSMT0603_1; CHIPLED_0603
LED_S3, LED_S4: LEDSMT0603_1; CHIPLED_0603
LED_T3, LED_T4: LEDSMT0603_1; CHIPLED_0603
LED_U3, LED_U4: LEDSMT0603_1; CHIPLED_0603
R7, R16, R17: 20k; R0805
R8, R20: 20K; R0805
U4: IS31FL3731C-QFLS2-TR; QFN-28_ISI

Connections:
GND: C10.2, C11.1, C12.1, C13.1, I2C3.P1 (GND), R7.2, U4.5 (GND_2), U4.29 (GND); also elsewhere on the board
unnamed: C10.1, U4.16 (C_FILT)
unnamed: R8.2, U4.3 (SDB)
unnamed: R7.1, U4.6 (R_EXT)
unnamed: R20.2, U4.4 (INTB)
SCL: I2C3.P4 (SCL), R16.2, U4.20 (SCL); also elsewhere on the board
SDA: I2C3.P3 (SDA), R17.2, U4.19 (SDA); also elsewhere on the board
SP_CA1: LED_A3.C, LED_A4.A, LED_B3.C, LED_C3.C, LED_D3.C, LED_E3.C, LED_F3.C, LED_G3.C, LED_H3.C, LED_K3.A, LED_K4.A, U4.21 (CA1)
SP_CA2: LED_A3.A, LED_B4.A, LED_K3.C, LED_M3.C, LED_M4.A, LED_N3.C, LED_P3.C, LED_R3.C, LED_S3.C, LED_T3.C, LED_U3.C, U4.22 (CA2)
SP_CA3: LED_A4.C, LED_B3.A, LED_B4.C, LED_C4.C, LED_D4.C, LED_E4.C, LED_F4.C, LED_G4.C, LED_H4.C, LED_M3.A, LED_N4.A, U4.23 (CA3)
SP_CA4: LED_C3.A, LED_C4.A, LED_K4.C, LED_M4.C, LED_N3.A, LED_N4.C, LED_P4.C, LED_R4.C, LED_S4.C, LED_T4.C, LED_U4.C, U4.24 (CA4)
SP_CA5: LED_D3.A, LED_D4.A, LED_P3.A, LED_P4.A, U4.25 (CA5)
SP_CA6: LED_E3.A, LED_E4.A, LED_R3.A, LED_R4.A, U4.26 (CA6)
SP_CA7: LED_F3.A, LED_F4.A, LED_S3.A, LED_S4.A
SP_CA8: LED_G3.A, LED_G4.A, LED_T3.A, LED_T4.A, U4.28 (CA8)
SP_CA9: LED_H3.A, LED_H4.A, LED_U3.A, LED_U4.A, U4.1 (CA9)
SP_CB1: LED_DA8.C, LED_DA9.A, LED_DA10.A, LED_DA11.A, LED_DA12.A, LED_DA13.A, LED_DA14.A, LED_DB8.C, LED_DC8.C, LED_DD9.C, LED_DE8.C, LED_DF9.C, LED_DG8.C, LED_DP9.C, U4.7 (CB1)
SP_CB2: LED_DA8.A, LED_DA9.C, LED_DB9.C, LED_DB10.A, LED_DB11.A, LED_DB12.A, LED_DB13.A, LED_DB14.A, LED_DC9.C, LED_DD8.C, LED_DE9.C, LED_DF8.C, LED_DG9.C, LED_DP8.C, U4.8 (CB2)
SP_CB3: LED_DA10.C, LED_DB8.A, LED_DB9.A, LED_DB10.C, LED_DC10.C, LED_DC11.A, LED_DC12.A, LED_DC13.A, LED_DC14.A, LED_DD11.C, LED_DE10.C, LED_DF11.C, LED_DG10.C, LED_DP11.C, U4.9 (CB3)
SP_CB4: LED_DA11.C, LED_DB11.C, LED_DC8.A, LED_DC9.A, LED_DC10.A, LED_DC11.C, LED_DD10.C, LED_DD12.A, LED_DD13.A, LED_DD14.A, LED_DE11.C, LED_DF10.C, LED_DG11.C, LED_DP10.C, U4.10 (CB4)
SP_CB5: LED_DA12.C, LED_DB12.C, LED_DC12.C, LED_DD8.A, LED_DD9.A, LED_DD10.A, LED_DD11.A, LED_DD13.C, LED_DE12.C, LED_DE13.A, LED_DE14.A, LED_DF13.C, LED_DG12.C, LED_DP13.C, U4.11 (CB5)
SP_CB6: LED_DA13.C, LED_DB13.C, LED_DC13.C, LED_DD12.C, LED_DE8.A, LED_DE9.A, LED_DE10.A, LED_DE11.A, LED_DE12.A, LED_DE13.C, LED_DF12.C, LED_DF14.A, LED_DG13.C, LED_DP12.C, U4.12 (CB6)
SP_CB7: LED_DA14.C, LED_DB14.C, LED_DC14.C, LED_DD14.C, LED_DE14.C, LED_DF8.A, LED_DF9.A, LED_DF10.A, LED_DF11.A, LED_DF12.A, LED_DF13.A, LED_DF14.C, LED_DG14.C, LED_DP14.C, U4.13 (CB7), U4.27 (CA7)
SP_CB8: LED_DG8.A, LED_DG9.A, LED_DG10.A, LED_DG11.A, LED_DG12.A, LED_DG13.A, LED_DG14.A, U4.14 (CB8)
SP_CB9: LED_DP8.A, LED_DP9.A, LED_DP10.A, LED_DP11.A, LED_DP12.A, LED_DP13.A, LED_DP14.A, U4.15 (CB9)
VCC: C11.2, C12.2, C13.2, I2C3.P2 (VCC), R8.1, R16.1, R17.1, R20.1, U4.2 (VCC), U4.18 (AD); also elsewhere on the board

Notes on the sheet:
I2C ADDRESS 0X77

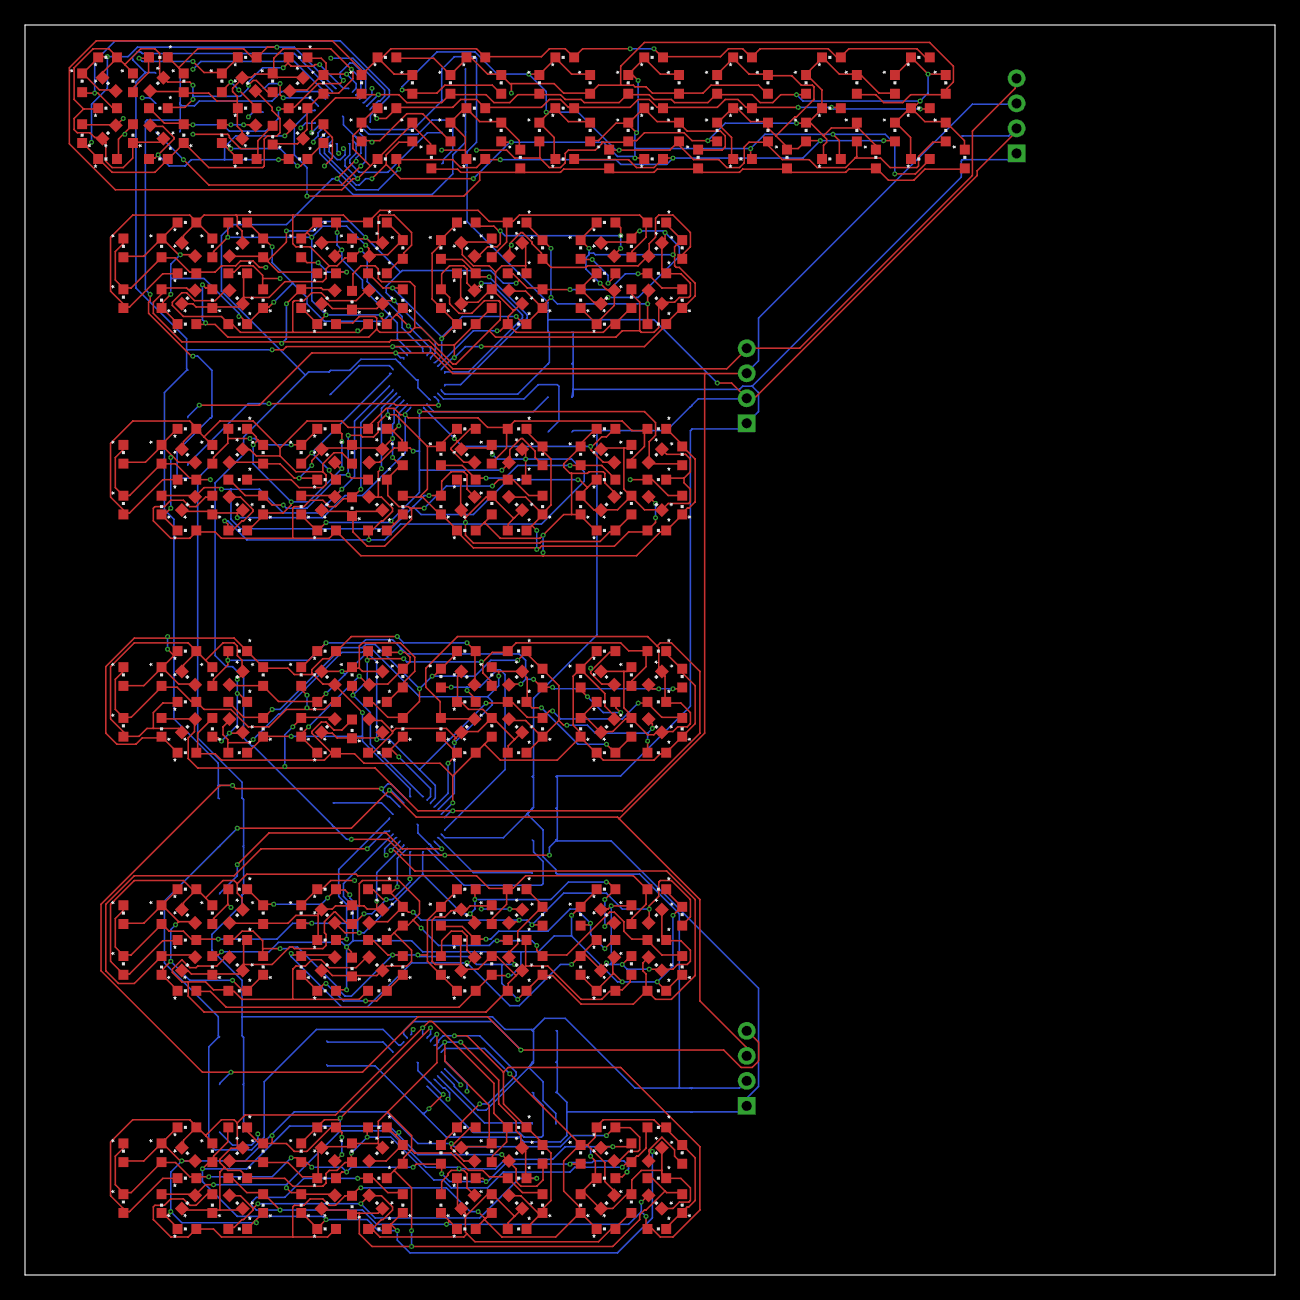
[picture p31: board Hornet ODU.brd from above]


Board: 4 copper layers, 100.0 x 100.0 mm, 460 parts (42 on the bottom side), 83 nets.

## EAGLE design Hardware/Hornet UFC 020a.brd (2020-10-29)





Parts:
74HC138: CD74HC138M; SOIC127P600X175-16N
#0, #1, #2, #3, #4, #5, #6, #7, #8, #9: GATERON-LED
A/P: GATERON-LED
ADF: ADF; B3B-PH-SOLDER
BCN: GATERON-LED
BLANK: SOLDERJUMPERCLOSED; SOLDERJUMPER_CLOSEDWIRE
BRT: ALPS_ENCODER+PUSHSWITCHLARGE_TABS; ENCODER+SWITCH_LARGER_TABS
C2, C3, C5, C7, C8, C9, C10, C11, C12, C13: 100nF; C0805
C4, C6: 0.1uF; C0805
CHANNEL1, CHANNEL2: 16-SEG_THROUGH_HOLEPSC05-11; PSC05-11
CLR: GATERON-LED
CN2: JST-PH-B4B-PH-SM4THRU-HOLE; B4B-PH-SOLDER
D1, D2: BAT54CDW-7-F; SSOT6
D3, D5, D7, D9, D11: LED3MM_V_OFFSET; LED5X2MM_RECT_3MM_VOFFSET
D/L: GATERON-LED
DIS1, DIS2, DIS3: HDLX2416SOCKETED; HDLX2416(SOCKETED)
EMCON: GATERON-LED
ENC_1: JST-PH-B4B-PH-SM4THRU-HOLE; B4B-PH-SOLDER
ENT: GATERON-LED
I/P: GATERON-LED
IFF: GATERON-LED
ILS: GATERON-LED
ODU1, ODU2, ODU3, ODU4, ODU5: GATERON-LED
ODU_DSP_1, ODU_DSP_2, ODU_DSP_3, ODU_DSP_4, ODU_DSP_5: HDLX2416SOCKETED; HDLX2416(SOCKETED)
ON/OFF: GATERON-LED
R1, R49, R50, R51, R52, R53, R54, R55, R56, R57, R58, R59, R60: 39K; R1206
R2, R14: 10K; R0805
R5, R7, R9, R10, R11, R12: R-EU_R0805; R0805
SV2: MA20-2
SW1: ADF_SMALL; MICRO_TOGGLE_SPDT
TCN: GATERON-LED
TP1, TP2, TP3, TP4: PTR1TP13SQ; TP13SQ
U$4: ENC_RGB_L; ENCODER_RGB
U$5, U$21: ALPS_ENCODER+PUSHSWITCHLARGE_TABS; ENCODER+SWITCH_LARGER_TABS
U$7: PCF8575PWR; TSSOP24
U$11: ENC_RGB_R; ENCODER_RGB
U$31: Addr 0x71; SOIC28
U$37: OLED_128X32_I2C_DISPLAYTHROUGH_HOLE; OLED128X32_GRAPHICS_MODULE
VOL1, VOL2: ALPS_ENCODER+PUSHSWITCHLARGE_TABS; ENCODER+SWITCH_LARGER_TABS

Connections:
3.3V: U$4.ANODE (VCC), U$11.ANODE (VCC)
3V3: SV2.1
5V: 74HC138.6 (E3), 74HC138.16 (VCC), C4.2, C6.1, DIS1.5 (!CU), DIS1.9 (VDD), DIS2.5 (!CU), DIS2.9 (VDD), DIS3.5 (!CU), DIS3.9 (VDD), ODU_DSP_1.5 (!CU), ODU_DSP_1.9 (VDD), ODU_DSP_2.5 (!CU), ODU_DSP_2.9 (VDD), ODU_DSP_3.5 (!CU), ODU_DSP_3.9 (VDD), ODU_DSP_4.5 (!CU), ODU_DSP_4.9 (VDD), ODU_DSP_5.5 (!CU), ODU_DSP_5.9 (VDD), SV2.37, U$7.24 (VDD), U$31.28 (VDD), U$37.2 (VCC)
COM_1_0: CHANNEL1.11 (CA), D1.1 (A1), R1.1, U$31.2 (COM0/AD)
COM_1_1: CHANNEL2.11 (CA), D1.4 (A2), U$31.3 (COM1/KS0)
COM_1_2: #0.LED_CATHODE (LED_K), #1.LED_CATHODE (LED_K), #2.LED_CATHODE (LED_K), #3.LED_CATHODE (LED_K), #4.LED_CATHODE (LED_K), #5.LED_CATHODE (LED_K), #6.LED_CATHODE (LED_K), #7.LED_CATHODE (LED_K), #8.LED_CATHODE (LED_K), #9.LED_CATHODE (LED_K), CLR.LED_CATHODE (LED_K), D2.1 (A1), ENT.LED_CATHODE (LED_K), U$31.4 (COM2/KS1)
COM_1_3: A/P.LED_CATHODE (LED_K), BCN.LED_CATHODE (LED_K), D2.4 (A2), D/L.LED_CATHODE (LED_K), EMCON.LED_CATHODE (LED_K), I/P.LED_CATHODE (LED_K), IFF.LED_CATHODE (LED_K), ILS.LED_CATHODE (LED_K), ODU1.LED_CATHODE (LED_K), ODU2.LED_CATHODE (LED_K), ODU3.LED_CATHODE (LED_K), ODU4.LED_CATHODE (LED_K), ODU5.LED_CATHODE (LED_K), ON/OFF.LED_CATHODE (LED_K), TCN.LED_CATHODE (LED_K), U$31.5 (COM3/KS2)
COM_1_4: D3.K (C), D5.K (C), D7.K (C), D9.K (C), D11.K (C), U$31.6 (COM4)
COM_1_5: U$31.7 (COM5)
COM_1_6: U$31.8 (COM6)
COM_1_7: U$31.9 (COM7)
D0: DIS1.11 (D0), DIS2.11 (D0), DIS3.11 (D0), ODU_DSP_1.11 (D0), ODU_DSP_2.11 (D0), ODU_DSP_3.11 (D0), ODU_DSP_4.11 (D0), ODU_DSP_5.11 (D0), U$7.4 (P00)
D1: DIS1.12 (D1), DIS2.12 (D1), DIS3.12 (D1), ODU_DSP_1.12 (D1), ODU_DSP_2.12 (D1), ODU_DSP_3.12 (D1), ODU_DSP_4.12 (D1), ODU_DSP_5.12 (D1), U$7.5 (P01)
D2: DIS1.13 (D2), DIS2.13 (D2), DIS3.13 (D2), ODU_DSP_1.13 (D2), ODU_DSP_2.13 (D2), ODU_DSP_3.13 (D2), ODU_DSP_4.13 (D2), ODU_DSP_5.13 (D2), U$7.6 (P02)
D3: DIS1.14 (D3), DIS2.14 (D3), DIS3.14 (D3), ODU_DSP_1.14 (D3), ODU_DSP_2.14 (D3), ODU_DSP_3.14 (D3), ODU_DSP_4.14 (D3), ODU_DSP_5.14 (D3), U$7.7 (P03)
D4: DIS1.17 (D4), DIS2.17 (D4), DIS3.17 (D4), ODU_DSP_1.17 (D4), ODU_DSP_2.17 (D4), ODU_DSP_3.17 (D4), ODU_DSP_4.17 (D4), ODU_DSP_5.17 (D4), U$7.8 (P04)
D5: DIS1.16 (D5), DIS2.16 (D5), DIS3.16 (D5), ODU_DSP_1.16 (D5), ODU_DSP_2.16 (D5), ODU_DSP_3.16 (D5), ODU_DSP_4.16 (D5), ODU_DSP_5.16 (D5), U$7.9 (P05)
D6: DIS1.15 (D6), DIS2.15 (D6), DIS3.15 (D6), ODU_DSP_1.15 (D6), ODU_DSP_2.15 (D6), ODU_DSP_3.15 (D6), ODU_DSP_4.15 (D6), ODU_DSP_5.15 (D6), U$7.10 (P06)
DSP3: BRT.B, C2.2, SV2.22
DSP_A0: DIS1.8 (A0), DIS2.8 (A0), DIS3.8 (A0), ODU_DSP_1.8 (A0), ODU_DSP_2.8 (A0), ODU_DSP_3.8 (A0), ODU_DSP_4.8 (A0), ODU_DSP_5.8 (A0), U$7.13 (P10)
DSP_A1: DIS1.7 (A1), DIS2.7 (A1), DIS3.7 (A1), ODU_DSP_1.7 (A1), ODU_DSP_2.7 (A1), ODU_DSP_3.7 (A1), ODU_DSP_4.7 (A1), ODU_DSP_5.7 (A1), U$7.14 (P11)
DSP_BL: BLANK.2, DIS1.18 (!BL), DIS2.18 (!BL), DIS3.18 (!BL), ODU_DSP_1.18 (!BL), ODU_DSP_2.18 (!BL), ODU_DSP_3.18 (!BL), ODU_DSP_4.18 (!BL), ODU_DSP_5.18 (!BL), SV2.23
DSP_CLR: DIS1.3 (!CLR), DIS2.3 (!CLR), DIS3.3 (!CLR), ODU_DSP_1.3 (!CLR), ODU_DSP_2.3 (!CLR), ODU_DSP_3.3 (!CLR), ODU_DSP_4.3 (!CLR), ODU_DSP_5.3 (!CLR), U$7.18 (P15)
ENCODER_PWM: R7.1, R11.1, SV2.32
ENCODER_SW_L: R2.1, SV2.17, U$4.SWITCH (E)
ENCODER_SW_R: R14.1, U$11.SWITCH (E)
ESP32_GPIO12: C11.2, ENC_1.P4 (4), SV2.25, U$4.A, U$5.A
ESP32_GPIO13: C10.2, ENC_1.P3 (3), SV2.29, U$4.B, U$5.B
ESP32_GPIO26: C12.2, CN2.P4 (4), SV2.19, U$11.A, U$21.A
ESP32_GPIO27: C13.2, CN2.P3 (3), SV2.21, U$11.B, U$21.B
GND: 74HC138.4 (~E1), 74HC138.5 (~E2), 74HC138.8 (GND), BRT.C, C2.1, C3.2, C5.2, C6.2, C7.2, C8.1, C8.2, C9.2, C10.1, C11.1, C12.1, C13.1, CN2.P1 (1), DIS1.4 (CUE), DIS1.10 (GND), DIS2.4 (CUE), DIS2.10 (GND), DIS3.4 (CUE), DIS3.10 (GND), ENC_1.P1 (1), ODU_DSP_1.4 (CUE), ODU_DSP_1.10 (GND), ODU_DSP_2.4 (CUE), ODU_DSP_2.10 (GND), ODU_DSP_3.4 (CUE), ODU_DSP_3.10 (GND), ODU_DSP_4.4 (CUE), ODU_DSP_4.10 (GND), ODU_DSP_5.4 (CUE), ODU_DSP_5.10 (GND), R2.2, R14.2, SV2.2, SV2.14, SV2.26, SV2.27, U$4.C, U$5.C, U$11.C, U$21.C, U$31.1 (GND/VSS), U$37.1 (GND), VOL1.A, VOL1.C, VOL2.C
I2C_0: SV2.39, U$7.23 (SDA), U$31.27 (SDA), U$37.4 (SDA)
I2C_1: SV2.40, U$7.22 (SCL), U$31.26 (SCL), U$37.3 (SCL)
K3: #1.SW1, ENC_1.P2 (2), ODU1.SW1, R56.2, U$5.E
K4: #2.SW1, A/P.SW1, R57.2
K5: #3.SW1, ADF.P3 (3), IFF.SW1, R59.2, SW1.A$1
K6: #4.SW1, ODU2.SW1, R55.2, TCN.SW1
K7: #5.SW1, ILS.SW1, R58.2
K8: #6.SW1, ADF.P1 (1), D/L.SW1, R60.2, SW1.B$1
K9: #7.SW1, BCN.SW1, ODU3.SW1, R50.2
K10: #8.SW1, ON/OFF.SW1, R52.2
K11: #9.SW1, I/P.SW1, R54.2, U$21.D
K12: CLR.SW1, ODU4.SW1, R49.2
K13: #0.SW1, ODU5.SW1, R51.2
K14: EMCON.SW1, ENT.SW1, R53.2
KS_1_0: #0.SW2, #1.SW2, #2.SW2, #3.SW2, #4.SW2, #5.SW2, #6.SW2, #7.SW2, #8.SW2, #9.SW2, CLR.SW2, D1.3 (C2), ENT.SW2
KS_1_1: ADF.P2 (2), D2.6 (C1), EMCON.SW2, I/P.SW2, ODU1.SW2, ODU2.SW2, ODU3.SW2, ODU4.SW2, ODU5.SW2, SW1.C$1
KS_1_2: A/P.SW2, BCN.SW2, CN2.P2 (2), D2.3 (C2), D/L.SW2, IFF.SW2, ILS.SW2, ON/OFF.SW2, TCN.SW2, U$5.D, U$21.E
unnamed: C4.1, U$7.2 (A1), U$7.3 (A2), U$7.12 (VSS), U$7.21 (A0)
unnamed: R9.2, U$4.BLUE (LED_B)
unnamed: 74HC138.1 (A0), U$7.15 (P12)
unnamed: 74HC138.2 (A1), U$7.16 (P13)
unnamed: BLANK.1, U$7.20 (P17)
unnamed: 74HC138.3 (A2), U$7.17 (P14)
unnamed: 74HC138.10 (~Y5), DIS3.1 (!CE1), DIS3.2 (!CE2)
unnamed: C9.1, SV2.20, VOL1.B
unnamed: 74HC138.7 (~Y7), DIS1.1 (!CE1), DIS1.2 (!CE2)
unnamed: 74HC138.9 (~Y6), DIS2.1 (!CE1), DIS2.2 (!CE2)
unnamed: 74HC138.11 (~Y4), ODU_DSP_1.1 (!CE1), ODU_DSP_1.2 (!CE2)
unnamed: 74HC138.12 (~Y3), ODU_DSP_2.1 (!CE1), ODU_DSP_2.2 (!CE2)
unnamed: 74HC138.13 (~Y2), ODU_DSP_3.1 (!CE1), ODU_DSP_3.2 (!CE2)
unnamed: 74HC138.14 (~Y1), ODU_DSP_4.1 (!CE1), ODU_DSP_4.2 (!CE2)
unnamed: 74HC138.15 (~Y0), ODU_DSP_5.1 (!CE1), ODU_DSP_5.2 (!CE2)
unnamed: DIS1.6 (!WR), DIS2.6 (!WR), DIS3.6 (!WR), ODU_DSP_1.6 (!WR), ODU_DSP_2.6 (!WR), ODU_DSP_3.6 (!WR), ODU_DSP_4.6 (!WR), ODU_DSP_5.6 (!WR), U$7.11 (P07)
unnamed: BRT.A, C3.1, SV2.24
unnamed: R7.2, U$4.GREEN (LED_G)
unnamed: R12.2, U$11.RED (LED_R)
unnamed: R11.2, U$11.GREEN (LED_G)
unnamed: R10.2, U$11.BLUE (LED_B)
unnamed: R5.2, U$4.RED (LED_R)
unnamed: R12.1, TP4.TP
unnamed: R5.1, TP2.TP
unnamed: R9.1, TP1.TP
unnamed: R10.1, TP3.TP
unnamed: C5.1, SV2.18, VOL2.A
unnamed: C7.1, SV2.16, VOL2.B
unnamed: SV2.13, SV2.35
ROW_K_#1_0: #1.LED_ANODE (LED_A), CHANNEL1.1 (A), CHANNEL2.1 (A), ODU1.LED_ANODE (LED_A), U$31.25 (ROW0/A2)
ROW_K_#1_1: #2.LED_ANODE (LED_A), A/P.LED_ANODE (LED_A), CHANNEL1.18 (B), CHANNEL2.18 (B), D11.A, ODU2.LED_ANODE (LED_A), U$31.24 (ROW1/A1)
ROW_K_#1_2: #3.LED_ANODE (LED_A), CHANNEL1.16 (C), CHANNEL2.16 (C), IFF.LED_ANODE (LED_A), ODU3.LED_ANODE (LED_A), R1.2, U$31.23 (ROW2/A0)
ROW_K_#1_3: #4.LED_ANODE (LED_A), CHANNEL1.13 (D), CHANNEL2.13 (D), D9.A, ODU4.LED_ANODE (LED_A), R56.1, TCN.LED_ANODE (LED_A), U$31.22 (ROW3/K1)
ROW_K_#1_4: #5.LED_ANODE (LED_A), CHANNEL1.10 (E), CHANNEL2.10 (E), ILS.LED_ANODE (LED_A), ODU5.LED_ANODE (LED_A), R57.1, U$31.21 (ROW4/K2)
ROW_K_#1_5: #6.LED_ANODE (LED_A), CHANNEL1.9 (F), CHANNEL2.9 (F), D7.A, D/L.LED_ANODE (LED_A), EMCON.LED_ANODE (LED_A), R59.1, U$31.20 (ROW5/K3)
ROW_K_#1_6: #7.LED_ANODE (LED_A), BCN.LED_ANODE (LED_A), CHANNEL1.8 (G), CHANNEL2.8 (G), I/P.LED_ANODE (LED_A), R55.1, U$31.19 (ROW6/K4)
ROW_K_#1_7: #8.LED_ANODE (LED_A), CHANNEL1.4 (H), CHANNEL2.4 (H), D5.A, ON/OFF.LED_ANODE (LED_A), R58.1, U$31.18 (ROW7/K5)
ROW_K_#1_8: #9.LED_ANODE (LED_A), CHANNEL1.3 (K), CHANNEL2.3 (K), R60.1, U$31.17 (ROW8/K6)
ROW_K_#1_9: CHANNEL1.2 (M), CHANNEL2.2 (M), CLR.LED_ANODE (LED_A), D3.A, R50.1, U$31.16 (ROW9/K7)
ROW_K_#1_10: #0.LED_ANODE (LED_A), CHANNEL1.17 (N), CHANNEL2.17 (N), R52.1, U$31.15 (ROW10/K8)
ROW_K_#1_11: CHANNEL1.15, CHANNEL2.15, ENT.LED_ANODE (LED_A), R54.1, U$31.14 (ROW11/K9)
ROW_K_#1_12: CHANNEL1.14 (R), CHANNEL2.14 (R), R49.1, U$31.13 (ROW12/K10)
ROW_K_#1_13: CHANNEL1.6 (S), CHANNEL2.6 (S), R51.1, U$31.12 (ROW13/K11)
ROW_K_#1_14: CHANNEL1.7 (T), CHANNEL2.7 (T), R53.1, U$31.11 (ROW14/K12)
ROW_K_#1_15: CHANNEL1.5 (U), CHANNEL2.5 (U), U$31.10 (ROW15/K13/INT)
SCL3V3: SV2.6
SDA3V1: SV2.4
SDA3V3: SV2.12

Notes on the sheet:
V02
Neil Larmour
Keyboard and LED control is address 0x71 I2C Multiplexer is on 0x70 I2C 16 Bit Expander is on 0x20 OLED display 0x3C
Issues Identified after Manufacture ------------------------------------------- 1) NodeLua board width is 5.08 mm too much 2) DONE - LEDs D3 is incorrectly linked to Row 0 instead of 9. 3) DONE - Chip enable lines need to be inverted. This should be done by replacing the 74HC238 with a 74HC138. 4) 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
Potential Issues ------------------------------------------- 1) DONE - Encoders on RHS too close to displays 2) DONE - Mounting holes for the rotary encoders are not big enough 3) DONE - Toggle switch mounting position too cramped 4) DONE - Ideally the HT16K33 should be address 0x71 5) DONE - GPIO 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
Issues With V2 ------------------------------------------- 1) Board has GND problems. pin header pin 2 is not linkted to GND. Similarly net N$1 should be GND 2) The positioning of the 7 Nav keyswitches is about .5mm too close together because there is a lip on the keyswitch



Board: 2 copper layers, 180.0 x 140.0 mm, 102 parts (42 on the bottom side), 89 nets.

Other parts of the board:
U$3, U$25, U$26, U$34, U$39: DRIL-3

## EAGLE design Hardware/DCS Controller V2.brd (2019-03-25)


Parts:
5VADJUST1: SJ
BUCK_BYPAS: SJ
C15: 10uF; 0805-NO
I2C_0, I2C_1, I2C_2, I2C_3, I2C_4, I2C_5, I2C_6, I2C_7: JST-PH-B4B-PH-SM4THRU-HOLE; B4B-PH-SOLDER
I2C_MSTR: I2C_JST_CONNECTORTHROUGH_HOLE; B4B-PH-SOLDER
J1: JACK-PLUG0; SPC4077
MISO: 1,6/0,9
MLF1: ATTINY1634MLF20; MLF20
MOSI: 1,6/0,9
PB3: 1,6/0,9
Q4, Q5, Q6: BSS138; SOT23-3
R2, R5: 4K7; R0805
R7, R9, R10, R11, R14, R16: 10K; 0603-RES
RST: 1,6/0,9
RX: 1,6/0,9
SCK: 1,6/0,9
SV1: FE20-2
TX: 1,6/0,9
U2: Addr 0x70; TSSOP24
U$26: EBAY_BUCK_CONVERTERMODULE; BUCK_CONVERTER
U$34: ESP32DEVKITC; ESP32-DEVKITC

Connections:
0SCL1: I2C_2.P3 (3), U2.9 (SCL2)
0SCL3: I2C_3.P3 (3), U2.11 (SCL3)
0SCL4: I2C_4.P3 (3), U2.14 (SCL4)
0SCL5: I2C_5.P3 (3), U2.16 (SCL5)
0SCL6: I2C_6.P3 (3), U2.18 (SCL6)
0SCL7: I2C_7.P3 (3), U2.20 (SCL7)
3.3V: SV1.1, U$34.1 (3V3)
3V3: Q4.1 (G), Q5.1 (G), Q6.1 (G), R7.1, R10.1, R14.1
5V: 5VADJUST1.2, C15.1, I2C_0.P2 (2), I2C_1.P2 (2), I2C_2.P2 (2), I2C_3.P2 (2), I2C_4.P2 (2), I2C_5.P2 (2), I2C_6.P2 (2), I2C_7.P2 (2), MLF1.9 (VCC), R9.1, R11.1, R16.1, SV1.37, U2.24 (VCC), U$34.19 (5V)
GND: C15.2, I2C_0.P1 (1), I2C_1.P1 (1), I2C_2.P1 (1), I2C_3.P1 (1), I2C_4.P1 (1), I2C_5.P1 (1), I2C_6.P1 (1), I2C_7.P1 (1), I2C_MSTR.P1 (GND), J1.1, MLF1.8 (GND), MLF1.GND, SV1.14, SV1.27, U2.1 (A0), U2.2 (A1), U2.12 (GND), U2.21 (A2), U$26.IN_-VE_P$4 (P_IN_-VE), U$26.OUT_-VE_P$6 (P_OUT_-VE), U$34.14 (GND), U$34.32 (GND), U$34.GND_32 (GND)
I2C_0: I2C_MSTR.P4 (SDA), Q4.3 (D), R5.1, R9.2, SV1.39, U2.23 (SDA)
I2C_1: I2C_MSTR.P3 (SCL), Q5.3 (D), R2.1, R11.2, SV1.40, U2.22 (SCL)
unnamed: SV1.3, U$34.2 (EN)
unnamed: SV1.5, U$34.3 (SVP)
unnamed: SV1.7, U$34.4 (SVN)
unnamed: SV1.9, U$34.5 (IO34)
unnamed: SV1.11, U$34.6 (IO35)
unnamed: SV1.13, U$34.7 (IO32)
unnamed: SV1.15, U$34.8 (IO33)
unnamed: SV1.17, U$34.9 (IO25)
unnamed: SV1.19, U$34.10 (IO26)
unnamed: SV1.21, U$34.11 (IO27)
unnamed: SV1.23, U$34.12 (IO14)
unnamed: SV1.25, U$34.13 (IO12)
unnamed: SV1.29, U$34.15 (IO13)
unnamed: SV1.31, U$34.16 (SD2)
unnamed: SV1.33, U$34.17 (SD3)
unnamed: SV1.35, U$34.18 (CMD)
unnamed: SV1.2, U$34.38 (GND), U$34.GND_38 (GND)
unnamed: SV1.8, U$34.35 (TXD0), U$34.TXD0
unnamed: SV1.10, U$34.34 (RXD0), U$34.RXD0
unnamed: SV1.16, U$34.31 (IO19), U$34.IO19
unnamed: SV1.18, U$34.30 (IO18), U$34.IO18
unnamed: SV1.20, U$34.29 (IO5), U$34.IO5
unnamed: SV1.22, U$34.28 (IO17), U$34.IO17
unnamed: SV1.24, U$34.27 (IO16), U$34.IO16
unnamed: SV1.26, U$34.26 (IO4), U$34.IO4
unnamed: SV1.28, U$34.25 (IO0), U$34.IO0
unnamed: SV1.30, U$34.24 (IO2), U$34.IO2
unnamed: SV1.32, U$34.23 (IO15), U$34.IO15
unnamed: SV1.34, U$34.22 (SD1), U$34.SD1
unnamed: SV1.36, U$34.21 (SD0), U$34.SD0
unnamed: SV1.38, U$34.20 (CLK), U$34.CLK
unnamed: MLF1.18 (RXD1/ADC6/DI/SDA/MOSI/PB1), MOSI.1
unnamed: BUCK_BYPAS.1, J1.3, U$26.IN_+VE_P$1 (P_IN_+VE)
unnamed: 5VADJUST1.1, BUCK_BYPAS.2, U$26.OUT_+VE_P$3 (P_OUT_+VE)
unnamed: MLF1.12 (-RESET/PC3), RST.1
unnamed: MLF1.14 (ADC10/SCL/USCK/XCK1/PC1), SCK.1
unnamed: MISO.1, MLF1.17 (ADC7/MISO/TXD1/DO/PB2)
unnamed: I2C_7.P4 (4), U2.19 (SDA7)
unnamed: I2C_0.P4 (4), U2.4 (SDA0)
unnamed: I2C_0.P3 (3), U2.5 (SCL0)
unnamed: I2C_1.P4 (4), U2.6 (SDA1)
unnamed: MLF1.16 (ADC8/OC1A/PB3), PB3.1
unnamed: I2C_1.P3 (3), U2.7 (SCL1)
unnamed: I2C_2.P4 (4), U2.8 (SDA2)
unnamed: I2C_6.P4 (4), U2.17 (SDA6)
unnamed: I2C_5.P4 (4), U2.15 (SDA5)
unnamed: I2C_4.P4 (4), U2.13 (SDA4)
unnamed: I2C_3.P4 (4), U2.10 (SDA3)
unnamed: MLF1.19 (PB0/TXD0/ADC5), TX.1
unnamed: MLF1.20 (PA7/RXD0/ADC4), RX.1
unnamed: Q6.2 (S), R14.2, SV1.4, U$34.37 (IO23), U$34.IO23
RESET: Q6.3 (D), R16.2, U2.3 (#RESET)
SCL3V1: Q5.2 (S), R10.2, SV1.6, U$34.36 (IO22), U$34.IO22
SDA3V2: Q4.2 (S), R7.2, SV1.12, U$34.33 (IO21), U$34.IO21
VCC: I2C_MSTR.P2 (VCC), R2.2, R5.2

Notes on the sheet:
Problems - 01) ESP-32 DevKitC board widths are inconsistant. A new footprint would be better to include pin widths of 25.4 and 22.86 to cater for the two likely variants 02) R12 (reset) may not be necessary due to the pull-up on the 5v side of the MOSFET
This chip was only added for soldering practise

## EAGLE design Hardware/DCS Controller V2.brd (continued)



Board: 2 copper layers, 100.0 x 50.0 mm, 36 parts (2 on the bottom side), 67 nets.

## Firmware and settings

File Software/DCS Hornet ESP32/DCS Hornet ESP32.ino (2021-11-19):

/*
*  This sketch is the first iteration of the WiFi DCS F/A-18C cockpit controller based on the ESP32
*
*  requires fixed ESP32 I2C files from https://github.com/stickbreaker/arduino-esp32/releases 
*
* * * * * * * * * * * * * * * * * * * * * * * * * * * * * * * * * * * * * * * * * * * * * * * * * * * 
*
*  On first running, a wireless hotspot (SSID "BlueFinBima UFC" PW "bluefinbima") and you connect to the
*  WiFi configuration menu by pointing your browser to http://192.168.4.1/config if connecting to the hotspot
*  does not take you to the config screen automatically.
* 
*/

#include "FA18CkeyMappings.h"         // Key mappings for all of the aircraft supported by the UFC
#include "FA18CufcDisplay.h"		  // F/A-18C UFC Display function
#include <arduino.h>
#include <U8g2lib.h>                  // Graphics for the OLED graphic display https://www.arduino.cc/reference/en/libraries/u8g2/
#include <WiFi.h>					  // ESP32 wireless code
#include <AsyncUDP.h>				  // Use async UDP library on ESP32
#include "driver/gpio.h"    
#include <Wire.h>                     // This is needed for i2c communications
#include <OLED_I2C.h>                 // Library for the OLED display without serial board 4-bit
#include "RotaryEncoderAdvanced.h"    // enjoyneering Rotary Encoder functions https://github.com/enjoyneering/RotaryEncoder
#include "RotaryEncoderAdvanced.cpp"  //for some reason linker can't find the *.cpp :(
#if __has_include("WiFiInfo.h")
#include "WiFiInfo.h"                 // Personal Wifi information
#endif
#if __has_include("Personal.h")
#include "Personal.h"                //  Used to denote personal variations from the official schematics in the project
#endif
#include <DNSServer.h>				// https://github.com/prampec/IotWebConf
#include <WebServer.h>				// https://github.com/prampec/IotWebConf
#include <IotWebConf.h>				// https://github.com/prampec/IotWebConf
#include <time.h>	

const char* ntpServer = "pool.ntp.org";
const long  gmtOffset_sec = 0;
const int   daylightOffset_sec = 3600;
struct tm timeinfo;
bool ufc_Idle = true;
long lastUFCActivityTime = 0;

#define CONFIG_VERSION "UFC001"
const char apName[] = "BlueFinBima UFC";
const char wifiInitialApPassword[] = "bluefinbima";
// -- Callback method declarations.
void iotWebConfConfigSaved();
boolean htmlFormValidator();

DNSServer dnsServer;
WebServer server(80);

#define STRING_LEN 16
IPAddress ipAddress;
IPAddress gateway;
IPAddress netmask;
char ipAddressValue[STRING_LEN];
char gatewayValue[STRING_LEN];
char netmaskValue[STRING_LEN];

IotWebConf iotWebConf(apName, &dnsServer, &server, wifiInitialApPassword, CONFIG_VERSION);
IotWebConfParameter ipAddressParam = IotWebConfParameter("IP address", "ipAddress", ipAddressValue, STRING_LEN, "text", NULL, "10.1.1.48");
IotWebConfParameter gatewayParam = IotWebConfParameter("Gateway", "gateway", gatewayValue, STRING_LEN, "text", NULL, "10.1.1.1");
IotWebConfParameter netmaskParam = IotWebConfParameter("Subnet mask", "netmask", netmaskValue, STRING_LEN, "text", NULL, "255.255.255.0");


// WiFi network name and password:
#ifdef WIFISSID
const char * networkName = WIFISSID;
const char * networkPswd = WIFIPW;
#elif
const char * networkName = "YourSSID";
const char * networkPswd = "Your WiFi Password";
#endif
//IP address to send UDP data to:
// either use the ip address of the server or 
// a network broadcast address
const char * udpAddress = "0.0.0.0";
const uint16_t udpPort = 9089;
IPAddress ip;
IPAddress ipRemote;
uint16_t portRemote = 0;
#define MAXPACKETSIZE 600

AsyncUDP udp;

// the Export send code does a >576 test before sending so the max data is going to be 576 + length of the longest command
char packetBuffer[MAXPACKETSIZE];		// network buffer to hold incoming packet
volatile int packetLen = 0;				// length of the data in the packet buffer 
char cmdBuffer[MAXPACKETSIZE];			// this is a buffer to hold a single command (there can be long text command values
char cmdValStrBuffer[32];				// Used for the conversion of the comand value
char replyBuffer[32];					// a string to send back
bool connected = false;					// Indicate if we are currently connected
										// Constructor for the UDP library class
unsigned long time1 = 0;                // Used to calculate loop delay
unsigned long time2 = 0;                // Used to calculate loop delay
										//
										// These are the response which checking keys can return
#define SWITCHNONE 0 
#define SWITCHWAIT 1
#define SWITCHSET 2
#define SWITCHALREADYDONE 3

//
//
//  i2c Constants
//
//  This section is the master list of all of the 12c devices in use in the project
//
const uint8_t i2c_addr_other = 0x78;     // dummy i2c address for the simulated HT16K33 used for oddly connected switches
const uint8_t i2c_addr_ufc_expander = 0x20;  // i2c expander on the F/A-18C UFC which controls the ODU's and main display
const uint8_t i2c_addr_ufc_mux = 0x70;       // i2c multiplexer on the F/A-18C UFC
const uint8_t i2c_addr_ufc = 0x71;       // i2c address of the HT16K33 used for the F/A-18C up front controller keys, illuminations, Cues & Comm Channel Displays (This has no indicators)
const uint8_t i2c_addr_landingGear = 0x72;     // i2c address of the HT16K33 used for the RHS switches (This is a general switch board)
										//
										//
										//
										// List here the highest and lowest i2c address for the HT16K33 chips.  These are managed to 
										// ensure that only the correct number of buffers are allocated.
#define LOWEST_I2C_ADDR 0x71            //this is the address of the lowest i2c HT16K33
#define HIGHEST_I2C_ADDR 0x74           //this is the address of the highest i2c HT16K33 +2
										//

bool readkeys = false;

//  HT16K33 Constants
//
// Various HT16K33 constants etc 
#define HT16K33_BLINK_CMD 0x80
#define HT16K33_BLINK_DISPLAYON 0x01
#define HT16K33_BLINK_OFF 0
#define HT16K33_BLINK_2HZ  1
#define HT16K33_BLINK_1HZ  2
#define HT16K33_BLINK_HALFHZ  3
#define HT16K33_CMD_BRIGHTNESS 0xE0
#define HT16K33_KEY_RAM_ADDR 0x40        //this is the six bytes which hold the keys which have been pressed
#define HT16K33_KEY_INTERUPT_ADDR 0x60   
#define HT16K33_KEY_ROWINT_ADDR 0xA0   
//
#define HT16K33_DEFAULT_BRIGHTNESS 0x15

//
uint16_t displaybuffer[HIGHEST_I2C_ADDR - LOWEST_I2C_ADDR][8];
bool HT16K33Push[HIGHEST_I2C_ADDR - LOWEST_I2C_ADDR]; // Used to force a write to a particular HT16K33 chip
int16_t  kk[3];            // this is the integer array to contain a keycode and value pair
int16_t  keystack[3][64];  // this is the FIFO stack of key presses, key values and devices
uint8_t  keystackNext;     // this is the next keypress to be processed
uint8_t  keystackFree;     // this is the first free slot in the keystack 
uint8_t keys[HIGHEST_I2C_ADDR - LOWEST_I2C_ADDR][6];
uint8_t lastkeys[HIGHEST_I2C_ADDR - LOWEST_I2C_ADDR][6];
unsigned long switchLastIntTime[HIGHEST_I2C_ADDR - LOWEST_I2C_ADDR + 1];  // this is the time when the last interrupt was seen from the device
//void connectToWiFi(const char *, const char *);

uint8_t ufcType = 0;		// Indicator to support different aircraft types.  Default is F/A-18C

#define NUMBEROFINDICATORS 10
const uint8_t generalIndicators[3][NUMBEROFINDICATORS] = {  // these are the LED positions for various indicators * * * Do Not Change Order without addjusting cmdOffset usage
	{
	12,12,                // Flaps Lights 
	14,14,14,             // Gear Ready Lights x3 (L,N,R) 
	13,13,13,      		  // Gear amber lights x3 (launch Bar, SpeedBrake , hook)     
	15,					  // Landing Gear Lollipop Light
	11					  // Landing Gear Lollipop Light
	},
	{
	6,4,
	4,6,5,
	4,6,5,
	4,
	6
	},
	{
	i2c_addr_landingGear,i2c_addr_landingGear,i2c_addr_landingGear,i2c_addr_landingGear,
	i2c_addr_landingGear,i2c_addr_landingGear,i2c_addr_landingGear,i2c_addr_landingGear,
	i2c_addr_landingGear,
	i2c_addr_landingGear
	}
};
const uint8_t generalIndicatorsAV8B[3][NUMBEROFINDICATORS] = {  // these are the LED positions for various indicators * * * Do Not Change Order without addjusting cmdOffset usage
	{
    13,14,13,14, 
	13,14,12,12,  
	15,					  // Landing Gear Lollipop Light
	11					  // Landing Gear Lollipop Light
	},
	{
	6,6,4,4,
	5,5,6,4,
	4,
	6
	},
	{
	i2c_addr_landingGear,i2c_addr_landingGear,i2c_addr_landingGear,i2c_addr_landingGear,
	i2c_addr_landingGear,i2c_addr_landingGear,i2c_addr_landingGear,i2c_addr_landingGear,
	i2c_addr_landingGear,
	i2c_addr_landingGear
	}
};


#define MAXENCODERS 16
float EncoderValues[MAXENCODERS];            // This array holds the values of the encoders which get used when the encoders are reporting as if they are keys
									//
char displayBuffer[21];
char i2cBuffer[128];

#define LED_ON 1
#define LED_OFF 0
//
// General String variables
String command;
String value;
//
int i = 0;
int j = 0;
//
bool commandsReady = false;

//
// New devices for the Hornet

FA18CufcDisplay UFCDisplay(i2c_addr_ufc_expander);

// UFC status OLED
U8G2_SSD1306_128X32_UNIVISION_F_HW_I2C oledUFCstatus(U8G2_R2);  //  Rotate display by 180 deg
char oledUFCstatusBuffer[32];

//These are the character displays for the 16 segment channel displays on the UFC
//
//			   LED segment values
//           
//          , 0x0001,       , 0x0002,
//    0x0080, 0x0100, 0x0200, 0x0400, 0x0004
//		    , 0x8000,       , 0x0800,
//    0x0040, 0x4000, 0x2000, 0x1000, 0x0008
//          , 0x0020,       , 0x0010,
//
const uint16_t UFCchannelNumbers[29] = {
	0x0000, 0x000C, 0x2816, 0x081E, 
	0x0A0C, 0x0A1A, 0x2A18, 0x000E, 
	0x2A1E, 0x0A0E, 0x22DE, 0x00CC, 
	0x28D6, 0x08DE, 0x0ACC, 0x0ADA,
	0x2AD8, 0x00CE, 0x2ADE, 0x0ACE, 
	0xA27F, 0x08FB, 0x05CC, 0x00F3, 
	0x88BB, 0x0503, 0x5030, 0xAA00,
	0x8800								// final 2 characters are "+" and "-"
};

// These are the addresses of the sets of two UFCcueing LEDs on the UFC
const uint8_t UFCcueing[5] = { 1,3,5,7,9};

// Onboard Encoders
volatile byte encInt = 0;  // set in the ISR with a bit for a change to each of the encoders.

#define D1 22  
#define D2 21  
#define D3 18  
#define D4 19  
#define D5 16  
#define D6 17  
#define D7 5  
#define D8 4  
#define D9 23  
#define D10 0

void IRAM_ATTR UFCBrightnessISR();
void IRAM_ATTR UFCVolume1ISR();
void IRAM_ATTR UFCVolume2ISR();
void IRAM_ATTR UFCChannel1ISR();
void IRAM_ATTR UFCChannel2ISR();

#ifndef PERSONAL
RotaryEncoderAdvanced <float> UFCChannel1(12, 13, 0xff, 0.05, 0, 1);
RotaryEncoderAdvanced <float> UFCChannel2(27, 26, 0xff, 0.05, 0, 1);
RotaryEncoderAdvanced <float> UFCBrightness(17, 16, 0xff, 0.1, 0, 1);
RotaryEncoderAdvanced <float> UFCVolume1(5, 4, 0xff, 0.1, 0, 1);
RotaryEncoderAdvanced <float> UFCVolume2(19, 18, 0xff, 0.1, 0, 1);
#else
// Change of wiring on 001
RotaryEncoderAdvanced <float> UFCChannel1(25, 15, 0xff, 0.05, 0, 1);
RotaryEncoderAdvanced <float> UFCChannel2(27, 26, 0xff, 0.05, 0, 1);
RotaryEncoderAdvanced <float> UFCBrightness(17, 16, 0xff, 0.1, 0, 1);
RotaryEncoderAdvanced <float> UFCVolume1(5, 4, 0xff, 0.1, 0, 1);
RotaryEncoderAdvanced <float> UFCVolume2(19, 18, 0xff, 0.1, 0, 1);
#endif // PERSONAL
float UFCBrightnessVal;
float UFCVolume1Val;
float UFCVolume2Val;
float UFCChannel1Val;
float UFCChannel2Val;
unsigned long encChannel1Time;
unsigned long encChannel2Time;

// use first channel of 16 channels (started from zero)
#define DLG2416_CHANNEL_0     0
#define ENCODER_LED_CHANNEL_1 1
// use 13 bit precission for LEDC timer
#define DLG2416_TIMER_13_BIT  13
// use 5000 Hz as a LEDC base frequency
#define DLG2416_BASE_FREQ     5000
#define DLG2416_BLANK_PIN     14
//

void setup() {
	// Set the reset pin of the MUX to low
	pinMode(23, OUTPUT);
	digitalWrite(23, HIGH);

	Serial.begin(115200);  // Initilize hardware serial:
	Serial.println("\n");
	//Wire.begin(D2, D1, 25000U);       //  sda = gpio21/D2   scl=gpio22/D1
	Wire.begin(D2, D1);                 //  sda = gpio21/D2   scl=gpio22/D1
	Wire.endTransmission();             // try to send a stop bit to see if this can wake up a sleeping 12c bus
	//Wire.setClock(50000);
	for (uint8_t i = 0; i<HIGHEST_I2C_ADDR - LOWEST_I2C_ADDR; i++) HT16K33Push[i] = false;   // This flag is used to indicate that the LED buffer needs to be written to the HT16K33
	for (uint8_t i = LOWEST_I2C_ADDR; i< HIGHEST_I2C_ADDR; i++) initHT16K33(i);              // set up the HT16K33 i2c chips
																						   //initialise the key buffers  
	UFCDisplay.clear();
	oledUFCstatus.begin();                            // Initialise the status OLED on the UFC
	oledUFCMsg(10, 7, "F/A-18C");
	oledUFCstatus.drawStr(10, 15, "UFC V0.5");
	oledUFCstatus.sendBuffer();

	testI2CScanner();

	muxSelect(0); // Allow 0x72 to be referenced on channel 0
	for (uint8_t i = 0; i<HIGHEST_I2C_ADDR - LOWEST_I2C_ADDR; i++) {
		initHT16K33(LOWEST_I2C_ADDR + i);
		for (uint8_t j = 0; j<6; j++) {
			keys[i][j] = (uint8_t)0;
		}
	}
	muxSelect(8); // Turn off all external channels

	/* Debug
	for(uint8_t ii = LOWEST_I2C_ADDR;ii<HIGHEST_I2C_ADDR+1;ii++){  //this obtains a print of all the key ram
	getDefaultKeys(ii);
	}
	*/

	//  Read the switch data to see if user is attempting to force a network reconfiguration
	//  We check if I/P or ODU1 buttons are depressed to indicate reconfiguration is needed.
	getSwitchData(i2c_addr_ufc);
	bool reconfig = false;
	int accessPointTimeOut = 1000;
	if (keys[i2c_addr_ufc - LOWEST_I2C_ADDR][2] == 0x01 || keys[i2c_addr_ufc - LOWEST_I2C_ADDR][3] == 0x01) {
		reconfig = true;
		accessPointTimeOut = 120000;  // Set access point timeout to 2 mins.
		Serial.println("Reconfiguration has been requested");
	}
	// Setup timer and attach timer to a GPIO pin to allow PWM for the DLG2416 displays
	ledcSetup(DLG2416_CHANNEL_0, DLG2416_BASE_FREQ, DLG2416_TIMER_13_BIT);
	ledcAttachPin(DLG2416_BLANK_PIN, DLG2416_CHANNEL_0);
	DLG2416_Brightness(DLG2416_CHANNEL_0, 255);

	testAll();
	//
	// Get a connection, or configure the AP and then get a connection
	//
	if(reconfig) configUFCMessage();

	iotWebConf.init();
	iotWebConf.setApTimeoutMs(accessPointTimeOut);  // for a device which is already configured, this will wait for 1s for the AP to be connected to
	iotWebConf.addParameter(&ipAddressParam);
	iotWebConf.addParameter(&gatewayParam);
	iotWebConf.addParameter(&netmaskParam);
	iotWebConf.setConfigSavedCallback(&iotWebConfConfigSaved);
	iotWebConf.setFormValidator(&htmlFormValidator);
	iotWebConf.setApConnectionHandler(&connectAp);
	iotWebConf.setWifiConnectionHandler(&connectWifi);

	// -- Set up required URL handlers on the web server.
	server.on("/", handleRoot);
	server.on("/config", [] { iotWebConf.handleConfig(); });
	server.onNotFound([]() { iotWebConf.handleNotFound(); });


	//Connect to the WiFi network
	//connectToWiFi(networkName, networkPswd);

	while (WiFi.status() != WL_CONNECTED) {
		delay(1000);
		iotWebConf.doLoop();
	}
	ip = WiFi.localIP();
	Serial.println("WiFi connected");
	Serial.print("IP address: ");
	Serial.println(ip);

	configTime(gmtOffset_sec, daylightOffset_sec, ntpServer);  // get time info before starting the UDP Listener

	//WiFi.onEvent(WiFiEvent);
	startUDPListener();

	oledUFCMsg(0,31,"Connected");
	sprintf(oledUFCstatusBuffer, "%d.%d.%d.%d:%d", ip[0], ip[1], ip[2], ip[3], udpPort);
	oledUFCMsg(0, 31, oledUFCstatusBuffer);
	oledUFCstatus.drawStr(24, 7, "DCS F/A-18C");
	oledUFCstatus.sendBuffer();

	displayIP();

	muxSelect(0); // Allow 0x72 to be referenced on channel 0
	drawPixel(i2c_addr_landingGear, 15, 7, LED_ON); displayHT16K33(i2c_addr_landingGear);
	muxSelect(8);
	UFCBrightness.begin();
	UFCVolume1.begin();
	UFCVolume2.begin();
	UFCChannel1.begin();
	UFCChannel1.setValue(0.5);
	UFCChannel2.begin();
	UFCChannel2.setValue(0.5);
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
void loop() {
	//if (!connected) {
	//	iotWebConf.doLoop();
	//}
	if (millis() - lastUFCActivityTime > 1800000 | lastUFCActivityTime == 0) {
		ufc_Idle = true;
		idleFunctions();
	}
	if (readSwitches(i2c_addr_ufc) | readSwitches(i2c_addr_landingGear) | ProcessEncoders()) {
		// one or more keys have been placed onto the keystack and need to be processed
		while (keystackCount()>0) {
			//      breath = false;
			keystackPop(kk);
			//  Now send the key info to the serial port
			//  This is done in multiple prints to avoid the use of a string  
			//!specialActions(kk);
			sprintf(replyBuffer, "C%d,%d,\0", kk[2], kk[0]);
			//Serial.println(replyBuffer);
			// note about values:
			// Generally the decade of the value indicates the number of switchcodes (not positions) the switch has.
			// a code in the 40's has 5 switchcodes, in the 10's has 2 switchcodes, in the 0's has 1 switchcode.
			// A three position toggle will have only two switchcodes because the centre position is inferred.
			// The reason for this is to allow us to infer from the value in the table, how many switch codes are
			// associated with the real switch.
			// All of the switchcodes for a real switch are expected to be contiguous in the array.
			// In normal operation, communicating a changed state does not care about the number of switchcodes there are.
			// 
			char tbuf[16];
			switch (kk[1]) {
			case 0:
			case 1:
			case -1:
				// unfortunately the float processing in sprintf for ESP8266 does not work!
				sprintf(tbuf, "%d.00\0", kk[1]);
				break;
			case 10:
			case 11:
			case 12:
				// this handles the tumbler
				sprintf(tbuf, "0.%d0\0", kk[1] - 10);
				break;
			case 40:
			case 41:
			case 42:
			case 43:
			case 44:
				// this handles the rotary switch  
				sprintf(tbuf, "0.%d0\0", kk[1] - 40);
				break;
			case 50:
			case 51:
			case 52:
			case 53:
			case 54:
			case 55:
			case 56:
			case 57:
			case 58:
			case 59:
				// this handles the real encoders which have a float for their value
				// Unfortunately the ESP8266 sprintf does not work for floats due to a bug :-(
				// The value minus 50 is the index into the float array which contains the 
				// encoder value.
				//Serial.println(EncoderValues[kk[1] - 50], DEC);
				dtostrf(EncoderValues[kk[1] - 50], 2, 2, &tbuf[0]);  // this is needed because of the ESP8266 sprintf problem
				EncoderValues[kk[1] - 50] = 0;  // once we've sent the float, set it to zero.
				break;
			default:
				sprintf(tbuf, "%d.00\0", kk[1]);
				break;
			}
			strncat(replyBuffer, tbuf, strlen(tbuf));
			processOutput(replyBuffer);
		}
	}
	yield();
	udpCheck();
	flushHT16K33();
}
/// <summary>Handles the incoming network data</summary>
/// <remarks>ESP32 handles network data asynchronously</remarks>
void udpCheck(void) {
	// This routine is to handle the incoming network data
	//
	// Only Receive data when connected

	if (packetLen > 0) {
		if (ufc_Idle) {
			UFCDisplay.clear();
			displayClear(i2c_addr_ufc);
		}
		ufc_Idle = false;
		lastUFCActivityTime = millis();
		parseCmdPacket(packetBuffer, packetLen);
		packetLen = 0;  // free up the buffer for more data
	}
	if (commandsReady) {
		if (ufc_Idle) {
			UFCDisplay.clear();
			displayClear(i2c_addr_ufc);
		}
		ufc_Idle = false;
		lastUFCActivityTime = millis();
		processOutput(replyBuffer);
	}

}
void parseCmdPacket(char * packetBuffer, int packetLen) {
	for (uint16_t ii = 0; ii<packetLen; ii++) {
		if (packetBuffer[ii] == '*') {  // this removes the SIMID (4 bytes) from the start of the packet
			memcpy(packetBuffer, &packetBuffer[ii + 1], packetLen - ii);
			packetLen = packetLen - ii - 1;
			ii = packetLen;
		}
	}

	for (uint16_t ii = 0; ii<packetLen; ii++) {
		if (packetBuffer[ii] == ':') {
			memcpy(cmdBuffer, packetBuffer, ii);  // move the command into the command buffer
			cmdBuffer[ii] = '\0';
			memcpy(packetBuffer, &packetBuffer[ii + 1], packetLen - ii);  // shift the remaining contents to the start of the buffer
			packetLen = packetLen - ii - 1;
			ii = 0;
			processCmd(cmdBuffer);
		}
		else {
			if (ii == packetLen - 1) {
				memcpy(cmdBuffer, packetBuffer, ii + 1);  // move the command into the command buffer when it wasn't terminated by a :
				cmdBuffer[ii + 1] = '\0';
				packetLen = packetLen - ii;
				ii = packetLen + 1;
				processCmd(cmdBuffer);
			}
		}
	}
}
uint16_t getCmd(char * cmdBuffer) {
	//  This returns the command code from the command buffer ie the bit before the =
	char cmdCodeBuffer[5];
	int cmdLen = strlen(cmdBuffer);
	for (uint16_t ii = 0; ii<cmdLen; ii++) {
		if (cmdBuffer[ii] == '=') {
			memcpy(cmdCodeBuffer, cmdBuffer, ii);  // move the command code into its own string
			cmdCodeBuffer[ii] = '\0';
			return(atoi(cmdCodeBuffer));
		}
	}
	return(9999);
}
float getCmdValfloat(char * cmdBuffer) {
	// This returns the command value if it is a float value, ie the bit after the equals.
	char cmdValBuffer[10];
	int cmdLen = strlen(cmdBuffer);
	for (uint16_t ii = 0; ii<cmdLen; ii++) {
		if (cmdBuffer[ii] == '=') {
			memcpy(cmdValBuffer, &cmdBuffer[ii + 1], cmdLen - ii);  // move the command code into its own string
			cmdValBuffer[cmdLen - ii] = '\0';
			return(atof(cmdValBuffer));
		}
	}
	return(0.000001);
}
int getCmdValint(char * cmdBuffer) {
	// This returns the command value if it is intended to be an integer value, ie the bit after the equals.
	// The input still appears as a floating point number and is cast (which can have problems) on the return.
	char cmdValBuffer[10];
	int cmdLen = strlen(cmdBuffer);
	for (uint16_t ii = 0; ii<cmdLen; ii++) {
		if (cmdBuffer[ii] == '=') {
			memcpy(cmdValBuffer, &cmdBuffer[ii + 1], cmdLen - ii);  // move the command code into its own string
			cmdValBuffer[cmdLen - ii] = '\0';
			return((int)atof(cmdValBuffer));
		}
	}
	return(0);
}
char * getCmdValStr(char * cmdBuffer) {
	// This returns the command value as a string, ie the bit after the equals.
	int cmdLen = strlen(cmdBuffer);
	for (uint16_t ii = 0; ii<cmdLen; ii++) {
		if (cmdBuffer[ii] == '=') {
			memcpy(cmdValStrBuffer, &cmdBuffer[ii + 1], cmdLen - ii);  // move the command code into its own string
			 if (cmdBuffer[ii + 1] == '_')
			{
				cmdBuffer[ii + 1] = '-';
			}
			cmdValStrBuffer[cmdLen - ii] = '\0';
			return(cmdValStrBuffer);
		}
	}
	return("\0");
}
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

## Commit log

2019-03-25 Initial Drop of S/W, H/W, & 3D Models
    This is the first drop of code and files for the Hardware UFC I use with DCS World.
    [DCS Controller V2 BOM.csv, DCS Controller V2.brd, DCS Controller V2.sch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]
2019-03-26 Production STLs Added
    UFC Back, Front and Facia STLs added which were the ones I used and printed in PET-G. Also included the keycap mitre I used to cut the keycaps down to size with a razor saw.
    [Comm Channel Selector.stl, Hornet UFC Back.stl, Hornet UFC Facia.stl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]
2020-08-23 Addition of new laser cut parts for the enclosure
    Changes to use 3mm black acrylic to create the enclosure.
    [Hornet UFC 020 Test 3 v14.step, Hornet UFC 020 Test 3 v14.stl, Hornet UFC Back.stl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]
2020-08-31 Added missing FA18CufcDisplay. Changed to mask left digit instead of right on the primary dispaly Network configuration using IotWebConf Change UDP port to 9089 Removed encoder debugging
    [DCS Hornet ESP32.ino]
2020-10-09 Schematic PDF and updated control program
    Control program improvement to allow IP setting at set-up.
2020-10-13 More Comments and Function Prototypes
    A little more comments based on conversations about the included libraries.
    Created function prototypes for the ISR's which seem to be needed for the compiler used by the Arduino IDE.
2020-10-28 Changes to code for Comm1 and DCS scripting
    [Hornet UFC 020a BOM.csv]
2020-10-29 Corrections for incorrect parts in BoM and labeled on Schematic
    [Hornet UFC 020a BOM.csv, Hornet UFC 020a.brd, Hornet UFC 020a.sch]
2020-11-03 Implemented mechanism to elect to reconfigure via access point (for 2 minutes) if the UFC is reset with either the I/P button or ODU1 button pressed.
    [DCS Hornet ESP32.ino]
2020-11-11 Add STLs for MX Keycaps
    [Hornet UFC Round Key.stl, Hornet UFC Square Key.stl]
2020-11-19 Adjusted 3D models dor ODU keys and Comm Selector
    [Comm Channel Selector Knurled.stl, Hornet UFC Round Key large.stl]
2021-07-02 Pre-V3 work and Readme update
    [Comm Channel Display.brd, Comm Channel Display.sch, Hornet ODU.brd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]

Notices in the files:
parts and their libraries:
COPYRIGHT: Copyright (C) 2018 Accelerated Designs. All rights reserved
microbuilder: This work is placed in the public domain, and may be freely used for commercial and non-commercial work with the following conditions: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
